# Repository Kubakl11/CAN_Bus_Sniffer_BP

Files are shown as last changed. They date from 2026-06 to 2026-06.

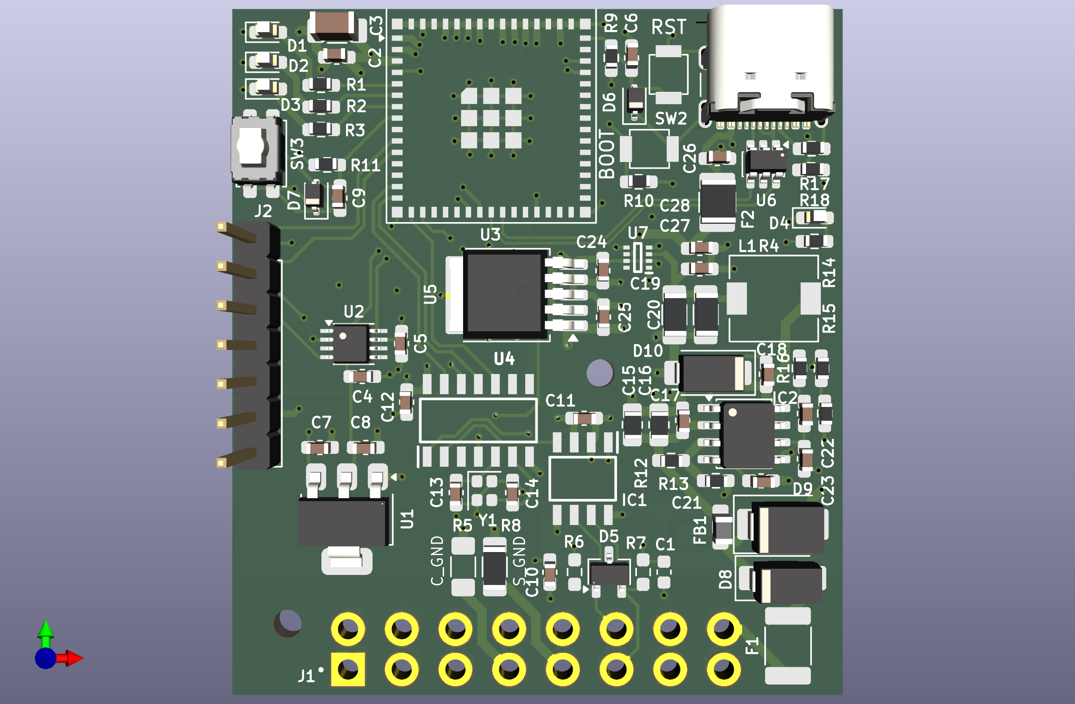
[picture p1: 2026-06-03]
pcb-design/Images/CanBus_Sniffer_v1_Front.png

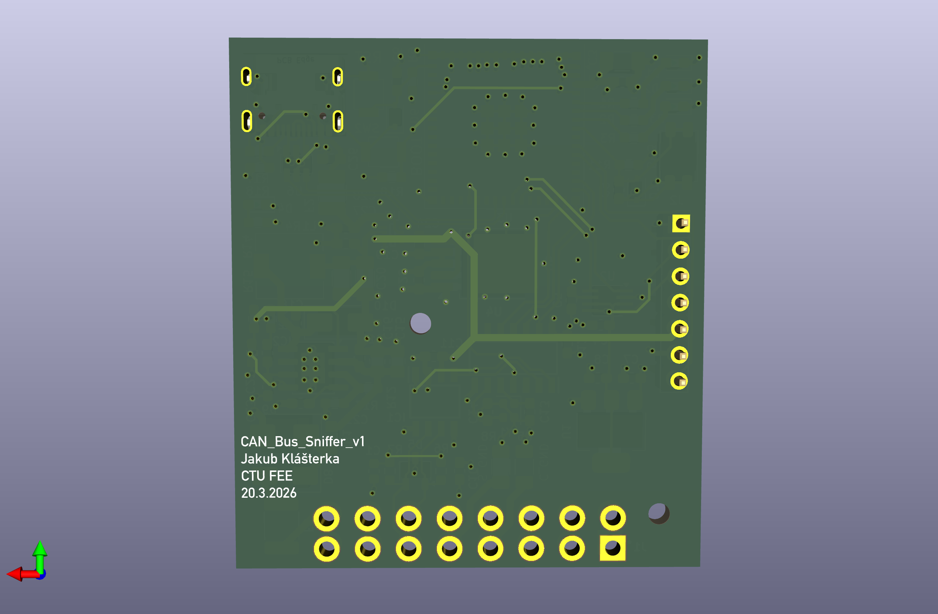
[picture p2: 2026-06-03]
pcb-design/Images/CanBus_Sniffer_v1_Back.png

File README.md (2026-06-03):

# CAN Bus Sniffer — Bachelor Thesis - Jakub Klášterka

> **Design and Implementation of a System for CAN Bus Data Analysis in Automotive Monitoring**
>
> Czech Technical University in Prague · Faculty of Electrical Engineering · 2026

---

## About

This project implements a **complete vehicle telemetry pipeline** — from reading OBD-II data off the car's CAN bus, through cellular transmission, to a live web dashboard.

```
   Vehicle CAN Bus (500 kbit/s)
       │
       ▼  OBD-II
  ┌─────────────────────────┐
  │  ESP32-S3 + MCP2518FD   │  ← Custom 4-layer PCB
  │  + A7670E LTE/GPS       │
  └────────┬────────────────┘
           │  HTTPS (LTE)
           ▼
  ┌─────────────────────────┐
  │  Flask Backend           │  ← Railway.app
  │  (REST API + SQLite)     │
  └────────┬────────────────┘
           │  fetch() @ 5 Hz
           ▼
  ┌─────────────────────────┐
  │  Web Dashboard           │  ← Chart.js + Leaflet
  │  (Vanilla HTML/CSS/JS)   │
  └─────────────────────────┘
```

---

## Hardware

| Component | Role |
|---|---|
| **ESP32-S3-MINI-1-N8** | Main MCU (dual-core, 240 MHz) |
| **MCP2518FD** | CAN controller (SPI, CAN 2.0B @ 500 kbit/s) |
| **ATA6563** | CAN transceiver (3.3 V logic / 5 V bus) |
| **SIMCom A7670E** | LTE Cat 1 modem + GNSS (GPS/GLONASS) |

PCB designed in **KiCad**,

---

## Firmware
- **CAN library:** ACAN2517FD
- **OBD-II:** PID discovery (SCAN) + cyclic reading (LOOP) at 150 ms
- **LTE:** AT command driver for A7670E — HTTPS POST with Bearer token + nonce
- **GPS:** NMEA parsing via `AT+CGNSSINFO`
- **WiFi:** SoftAP + captive portal for local configuration

## Backend

Flask app deployed on **Railway.app**.

| Endpoint | Method | Description |
|---|---|---|
| `/data` | `POST` | ESP sends OBD-II JSON (Bearer + nonce auth) |
| `/data` | `GET` | Dashboard reads latest telemetry |
| `/command` | `POST` | Queue command for ESP (SCAN / LOOP / STOP) |

**Security:** HTTPS · Bearer token · nonce replay protection

---

## Dashboard
Written using **HTML / CSS / JavaScript**

| Page | What it shows |
|---|---|
|  `dashboard.html` | Cockpit — gauges (RPM, speed), mini charts, alarms |
|  `vehicle-data.html` | Full PID table with live values |
|  `graphs.html` | Time-series charts (Chart.js) |
|  `alarms.html` | Configurable alarm thresholds |
|  `consumption.html` | Fuel consumption analytics |
|  `map.html` | Live GPS track (Leaflet + Mapbox) |
|  `diagnostic.html` | CAN frame builder, live monitor, UDS, serial console |

**Design:** Dark theme (navy + blue accent), JetBrains Mono for numerics, responsive layout.

`data.js` serves as the **single integration point** 

---

## Quick Start

```bash
# Firmware (PlatformIO)
pio run -e obd_reader -t upload
pio device monitor

# Backend (local)
pip install -r requirements.txt
flask run

# Dashboard
# Open dashboard.html with Live Server
```

---

## 📝 Thesis

Written in **LaTeX** using the `ctuthesis` template. The thesis covers a review of automotive communication buses (CAN, LIN, FlexRay, Ethernet), the OBD-II diagnostic standard, hardware design, firmware implementation, server architecture, and the web dashboard.

---

<p align="center">
  <sub>Jakub Klášterka · CTU FEE Prague · 2026</sub>
</p>

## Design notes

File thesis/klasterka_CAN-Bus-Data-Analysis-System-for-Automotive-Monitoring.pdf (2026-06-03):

## Czech Technical

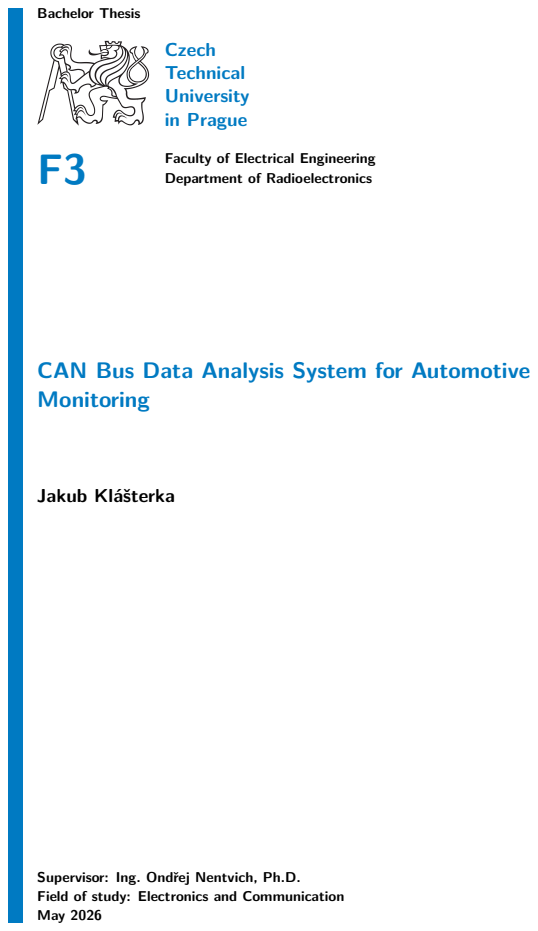
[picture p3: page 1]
Bachelor Thesis; University in Prague; Faculty of Electrical Engineering; Jakub Kláöterka

Department of Radioelectronics

CAN Bus Data Analysis System for Automotive
Monitoring

Supervisor: Ing. Ondej Nentvich, Ph.D.
Field of study: Electronics and Communication
May 2026

ii

ZADÁNÍ BAKALÁŘSKÉ PRÁCE

I. OSOBNÍ A STUDIJNÍ ÚDAJE

Systém analýzy dat ze sběrnice CAN pro monitorování automobilů

Název bakalářské práce anglicky:
CAN Bus Data Analysis System for Automotive Monitoring

Jméno a pracoviště vedoucí(ho) bakalářské práce:
Ing. Ondřej Nentvich, Ph.D. katedra radioelektroniky FEL

Jméno a pracoviště druhé(ho) vedoucí(ho) nebo konzultanta(ky) bakalářské práce:

Datum zadání bakalářské práce: 04.02.2026 | Termín odevzdání bakalářské práce: ___________
Platnost zadání bakalářské práce: 19.09.2027

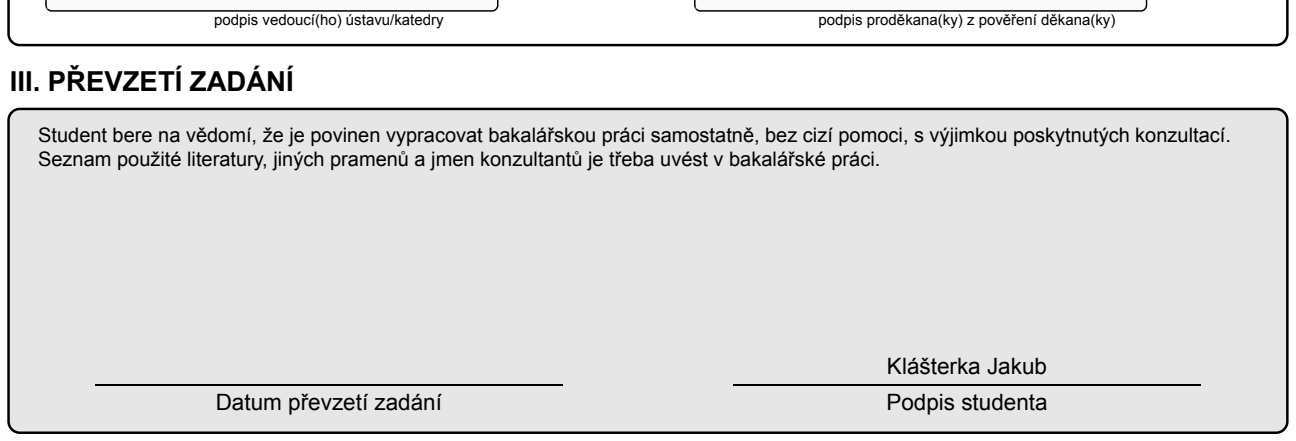
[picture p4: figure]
##SIGNATURE;FIELD;STEP1##; ##SIGNATURE;FIELD;STEP2##; podpis vedoucí(ho) ústavu/katedry; podpis proděkana(ky) z pověření děkana(ky); III. PŘEVZETÍ ZADÁNÍ; Klášterka Jakub; Datum převzetí zadání; Podpis studenta

Student bere na vědomí, že je povinen vypracovat bakalářskou práci samostatně, bez cizí pomoci, s výjimkou poskytnutých konzultací. Seznam použité literatury, jiných pramenů a jmen konzultantů je třeba uvést v bakalářské práci.

CVUT-CZ-ZBP-2015.1 | Strana 1 z 2 | © VUT v Praze, Design: VUT v Praze, VIC

ZADÁNÍ BAKALÁŘSKÉ PRÁCE

I. OSOBNÍ A STUDIJNÍ ÚDAJE

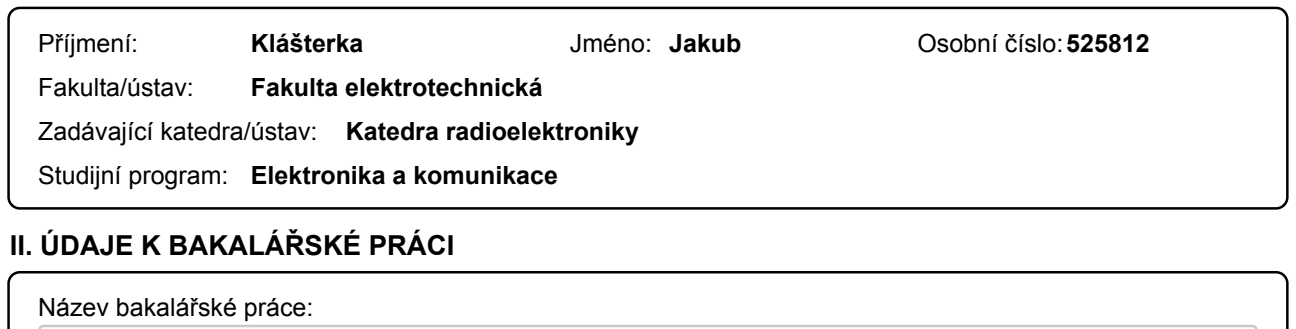
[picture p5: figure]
Příjmení:; Klášterka; Jméno:; Jakub; Osobní číslo:; Fakulta/ústav:; Fakulta elektrotechnická; Zadávající katedra/ústav: Katedra radioelektroniky; Studijní program:; Elektronika a komunikace; II. ÚDAJE K BAKALÁŘSKÉ PRÁCI; Název bakalářské práce:

Systém analýzy dat ze sběrnice CAN pro monitorování automobilů

Název bakalářské práce anglicky:
CAN Bus Data Analysis System for Automotive Monitoring

Pokyny pro vypracování:
1) Perform research on commonly used communication buses in vehicles, focusing on the CAN bus and the OBD-II diagnostic standard. The research should cover the following areas:
- Overview of commonly used buses (e.g., CAN, LIN, FlexRay, MOST, Automotive Ethernet)
- OBD-II diagnostic standard and related protocols (especially ISO 15765 and SAE J1979)
- Description of the CAN 2.0A/B protocol
- Diagnostic services and vehicle operating values
2) Review existing devices for analyzing and recording data from the CAN bus.
3) Design a device capable of recording data from the CAN bus via the OBD-II diagnostic connector and storing this data in local or cloud storage.
4) Design a method for visualizing the acquired data using a graphical display or web interface, implemented either directly on the microcontroller or via remote storage. The visualization should include key vehicle diagnostic and operating data.
5) Analyze the security risks of the designed device and propose appropriate measures to ensure data protection and bus integrity.

Seznam doporučené literatury:
[1]PARET, Dominique. Multiplexed Networks for Embedded Systems: CAN, LIN, FlexRay, Safe-by-Wire.. John Wiley, 2007. ISBN 978-0-470-51170-1.
[2]KLEIDERMACHER, David a KLEIDERMACHER, Mike. Embedded systems security: practical methods for safe and secure software and systems development. Amsterdam: Elsevier, 2012. ISBN 978-0-12-386886-2.
[3] ZÁHLAVA, Vít. Návrh a konstrukce desek plošných spojů: principy a pravidla praktického návrhu. Praha: BEN - technická literatura, 2010. ISBN 978-80-7300-266-4.
[4] Mastering MQTT – Your Ultimate Tutorial for MQTT [online]. Available from: https://assets.emqx.com/resources/ebooks/Mastering%20MQTT-Your%20Ultimate%20Tutorial%20for%20MQTT.pdf
CVUT-CZ-ZBP-2015.1 | Strana 2 z 2 | © VUT v Praze, Design: VUT v Praze, VIC

FAKULTA ELEKTROTECHNICKÁ
FACULTY OF ELECTRICAL ENGINEERING Technická 2
166 27 Praha 6

### DECLARATION

I, the undersigned

Student's surname, given name(s): Kláterka Jakub
Personal number: | 525812
Programme name: | Electronics and Communications

hereby declare that the Bachelor’s Thesis titled

CAN Bus Data Analysis System for Automotive Monitoring

is my own independent work and that I have declared all sources of information used in accordance with the Methodological Guideline for adhering to ethical principles when elaborating an academic final thesis and the Framework Rules for the use of artificial intelligence at CTU for study and pedagogical purposes in Bachelor and continuing Masters studies.

I declare that I have used artificial intelligence tools during the preparation and writing of the final thesis.
I've verified the generated content. I confirm that I am aware that I am fully responsible for the content of the final thesis.
In Prague on 03.05.2026 | Jakub Kláterka | student's signature

vi

## Acknowledgements

I would like to thank my supervisor, Ing. Ondej Nentvich, Ph.D., for his invaluable guidance and continuous support throughout this thesis, often helping me outside of his regular working hours, including weekends. I am grateful for his empathy, knowledge, and eagerness to help with all the diculties encountered during the work.
I would also like to thank my external supervisor,
Ing. Ludmila Musalová Stoklasová, from the Technical Development Department at äkoda Auto, for her guidance and consultations.
Finally, I am grateful to my colleagues for their assistance and valuable advice while working on this Bachelor thesis.

## Podkování

Chtl bych velice podkovat svému vedoucímu, Ing. Ondeji Nentvichovi, Ph.D., za jeho odborné vedení a neustálou podporu v prbhu celé práce, i nad rámec jeho pracovních hodin a bhem víkend. Velmi si váûím jeho vstícnosti, odborn˝ch znalostí a ochoty pomoci pi eöení vöech obtíûí, s nimiû jsem se bhem její tvorby setkal.
Dále také dkuji své externí konzultantce, Ing. Ludmile Musalové Stoklasové z oddlení technického v˝voje spolenosti äkoda Auto, za její vedení a konzultace. Na závr dkuji sv˝m kolegm za pomoc a cenné rady pi tvorb této bakalá-ské práce.

vii

## Abstract

The Bachelor thesis focuses on developing a prototype of a diagnostic device for vehicle telematics which can monitor vehicle data in real time wirelessly on a web dashboard. The prototype device contains a custom-designed PCB with an ESP32-S3 microcontroller, a CAN FD controller, a SIMCom external LTE & GPS module, and a TPS54331 power supply.
The theoretical part contains a discussion of the OBD-II standards and specifications, and the CAN bus protocol architecture. A comparison of several dierent automotive communication buses, including FlexRay, LIN, and Automotive Ethernet, is provided as a foundation for understanding the automotive environment. There is also a marketing overview of existing diagnostic devices.
The practical part of the thesis demonstrates the custom PCB design of the device, firmware development, server setup, and the whole setup of the device, including LTE initialization, reading CAN messages, and providing steps for security measures and power management. It also describes the developed dashboard for the visualization of vehicle data and the validation of the acquired data. The thesis also oers an idea for future implementation of a diagnostic interface for flashing vehicle electronic control units.
Keywords: ESP32, CAN bus, OBD-II, automotive diagnostics, microcontroller, PCB design, web server, wireless technology
Supervisor:
Ing. Ondej Nentvich, Ph.D. Department of Radioelectronics, Faculty of Electrical Engineering, CTU Prague

## Abstrakt

Bakaláská práce se zamuje na v˝voj prototypu diagnostického zaízení, které dokáûe bezdrátov sledovat telematická data z vozidla a vizualizovat je pomocí webového rozhraní. Prototyp zahrnuje vlastní v˝voj desky ploön˝ch spoj s mikrokontrolérem ESP32-S3, CAN FD pevodníkem, externím LTE a GPS modulem SIMCom a napájecím zdrojem TPS54331. Teoretická ást se vnuje popisu standard a specifikací OBD-II a architektue protokolu CAN bus. Obsahuje také srovnání nkolika rzn˝ch komunikaních sbrnic ve vozidle, vetn FlexRay, LIN a Automotive Ethernet, jako základ pro pochopení prmyslov˝ch standard v automotive prostedí. Tato ást pináöí také trûní pehled existujících diagnostick˝ch zaízení.
Praktická ást popisuje návrh vlastní desky ploön˝ch spoj (DPS), v˝voj firmwaru, pípravu serveru a celkovou konfiguraci zaízení. Ta zahrnuje inicializaci LTE komunikace, vyítání zpráv ze sbrnice CAN, eöení softwarového zabezpe-ení a ízení spoteby energie. Dále je zde popsán v˝voj webového rozhraní pro vizualizaci namen˝ch dat a jejich validace. Práce také obsahuje moûnost budoucího rozöíení systému, spoívající v implementaci diagnostického rozhraní pro kódování elektronick˝ch ídicích jednotek.
Klíová slova: ESP32, sbrnice CAN, OBD-II, automobilová diagnostika, mikrokontrolér, návrh DPS, webov˝ server, bezdrátové technologie
Peklad názvu: Systém anal˝zy dat ze sbrnice CAN pro monitorování automobil

viii

## Contents

1 Introduction | 1
2 Theoretical Background | 3

2.1.1 History and Development . . . . 3 2.1.3 CAN Message Frame Structure 7 2.1.4 Reading and Decoding CAN

2.1.7 Typical ECUs in Vehicles . . . 14 2.1.8 Vehicle Network Architecture 14 2.1.9 Other Serial Buses in Vehicles 15 2.2.1 Overview and Standardization 18 2.2.2 OBD II Physical Connector . 19 2.3 Market Analysis of Existing

### 3 Design and Implementation of the

Device | 25

3.2.1 System Requirements and

3.3.3 CAN Controller Initialization 37

3.5.2 Local Wi-Fi Channel Security 45

3.6.2 Advanced Diagnostics Interface 48 3.7.1 End-to-End Transmission Test 49 3.7.2 Vehicle CAN Communication 51

4 Conclusion | 59
Bibliography | 61
A Component Datasheets | 65
B Complete Hardware Schematic 67
C Dashboard Screens | 71

Advanced Diagnostics Interface . . . . 78 D Test Drive Cockpit Photographs 83

Full-Throttle Acceleration to 100

E Repository Structure | 85
F Usage of Artificial Intelligence
tools | 87

ix

## Figures

2.1 CAN protocol architecture [20] .. 4 2.2 CAN bus topology architecture [4] 5 2.3 CAN bus dierential voltage
levels [5] | 6
2.4 CAN bus data frame [39] ....... 8 2.5 Cyclic Redundancy Check
diagram [21] | 9
2.6 Engine control unit [25]........ 13 2.7 ECUs topology in a car [27].... 13 2.8 ECU topology in vehicle [26] (bus layout is for illustration only) . . . . 14 2.9 OBD-II most common
locations [37] | 19
2.10 OBD-II Connector pinout [9].. 19 2.11 OBDeleven diagnostic
dongle [22] | 22
2.12 Generic ELM327 Bluetooth
adapter [17] | 23
2.13 SIZZAPP 4G GPS OBD
tracker [30] | 23
2.14 T-Mobile Smart Car OBD-II
device [15] | 24
3.1 CAN Bus Snier block diagram. 28 3.2 PCB layout of 4-layer board . . . 32 3.3 PCB layout showcasing the short high-frequency current loop path . 32
3.4 Main loop flow diagram | 36
3.5 Illustration photos of LTE antenna (left)[34] and GNSS antenna
(right)[36] | 40
3.6 Main Cockpit screen featuring live radial gauges and summary widgets 47 3.7 Recorded engine speed and vehicle
speed over the test session | 52
3.8 Throttle position, engine load, and
intake manifold pressure | 53
3.9 Coolant temperature, intake air temperature, ambient temperature,
and mass air flow rate | 53
3.10 Current draw during LTE module initialization and TCP payload
transmission | 54
3.11 System power consumption comparison between light sleep
and deep sleep modes | 55

C.1 Cockpit screen — live radial
gauges and summary widgets | 72
C.2 Vehicle Overview screen — PID
values and CSV export | 73
C.3 Live Graphs screen — time series
plots with zoom support | 74
C.4 Fuel Consumption screen — instantaneous and average counters 75 C.5 GPS Map screen — real-time vehicle position and route export . 76 C.6 Alarms screen — configurable
threshold limits | 77
C.7 Login screen — access restriction
for the diagnostics interface | 78
C.8 Diagnostic interface | 79
C.9 Serial Monitor | 80
C.10 UDS & Coding — ISO-TP
request builder | 80
C.11 Live monitor — real-time CAN
trac display | 81
D.1 Instrument cluster during
45 km h≠1 cruise | 83
D.2 Instrument cluster during full-throttle acceleration to
100 km h≠1 | 84
D.3 Instrument cluster during
50 km h≠1 steady-state cruise | 84
D.4 Instrument cluster during stationary high-RPM engine run . . 84

x

## Tables

2.1 Comparison of CAN Protocol
Variants | 12
2.2 Common OBD-II Standard PIDs 20 3.1 Key features of the
ESP32-S3-MINI-1 module (N8
variant) | 26
3.2 ESP32-S3 GPIO Pin Assignment
by Functional Block | 33
3.3 REST API Endpoints | 41
3.4 Dashboard Screen Overview . . . . 46 3.5 OBD-II parameters acquired
during the test drive | 51
3.6 Measured current draw per
operating phase | 57
3.7 Projected cellular data
consumption (4 h/day, n =9 PIDs). 58
E.1 Repository Structure | 85

xi

xii

## List of Abbreviations

Abbreviation | Description
ADAS | Advanced Driver Assistance Systems
ADC | Analog-to-Digital Converter
AP | Access Point
API | Application Programming Interface
AT | Attention (standard modem command prefix)
BOM | Bill of Materials
BCM | Body Control Module
CARB | California Air Resources Board
CGW | Central Gateway
CPU | Central Processing Unit
DNS | Domain Name System
DNP | Do Not Populate
DTC | Diagnostic Trouble Code
EMI | Electromagnetic Interference
EOBD | European On-Board Diagnostics
ESD | Electrostatic Discharge
FIFO | First-In, First-Out
FSM | Finite State Machine
GPIO | General-Purpose Input/Output
GPRS | General Packet Radio Service
GPS | Global Positioning System

xiii

Abbreviation | Description
GPX | GPS Exchange Format
GSM | Global System for Mobile Communications
HVAC | Heating, Ventilation, and Air Conditioning
IC | Inter-Integrated Circuit
IDE | Identifier Extension
ISO | International Organization for Standardization
ISO-TP | ISO Transport Protocol (ISO 15765-2)
ISR | Interrupt Service Routine
JSON | JavaScript Object Notation
LDO | Low-Dropout Regulator
LiDAR | Light Detection and Ranging
LTE | Long Term Evolution
MAC | Medium Access Control
MAF | Mass Air Flow
MAP | Manifold Absolute Pressure
OSI | Open Systems Interconnection
PCB | Printed Circuit Board
PID | Parameter Identifier
PWM | Pulse Width Modulation
QFN | Quad Flat No-leads
RAM | Random Access Memory
REST | Representational State Transfer
RMT | Remote Control Peripheral
ROM | Read-Only Memory
RTR | Remote Transmission Request
SAE | Society of Automotive Engineers
SIM | Subscriber Identity Module
SPI | Serial Peripheral Interface
SRAM | Static Random-Access Memory
SSID | Service Set Identifier

xiv

Abbreviation | Description
TDM | Time-Division Multiplexing
TLS | Transport Layer Security
TWAI | Two-Wire Automotive Interface
UART | Universal Asynchronous Receiver-Transmitter
UDS | Unified Diagnostic Services
UTP | Unshielded Twisted Pair
VAG | Volkswagen Aktiengesellschaft
WPA2-PSK | Wi-Fi Protected Access 2 — Pre-Shared Key

xv

## Chapter 1 Introduction

In the modern automotive industry, the usage of electronic control units (ECUs) and standardized communication protocols is essential for diagnostics and monitoring.
The On-Board Diagnostics II (OBD-II) standard, which has been required in all vehicles since 1996, provides a standard interface that allows access to vehicle data and diagnostic information through the use of the Controller Area Network (CAN) bus protocol. This bachelor thesis details the design of a diagnostic tool utilizing an ESP32 microcontroller to communicate with the OBD-II interface of vehicles utilizing the CAN bus protocol.
This diagnostic prototype allows real-time tracking of vehicle diagnostics and provides visualized data via a web-based dashboard.

## 1.1 Motivation

The motivation for creating this thesis is driven by several factors:

. Cost-eective diagnostics solutions for automotive monitoring.
. Learning and education — the need for modern electrical engineering

students to understand automotive communication protocols.

. Fleet management applications — providing real-time monitoring of ve-

hicle diagnostics, allowing better fleet maintenance and eciency.

## 1.2 Objectives

. Research the OBD-II standard and CAN bus protocol architecture.
. Design the hardware interface to connect the ESP32 to the CAN bus

communication.

. Implement software to read and convert raw data to specific vehicle

parameters.

. Develop a web-based dashboard to present remote data.

1

2

## Chapter 2 Theoretical Background

## 2.1 Controller Area Network

The Controller Area Network (CAN) is a serial communication bus designed for robust message exchange between Electronic Control Units (ECUs). It was initially engineered for the automotive environment, where the protocol uses a multi-master architecture in which devices broadcast messages to the entire network without a central host computer. This decentralized approach serves as the vehicle’s nervous system, enabling components such as engine management, transmission control, and safety systems to share sensor data in real time. While developed for combustion-engine vehicles, the protocol serves as the networking standard for electric vehicles, marine electronics, and industrial automation [6].

### 2.1.1 History and Development

In the early 1980s, the automotive industry faced a critical engineering challenge known as the "wiring harness crisis". As manufacturers integrated electronic features such as Anti-lock Brake Systems (ABS), electronic fuel injection, and power windows, the reliance on point-to-point analog wiring became unsustainable. By 1983, the wiring harness in luxury vehicles weighed over 50 kg and spanned kilometers, making it the third-heaviest and most expensive component in the assembly [3]. This complexity introduced manufacturing diculties and reliability issues caused by connector corrosion. An innovative solution was introduced by Robert Bosch GmbH,¹ initiating the CAN protocol in 1983 [3]. The solution consisted of replacing individual wiring with a single twisted-pair bus system, thereby reducing weight and complexity while maintaining high noise immunity. Intel produced the first CAN controller chip, the 82526, in 1987, followed by the Philips 82C20 [2]. The technology entered mass production in 1991 with the Mercedes-Benz W140 S-Class, which utilized the bus to interconnect the engine management and transmission control units.

1
Gesellschaft mit beschränkter Haftung, the German form of a limited liability company.

3

# 2. Theoretical Background |

### 2.1.2 Network Architecture

The CAN bus is a multi-master serial line that uses dierential signaling to determine the logical level of the transmitting signal. The architecture refers to the ISO/OSI Reference Model, specifically implementing the Physical Layer and Data Link Layer. The transmission lines are designated as CAN_L (CAN Low) and CAN_H (CAN High).
The protocol is internationally standardized under the ISO 11898 series:

. Data Link Layer (ISO 11898-1): Governs the logical handling of mes-

sages, including frame construction, error detection, and the arbitration logic that manages bus access.

. Physical Layer (ISO 11898-2): Specifies the electrical characteristics

of the signals and the physical medium, which consists of two transmission lines designated as High and Low [6].

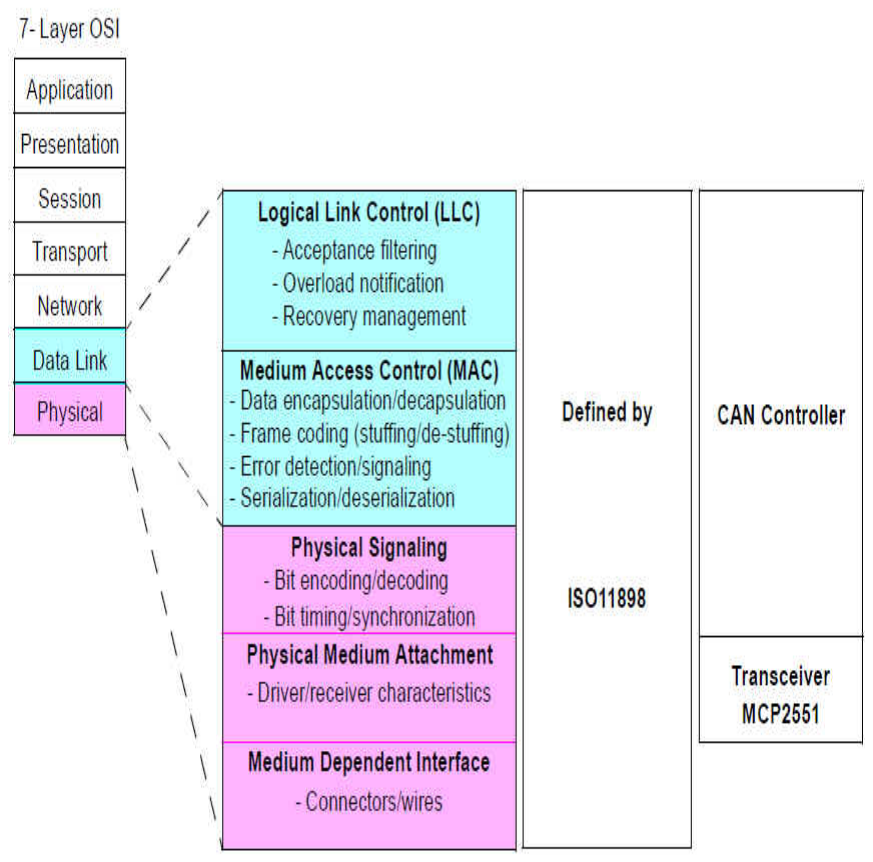
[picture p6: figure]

Figure 2.1: CAN protocol architecture [20]

4

# | 2.1. Controller Area Network

Bus Topology
As mentioned before, the CAN bus is a multi-master line. It is designed in a bus topology, which has some key advantages over widely used star topology solutions. The star topology is often used for single-master applications, such as SPI or in many network topology solutions. In contrast, as a multi-master bus, CAN uses a 2-wire bus topology where every component is attached and each node can serve as master or slave, depending on whether it is requesting or sending data. Bus topology provides significant wiring savings. Each node consists of a Microcontroller, a CAN Controller, and a CAN Transceiver:

. Microcontroller (MCU): The "brain" of the node that interprets

received data and decides what information to transmit (Speed, RPM, etc.).

. CAN Controller: Often integrated into the MCU, managing bit rep-

resentation, error handling, and message buering according to ISO 11898-1.

. CAN Transceiver: Acts as the interface between the controller and phys-

ical bus. It converts digital logic into dierential electrical signals [35].

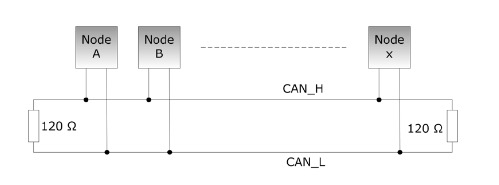
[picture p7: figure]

Figure 2.2: CAN bus topology architecture [4]

5

# 2. Theoretical Background |

Physical Layer
The Physical Layer is responsible for the actual electrical transmission of data over the CAN bus medium. It defines the voltage levels, signal timing, and physical characteristics of the bus.
The key advantage of the dierential bus is its immunity to Electromagnetic Interference (EMI). When a receiving node determines the voltage level on the line, it utilizes the dierential voltage Vdif f between VCAN_H and VCAN_L, as shown in Equation 2.1:
Vdif f = VCAN_H ≠ VCAN_L | (2.1)
This mechanism ensures that potential signal distortion aects both lines equally, eectively canceling out the interference. The dierential voltage levels are illustrated in Figure 2.3. As a serial data bus, correct impedance matching is critical to avoid signal reflections. The characteristic impedance of a standard CAN bus cable is 120 ; termination resistors at both ends of the bus must therefore match this value. Placing two 120 termination resistors, denoted as R1 and R2, at the ends of the bus, results in a parallel equivalent resistance Rterm of 60 , as derived by Equation 2.2:

Rterm = R1 · R2
R1 + R2

= 120 · 120
120 + 120 = 60 | (2.2)

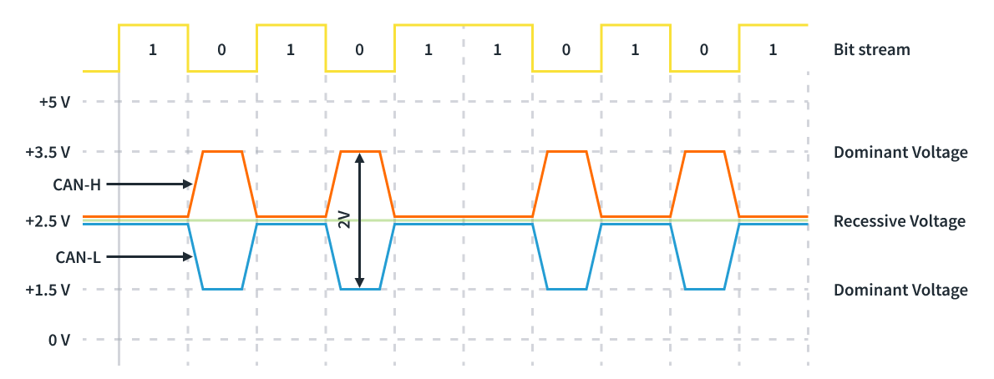
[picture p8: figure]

Figure 2.3: CAN bus dierential voltage levels [5]

6

# | 2.1. Controller Area Network

Data Link Layer
The Data Link Layer, defined by ISO 11898-1, manages frame construction, bus access arbitration, and error detection. It is functionally divided into two sub-layers: Logical Link Control (LLC) and Medium Access Control (MAC).

. Logical Link Control: The LLC sub-layer manages message filtering

and acceptance. It determines which received messages are relevant to the host MCU based on the message Identifier (ID). Additionally, it handles overload notifications [7].

. Medium Access Control: The MAC sub-layer controls the core

protocol rules:

. Arbitration: Manages non-destructive bitwise arbitration using

CSMA/CD+AMP.

. Frame Coding: Performs bit stung, inserting a complementary bit

after every five consecutive identical bits [18].

. Error Detection: Implements error checking through Cyclic Redun-

dancy Check (CRC) calculation.

### 2.1.3 CAN Message Frame Structure

Bus States and Bit Levels
To understand the operation of CAN frames, it is essential to examine how bits are represented on the bus. The CAN protocol utilizes two distinct states: Dominant bit (logic 0): CAN_H goes to about 3.5 V while CAN_L drops to 1.5 V, making a dierential voltage of roughly 2 V. It is called "dominant" because it electrically overpowers the recessive state.
Recessive bit (logic 1): Both lines stay at around 2.5 V, so the dierential voltage is nearly 0 V. This is "recessive" because a dominant bit from any node will override it [18].
When multiple nodes try to transmit at once, this dominant/recessive setup is what makes arbitration work – dominant bits always override recessive bits on the shared line.
Message-Based Communication
The CAN protocol is based on message-framed communication. Each frame has an ID that specifies what the message consist of, not who sent it or where it is going. Nodes filter messages by content – they only pay attention to what matters to them. ISO 11898-1 defines four frame types: Data Frames, Remote Frames, Error Frames, and Overload Frames. Two formats are used: Standard Frame (CAN 2.0A) with an 11-bit ID, or Extended Frame (CAN 2.0B) with a 29-bit ID for more complex protocols like SAE J1939 [6].

7

# 2. Theoretical Background |

Standard Data Frame Fields
According to [24], a standard CAN Data Frame has seven fields, illustrated in the waveform in Figure 2.4.

.1. Start of Frame (SOF): A single dominant bit (0) that marks the start

of transmission and synchronizes all nodes.

.2. Arbitration Field: Contains the 11-bit Identifier and RTR bit. The ID

determines priority – lower values mean higher priority due to the wired-AND logic. The RTR (Remote transmission request) bit is dominant (0) for Data Frames and recessive (1) for Remote Frames.

.3. Control Field: Includes the IDE bit (dominant for Standard Frames),

a reserved bit (r0), and the 4-bit Data Length Code (DLC) that specifies payload size (0–8 bytes).

.4. Data Field: The actual payload, transmitted MSB first, from 0 to 8 bytes. .5. CRC Field: A 15-bit Cyclic Redundancy Check followed by a recessive

delimiter. The transmitter calculates the CRC using the polynomial number.

.6. ACK Field: Contains the ACK Slot and delimiter. The transmitter

sends a recessive bit, which gets overwritten by a dominant bit if any node successfully receives the frame [24].

.7. End of Frame (EOF): Seven consecutive recessive bits marking the end

of transmission.

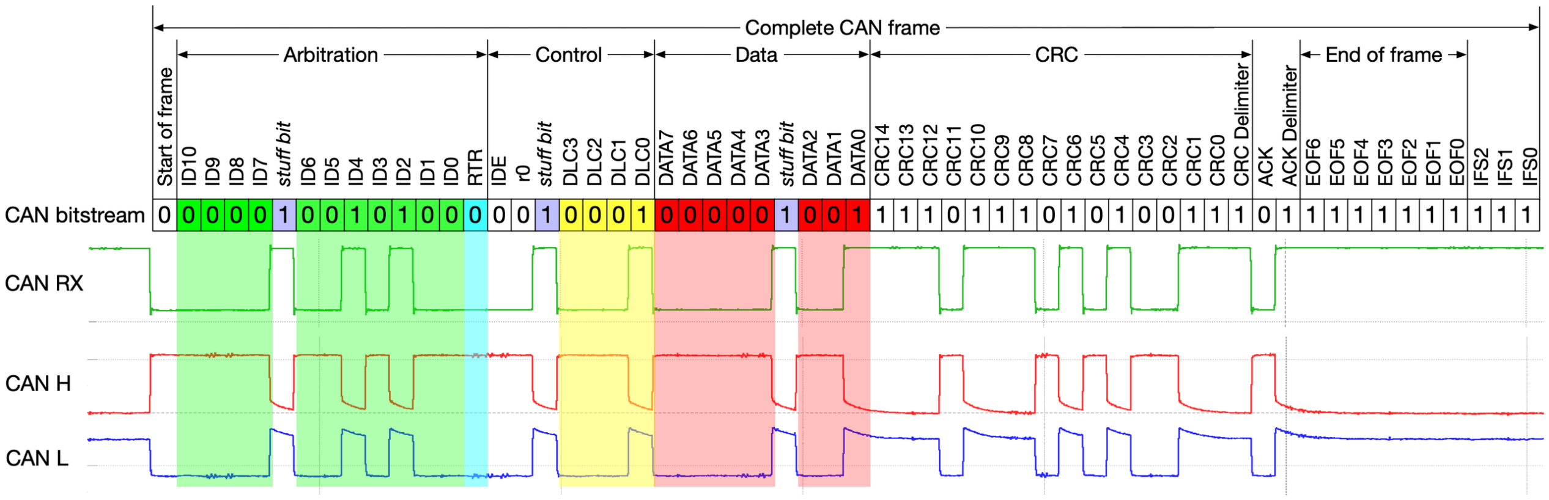
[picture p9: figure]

Figure 2.4: CAN bus data frame [39]

8

# | 2.1. Controller Area Network

Cyclic Redundancy Check
The CRC detects transmission errors using polynomial math. The transmitter calculates a 15-bit checksum with the generator polynomial from ISO 11898-1:
G(x)= x15 + x14 + x10 + x8 + x7 + x4 + x3 +1 | (2.3)
Mathematical principle
CAN represents data bits as polynomials - each bit position becomes a term. For example, if you have the bit sequence 10110, it translates to:
M(x)= x4 + x2 + x | (2.4)
The CRC calculation has three steps:

.1. Take the message polynomial and multiply it by x15 (basically shifting

it left by 15 bits)

.2. Divide this by the generator polynomial using modulo-2 math:

x15 · M(x)
G(x) = Q(x)+ R(x)
G(x) | (2.5)
where Q(x) is what you get from the division and R(x) is what’s left over

.3. That leftover part R(x) becomes your 15-bit CRC [24].

Modulo-2 arithmetic just means using XOR operations - so 1+1 = 0 and 1+0 = 1, with no carrying between bits. When a node receives the frame, it does the same division on all the data including the CRC. If everything transmitted correctly, the remainder comes out to zero. Any other result means there’s an error somewhere.

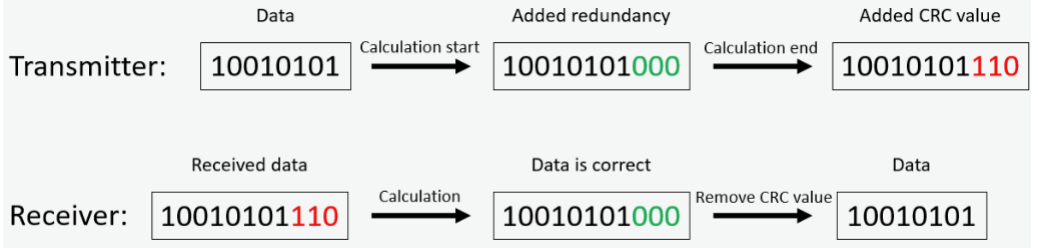
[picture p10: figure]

Figure 2.5: Cyclic Redundancy Check diagram [21]

Extended Data Frame Dierences
The Extended Frame (CAN 2.0B) mainly diers in the Arbitration Field. It uses a 29-bit Identifier split into an 11-bit Base ID and 18-bit Extended ID. The IDE bit is recessive (1) to distinguish it from Standard Frames, and an SRR (Substitute Remote Request) bit replaces the RTR bit in the first part of the field.

9

# 2. Theoretical Background |

Bit Stung
CAN uses bit stung to keep nodes synchronized. From the SOF through the CRC, whenever five consecutive identical bits appear, the transmitter automatically inserts a complementary bit (stu bit). This ensures regular signal transitions for clock recovery and prevents data from being confused with error frames or EOF sequences.

Message Arbitration and Priority
CAN uses CSMA/CD+AMP (Carrier Sense Multiple Access with Collision Detection and Arbitration on Message Priority) to handle bus access. When multiple nodes try to transmit at the same time, the system resolves the conflict without losing data - the highest priority message keeps transmitting while others back o.
Bitwise Arbitration
The arbitration works because of the bus’s wired-AND logic: a Dominant bit (0) always overwrites a Recessive bit (1). When the bus is idle, several nodes can start transmitting their Start of Frame simultaneously. As they send their Identifier bits one by one, each node monitors the bus to check if what it’s sending matches what’s actually on the line.
If a node sends a Recessive bit (1) but sees a Dominant bit (0) on the bus, it knows another node is sending a higher priority message. That node immediately stops transmitting and switches to receive mode to listen to the winning message. This happens in real-time during the arbitration field.
Message Priority
Since Dominant bits (0) overwrite Recessive bits (1), messages with lower binary IDs have higher priority. For example, a node sending ID 0x100 will win against one sending 0x110 because at the first diering bit position, the 0 dominates the 1. This ensures safety-critical messages (like engine timing or ABS data) always get through before less important ones (like infotainment) [14, 10].

10

# | 2.1. Controller Area Network

### 2.1.4 Reading and Decoding CAN Messages

CAN is message-based, not address-based like TCP/IP. Frames are not sent to specific nodes - instead, the Identifier defines what the message contains, and it’s broadcast to everyone on the network [35].

Hardware Filtering
Every node physically receives every message on the bus, so there needs to be a way to filter out irrelevant data. The CAN controller handles this using Acceptance Filters and Masks. It compares incoming message IDs against configured filters - if there’s a match, the message goes into a buer and triggers an interrupt for the microcontroller. Non-matching messages get discarded at the hardware level, which saves processing power.

Decoding Raw Data
The data field in a CAN frame contains up to 8 bytes of raw hexadecimal data that isn’t human-readable. To make sense of it, you need to decode it into actual engineering values (RPM, temperature in °C, speed in km h≠1, etc.). This is usually done with a CAN Database (DBC) file, which provides the decoding rules.
To extract a specific signal from the raw payload, you need:

.1. Bit Start and Length: Where the signal sits within the 64-bit data

field

.2. Byte Order: Whether it’s Intel (Little-Endian) or Motorola (Big-

Endian) format

.3. Scaling and Oset: Convert the raw value to physical units using:

Physical Value =(Raw Value ◊ Scale)+ Oset (2.6)

For example, if the raw 8-bit value for Engine Speed is 0x32 (decimal 50), with a scaling factor of 1 and oset of 0, the decoded value is 50 RPM [7].

11

# 2. Theoretical Background |

### 2.1.5 CAN Protocol Variants

The CAN protocol exists in several variants, each developed for specific application requirements — from fault-tolerant body electronics to high-speed powertrain control. Beyond the automotive industry, CAN bus is widely used in robotics, marine electronics, and industrial automation.

. Low-Speed CAN (ISO 11898-3) — used in body electronics where re-

liability matters more than speed. If one of the bus wires gets cut or shorts to ground, the transceivers automatically switch to single-wire mode. Operates between 40 kbit/s and 125 kbit/s.

. High-Speed CAN (ISO 11898-2) — the most common variant,

used in powertrain and chassis systems and forming the physical layer for OBD-II, SAE J1939, and CANopen. Runs up to 1 Mbit/s [7].

. CAN FD (ISO 11898-1:2015) — developed for EVs and ADAS

requiring higher bandwidth with up to 8 Mbit/s. It can be increased from 8 bytes to during the data phase and payload 64 bytes [12].

. CAN XL (ISO 11898-1:2024) — bridges CAN FD and Automotive

Ethernet in zonal architectures. Oers speeds of 10–20 Mbit/s and payload up to 2048 bytes, supporting TCP/IP encapsulation directly in CAN XL frames [41].
A comparison of all variants is provided in Table 2.1.
Table 2.1: Comparison of CAN Protocol Variants
Feature | Low-Speed CAN | High-Speed CAN | CAN FD | CAN XL
Standard (ISO) | 11898-3 | 11898-2 | 11898-1:2015 | 11898-1:2024
Speed | 125 kbit/s | Up to 1 Mbit/s 5–8 Mbit/s | 10–20 Mbit/s
Payload | 8 bytes | 8 bytes | 64 bytes | 2048 bytes
Usage | . BCM . Lighting . HVAC

. Powertrain
. ABS, ECU
. OBD-II

. EVs, ADAS
. ECU flashing

. Zonal arch.
. Ethernet

bridge

Key
Features

. Fault-

tolerant

. Low cost
. Robust

. High payload
. High speed

. Highest

payload

. Highest

speed

12

# | 2.1. Controller Area Network

### 2.1.6 Electronic Control Unit

An Electronic Control Unit (ECU) is the brain of a vehicle - it reads sensor data and tells components what to do. Modern cars can have up to 120 ECUs, each controlling something specific like the engine, transmission, brakes, or climate control. Inside each ECU is a microcontroller running software that processes sensor data and sends commands to actuators that actually make things happen [13].
ECUs communicate through serial buses, with CAN bus being the most common. This allows dierent systems to share information without complex wiring. The Central Gateway (diagnostic code 0x0019) acts as the main hub, routing and filtering data between dierent bus networks and connecting to the OBD-II port for external diagnostic access.

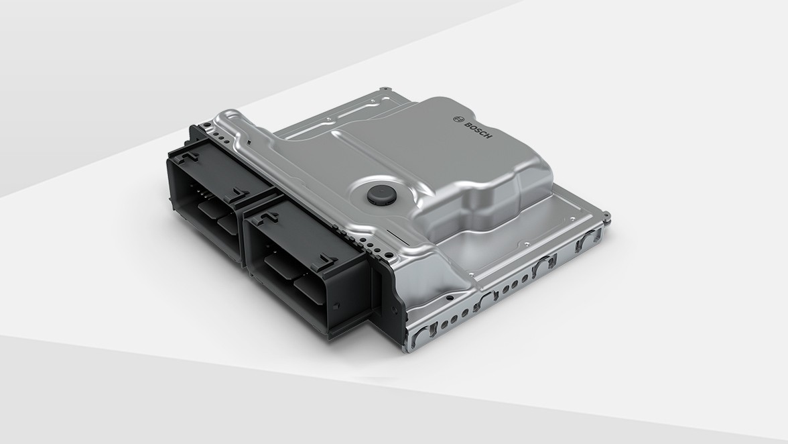
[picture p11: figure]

Figure 2.6: Engine control unit [25]

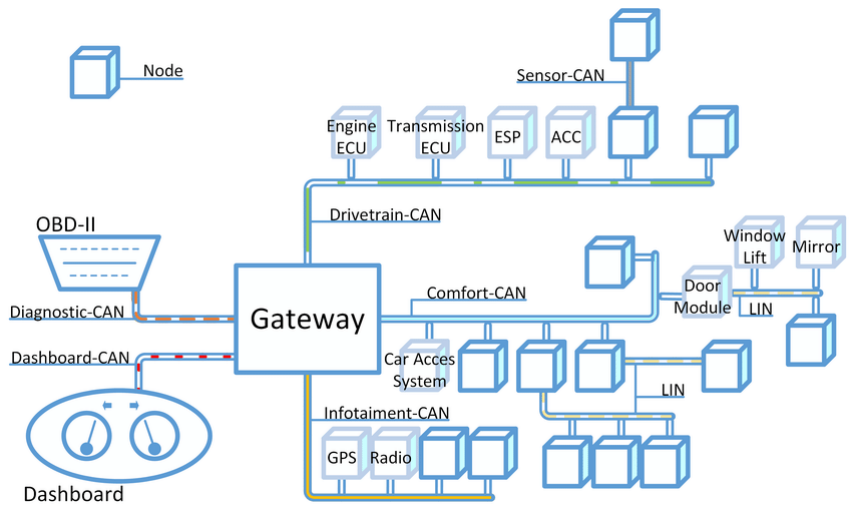
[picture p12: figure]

Figure 2.7: ECUs topology in a car [27]

13

# 2. Theoretical Background |

### 2.1.7 Typical ECUs in Vehicles

. ECM - Engine Control Module — main powertrain controller han-

dling fuel injection and ignition timing over High-Speed CAN [7]

. TCU - Transmission Control Unit — manages transmissions by mon-

itoring vehicle speed and engine load, coordinating with the ECM over the powertrain CAN bus

. BCM - Body Control Module — controls comfort features via Low-

Speed CAN (ISO 11898-3) or LIN bus [7]

. OCU - Onboard Connectivity Unit — handles GPS, cellular data,

and Wi-Fi, tied to the Central Gateway to prevent unauthorised access

. BMS - Battery Management System — monitors battery state

of charge, health, and cell temperatures in EVs, often using CAN FD

. CGW - Central Gateway — routes trac between bus networks

and serves as the only externally accessible module via the OBD-II port [7]

### 2.1.8 Vehicle Network Architecture

The vehicle network uses a hierarchical topology. At the top, the Central Gateway connects all vehicle networks, each dedicated to a specific domain:

. Powertrain CAN - Green — engine control, transmission, fuel system . Chassis CAN - Red — ABS, ESP, steering, suspension
. Body/Comfort CAN - Dark blue — door modules, climate, lighting . Infotainment - Light blue — multimedia, navigation, connectivity

Domain controllers communicate with the Gateway over High-Speed CAN, while slave modules use lower-cost protocols, such as LIN bus [7].

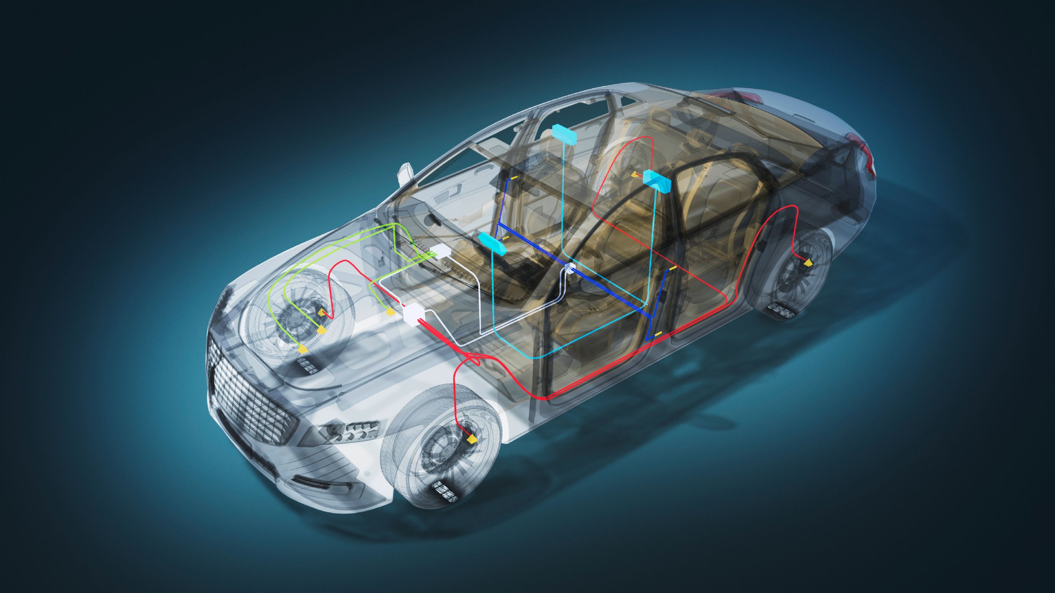
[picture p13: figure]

Figure 2.8: ECU topology in vehicle [26] (bus layout is for illustration only)

14

# | 2.1. Controller Area Network

### 2.1.9 Other Serial Buses in Vehicles

The automotive industry has an array of serial busses beyond just CAN. However, there exist multiple other common forms of automotive communications found throughout the entire vehicle architecture.

Local Interconnect Network
LIN is a single wire interface wired at 12 volts with ground; whereas CAN operates at mean dierential using two wire pairs. It is designed as a master/slave architecture where one master (generally tied into the main CAN network) controls communication with up to 16 slave devices.
Speed: LIN supports data rates from 1 Kbps to 20 Kbps, using a time scheduled message instead of a competition based arbitration system - the master performs all of the scheduling for data sending times for all devices on a LIN Network.
Usage: LIN is best used in Body Control applications such as power windows, outside mirrors, locks and HVAC actuators. Generally speaking, the functions provided by LIN devices consist mainly of low-speed, non-safety-critical mechanical actuators. LIN provides significant cost savings due to its simplified wiring and the reduced number of components required, with no licensing fee associated with any LIN applications [7].

Automotive Ethernet
Today’s vehicles encounter limitations in bandwidth, as the sheer volume of data created by advanced cameras, LiDAR sensors and high-resolution displays has reached an overwhelming level for traditional buses. From this reason, automotive manufacturers have begun deploying Ethernet as the communication medium for these mission-critical applications. Automotive Ethernet provides an adaptation of existing IP networking technologies specifically tailored for use in vehicles. The Automotive Ethernet is built o of standard networking technology modified for the conditions found in a vehicle including twisted pair cables that were adapted to support the extreme temperatures of a vehicle and the electrical noise inside the vehicle. Unlike the shared bus of CAN, Ethernet is based on a point-to-point connection or switched network topology.
Speed: Ethernet supports much higher speeds than the 1Mbit/s or lower that CAN provides. It can support speeds from 100Mbit/s to greater than 1Gbit/s and can transmit multiple video streams and data.
Usage: This protocol is primarily utilized by Advanced Driver Assistance Systems (ADAS) and infotainment systems requiring continuous high-bandwidth data transmission. Although Ethernet has much higher throughput capabilities than CAN, Ethernet does not have the built-in safety mechanisms or timing predictability found in CAN. Vehicles use both protocols - CAN handles timing-critical control and Ethernet manages high volume data.

15

# 2. Theoretical Background |

Media Oriented Systems Transport
Originally designed for vehicle entertainment and multimedia systems, MOST is able to transfer data types that would normally cause overloads to traditional automotive buses. This bus adopts a ring topology to connect devices compared with the CAN straight-line bus architecture found on most vehicles. MOST uses a ring topography for devices connected in a closed loop, unlike CAN which uses a linear bus architecture. The initial implementations used plastic optical fibre (POF) cable to deliver good immunity to electromagnetic interference (EMI), but later generations introduced unshielded twisted pair (UTP) copper cabling to reduce costs at the expense of electric noise immunity.
Speed: MOST has been through three distinct generations: MOST25 (25Mbit/s), MOST50 (50Mbit/s) and MOST150 (150Mbit/s). All generations use time-division multiplexing (TDM) to allocate bandwidth, and ensure that there are no interruptions in the streaming of audio and video products that are dependent on users having a continuous, jitter free playback experience [1].
Usage: The three premier automotive manufacturers, Mercedes-Benz, Audi and BMW have heavily implemented MOST in high-end audio systems, navigation systems, and rear entertainment systems, respective applications. But MOST is now in the process of being phased out, for most of the industry, as most manufacturers have begun to transition to Automotive Ethernet in order to support both more flexible architecture as defined by modern software defined vehicles (SDV).

FlexRay
FlexRay was created to address applications that require much higher speed and dependability than CAN comes close to providing. This is mostly based on its applications in safety-critical systems as there is no room for failure. FlexRay is an excellent example of dual-communications line redundancy. If a communications line becomes faulty, the backup communication line can immediately assume communications without any interruption of communication. The timing of message transmission is strictly time-triggered. Speed: FlexRay is capable of transmitting up to 10 Mbit/s on each channel and providing absolutely guaranteed delivery of messages at the time they are scheduled — this is especially important in how systems control steering, brakes, etc.
Usage: Due to complexity and expense, it is only seen in high-end, luxury vehicles equipped with advanced ’drive-by-wire’ systems (steering, brakes, etc. via electronic signals) [6].

16

# | 2.1. Controller Area Network

Legacy Diagnostic Protocols
Before CAN became the standard, older vehicles utilised various methods for diagnostic purposes. One of the most prevalent methods pre-2008 was the K-Line (ISO 9141), which was the basis for various types of protocols such as KWP2000. CAN-based diagnostics (ISO 15765) replaced K-Line for OBD-II. The base design of K-Line has influenced the physical layer of the LIN protocol. If you’ve worked on an older vehicle, you may have encountered K-Line; however, it is obsolete for current model year vehicles.

17

# 2. Theoretical Background |

## 2.2 OBD-II Standard

### 2.2.1 Overview and Standardization

OBD-II (On-Board Diagnostics Version Two) is a universal computer-based control system contained in all vehicles to manage the function of components that control the emissions from the engine. The Controller Area Network (CAN) provides the physical transmission medium for the data’s movement, while OBD II establishes a higher-level definition of the protocol that determines the formatting, requesting and interpretation of diagnostic information [31].

Legislative Background and Intent
The creation of OBD systems is primarily attributed to the emissions control legislation coming out of California State’s California Air Resources Board (CARB). The adoption of a standardized OBD-II was implemented in four dierent phases throughout regulatory regions:

.1. All US manufactured (domestic) passenger automobiles and light duty

trucks manufactured after January 1, 1996

.2. All European manufactured gasoline powered automobiles beginning

January 1, 2001 and diesel fuel automobiles beginning January 1, 2003 (EOBD)

.3. Beginning with 2010 model year, all US manufactured heavy duty vehicles

shall utilize the OBD-II system in compliance with the established OBD standards.
ISO 15765-4 OBD II Diagnostics using CAN Protocol
Since 2008, CAN bus communication (ISO 15765-4) has been the required signaling protocol for OBD II on all vehicles manufactured for sale in the United States. The ISO 15765-4 standard has also defined specific requirements for the underlying CAN Protocol (ISO 11898), including fixed CAN protocol (ISO 11898) bit rates of 250 kbit/s and a maximum length for diagnostic adapters.

18

# | 2.2. OBD-II Standard

### 2.2.2 OBD II Physical Connector

The SAE J1962, or ISO 15031-3, standard defines the physical connection between vehicles and diagnostic equipment. OBD II uses a 16-pin D-shaped female connector, which provides external access to this network. It’s physically wired to the Central Gateway providing the connection point. This allows diagnostic tools to communicate through the Gateway to reach any ECU across all vehicle networks for troubleshooting and data monitoring.

Figure 2.9: OBD-II most common locations [37]

OBD II Connector Pin-out
OBD II utilizes a connector that is designed to support legacy diagnostic protocols such as K-Line; however, pins 6, & 14 (ISO 15765 CAN High and CAN Low) are used only for new CAN diagnostics [8].

.1. Pin 6 - CAN High (CAN_H)
.2. Pin 14 - CAN Low (CAN_L)
.3. Pin 16 - 12 V Battery Power (or 24 V)
.4. Pin 4 - Chassis Ground
.5. Pin 5 - Signal Ground

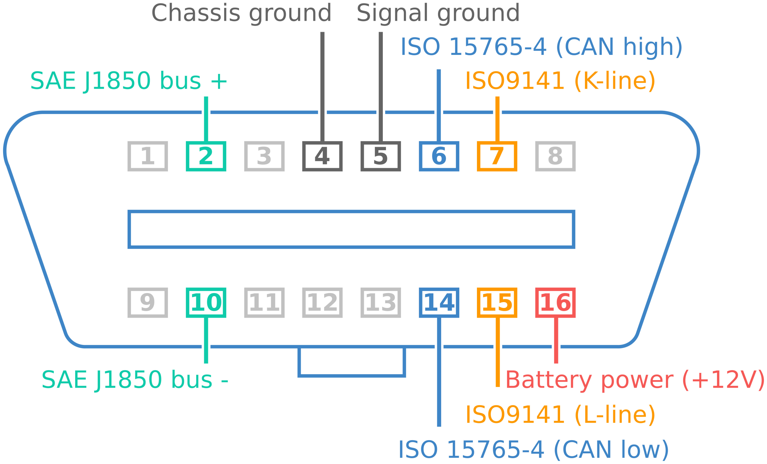
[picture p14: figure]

Figure 2.10: OBD-II Connector pinout [9]

19

# 2. Theoretical Background |

### 2.2.3 Parameter IDs

OBD-II has a standardized format for messages as opposed to a proprietary CAN that uses a manufacturer specific DBC file (as mentioned in Section 2.1.4) to decode the messages and the standard for this is SAE J1979. PIDs (along with defined formulas) provide the means necessary to convert the raw data into physical values and thus vehicle specific databases are not required when accessing standard diagnostic data. PIDs represent standard identifiers used to request vehicle data from the vehicle ECUs through the OBD-II interface.
Standard vs Manufacturer-Specific PIDs
PIDs are categorized into two main types:

. Standard PIDs (Mode 0x01): These PIDs are specified by the SAE

J1979 standard and are mandatory for a vehicle to meet OBD-II compliance by all manufacturers. The Standard PIDs encompass important, emission-related attributes of a vehicle, such as engine RPM, vehicle speed, coolant temperature, and fuel system status. The standard PIDs also provide consistency in the required format of the data across all vehicle manufacturers to allow for any generic scanning tool to retrieve basic diagnostic information from all compliant vehicles.

. Manufacturer-Specific PIDs (Mode 0x09 and others): In addition

to the standard PIDs, manufacturers can add proprietary PIDs to their vehicles to provide additional vehicle-specific data. Each manufacturer has unique manufacturer-specific PIDs that may require specialized diagnostic software to interpret.

Common Standard PIDs
Table 2.2 lists frequently used PIDs with data byte formulas and ranges. Table 2.2: Common OBD-II Standard PIDs
PID | Parameter | Formula | Unit | Range
0x0C | Engine RPM | (A ◊ 256 + B)/4² | rpm | 0–16 383
0x0D | Vehicle Speed | A | km h≠1 | 0–255
0x05 | Coolant Temp | A ≠ 40 | °C | ≠40 to +215
0x04 | Engine Load | A ◊ 100/255 | % | 0–100
0x11 | Throttle Position A ◊ 100/255 | % | 0–100
0x0F | Intake Air Temp | A ≠ 40 | °C | ≠40 to +215
0x10 | MAF | (A ◊ 256 + B)/100 | g/s | 0–655.35

2A and B denote the first and second bytes of the OBD-II response frame, respectively.

20

# | 2.2. OBD-II Standard

PID Decoding Examples
Example 1: Engine RPM (PID 0x0C). Engine RPM is transmitted using two data bytes (A and B). The formula to calculate RPM is:
RPM = (A ◊ 256) + B
4 | (2.7)
Sample Response:
Suppose the ECU responds with the following CAN message for PID 0x0C:

Response: 04 41 0C 1A F8 00 00 00
Breaking down this response:

. 04 = Number of additional data bytes
. 41 = Mode $01 response (0x40 + 0x01) . 0C = PID (Engine RPM)
. 1A = Data byte A (26 in decimal)
. F8 = Data byte B (248 in decimal)

Calculation:
RPM = (26 ◊ 256) + 248
4 | = 6656 + 248
4 | = 6904
4 = 1726 rpm | (2.8)
Example 2: Vehicle Speed (PID 0x0D). Vehicle speed requires only one data byte (A), and the value is directly reported in km h≠1:
Speed = A km h≠1 | (2.9)
Sample Response:

Response: 03 41 0D 50 00 00 00 00 Breaking down this response:

. 03 = Number of additional data bytes . 41 = Mode $01 response
. 0D = PID (Vehicle Speed)
. 50 = Data byte A (80 in decimal)

Calculation:
Speed = 80 km h≠1 | (2.10)
This straightforward encoding makes vehicle speed one of the simplest PIDs to interpret.

21

# 2. Theoretical Background |

## 2.3 Market Analysis of Existing OBD-II Solutions

An analysis of existing OBD-II diagnostic solutions reveals two primary product categories: tools focused on vehicle fault diagnostics and tools using the OBD-II interface primarily for tracking and telematics purposes [19].

OBDeleven

. Key Features: Provides deep access to proprietary systems with empha-

sis on VAG Group (VW, Audi, äkoda, Seat), BMW, and Toyota. Oers One-Click Apps for coding operations without manual programming.

. Advantages: Intuitive interface and high level of system integration. . Disadvantages: Many features require additional credits or an annual

subscription [38].

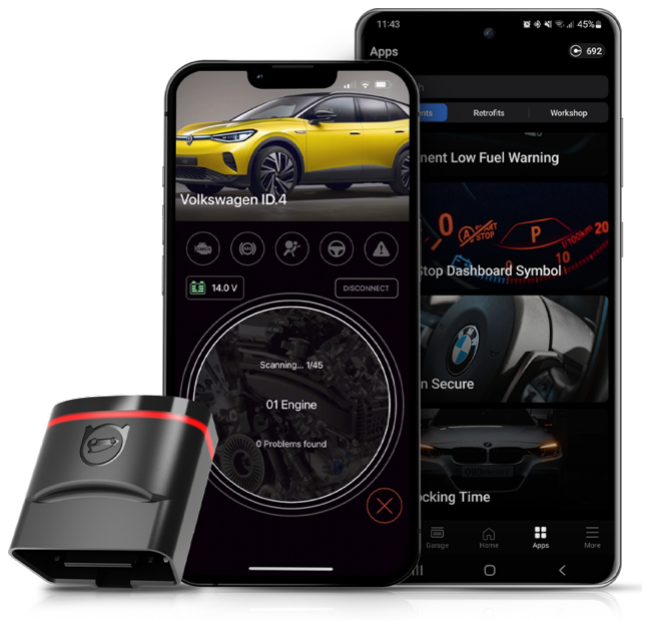
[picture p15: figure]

Figure 2.11: OBDeleven diagnostic dongle [22]

22

| 2.3. Market Analysis of Existing OBD-II Solutions

Generic ELM327 Adapters
Budget-level diagnostic dongles that act as a bridge between the vehicle ECU and external applications such as Torque or Car Scanner [11].

. Key Features: Provide access to DTC codes and live sensor readings

via standard OBD-II PIDs.

. Advantages: Extremely aordable and compatible with virtually all ve-

hicles manufactured after 2001.

. Disadvantages: Limited to the engine control unit only; the market

is flooded with low-quality clones with connectivity issues.

Figure 2.12: Generic ELM327 Bluetooth adapter [17]

SIZZAPP — Signal Profi 4G GPS Tracker
Unlike diagnostic tools, SIZZAPP is designed primarily for vehicle protection and tracking, using the OBD-II port for power and minimal telemetry [29].

. Key Features: GPS tracker with 4G connectivity providing location

history, trip records, and motion detection alarms for theft or collision events.

. Advantages: No monthly subscription fee required.
. Disadvantages: Focused on telematics rather than diagnostics; limited

OBD-II data access.

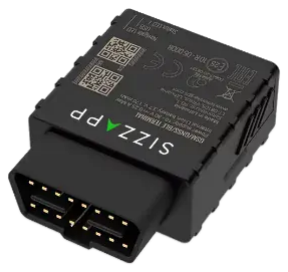
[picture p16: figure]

Figure 2.13: SIZZAPP 4G GPS OBD tracker [30]

23

# 2. Theoretical Background |

T-Mobile Smart Car
The Smart Car system represents the connected car direction, using the OBD-II port for telematics and in-car connectivity [33].

. Key Features: Integrated SIM card operating as a mobile hotspot,

with GPS tracking and basic vehicle state monitoring.

. Advantages: Allows a Wi-Fi connection for car.
. Disadvantages: Requires a monthly subscription and provides very

limited diagnostic data.

Figure 2.14: T-Mobile Smart Car OBD-II device [15]

24

## Chapter 3 Design and Implementation of the Device

## 3.1 Introduction

The main goal of the thesis was to develop a device for analyzing real-time automotive data from the CAN bus using the OBD-II interface of the vehicle. In accordance with the set requirements, the system development process was divided into three major areas:

. designing a custom diagnostic device.
. development of embedded firmware.
.implementing a cloud-based server for remote data monitoring based

on the use of a cellular module.

## 3.2 Hardware Design

### 3.2.1 System Requirements and Component Selection

The hardware design of the diagnostic device, based on four key functional blocks¹:

. a main microcontroller for system control and data processing.
. a CAN FD controller for communication with the vehicle bus.
. a cellular module for remote data transmission and vehicle positioning. . a power supply subsystem adapted to the automotive environment.

The selection of each component was driven by the requirements of automotive operation and the need for compatibility with the OBD-II/CAN FD protocol. The following subsections describe each component and the rationale behind its selection.²
1The complete schematic of the device is provided in Appendix B. 2Detailed datasheets of all components from this chapter are provided in Appendix A.

25

3. Design and Implementation of the Device |

Microcontroller — ESP32-S3-MINI-1-N8
The ESP32-S3-MINI-1-N8 module by Espressif Systems was chosen as the main computing element of the device. The motivation behind the decision included the small size of the module, the presence of the PCB 2.4 GHz Wi-Fi antenna, and capabilities of the dual-core 32-bit Xtensa LX7 CPU with 240 MHz frequency. Among the most important characteristics, the SPI, IC, and UART interfaces enable peripheral connectivity. The main electrical specifications can be found in Table 3.1.
Table 3.1: Key features of the ESP32-S3-MINI-1 module (N8 variant)
Parameter | Specification
MCU core | Dual-core Xtensa® LX7, 32-bit, up to 240 MHz
On-chip memory | 384 KB ROM, 512 KB SRAM, 16 KB RTC SRAM
External flash | 8 MB Quad SPI
Wireless connectivity | Wi-Fi 802.11 b/g/n (2.4 GHz), Bluetooth 5 LE
GPIO pins | 39 (multiplexed with peripherals)
Key interfaces | SPI, UART, IC, IS, USB 2.0 OTG, TWAI®, ADC
Integrated peripherals | TWAI® (CAN 2.0), touch sensor, temperature sen- sor, LED PWM, RMT
Operating voltage | 3.0 V–3.6 V
Operating temperature | ≠40 °C to +85 °C
Antenna option | External connector (U.FL/IPEX)
Module dimensions | 15.4 mm ◊ 15.4 mm ◊ 2.4 mm
Package | 65-pin module

CAN FD Controller — MCP2518FD
An external MCP2518FD CAN FD controller by Microchip Technology was used for vehicle CAN bus communication. While the ESP32-S3 includes a built-in TWAI controller, it only supports CAN 2.0 at speeds up to 1 Mbit/s and requires an external transceiver. The MCP2518FD provides full CAN FD support (ISO 11898-1:2015) with data phase speeds up to 8 Mbit/s and backward compatibility. Communication with the ESP32-S3 is managed via the SPI bus at up to 20 MHz. Key features include:

. 31 configurable FIFO buers for data transmission and reception.
. 32 configurable message acceptance filters.
. Automatic CRC check during SPI transfers to prevent data corruption. . Automotive qualification with operating temperatures from

≠40 °C to +125 °C.

26

# | 3.2. Hardware Design

LTE & GPS Module — SIMCom A7670E
The SIMCom A7670E module enables remote data transmission and positioning via LTE Cat-1 with GSM/GPRS fallback. It integrates a GNSS receiver, eliminating the need for external GPS hardware, and communicates with the ESP32-S3 via UART using AT commands. The module’s 5 V–10 V supply range was integrated into the power subsystem design. Key specifications include:

. LTE Cat-1 connectivity with 2G fallback for limited coverage areas.
. Integrated TCP/IP and HTTP(S) stacks for direct server communication. . GNSS engine for vehicle position and time synchronization.
. Low-power modes suitable for permanent vehicle installation.

LTE connectivity is provided via a microstrip PCB antenna with a gain of 5 dBi and a U.FL connector.
Power Supply — TPS54331
The device is powered directly from the vehicle OBD-II connector, which provides a nominal voltage of 12.2–12.7 V. During engine operation, the voltage range could be between 13.5 V and 14.7 V. To regulate this input to a stable output suitable for the system components, the TPS54331 synchronous step-down converter from Texas Instruments was selected. This device integrates a power MOSFET and is capable of delivering up to 3 A of continuous output current. The output voltage was set to 5 V by means of a resistor divider connected between the output and the feedback node. The converter operates at a fixed switching frequency of 570 kHz, which reduces the physical size of the external inductor. An operating temperature range of ≠40 °C to +125 °C ensures reliable performance across the full range of conditions expected in an automotive environment.

27

3. Design and Implementation of the Device |

### 3.2.2 Circuit Design

The circuit architecture is composed of several functional blocks, as shown

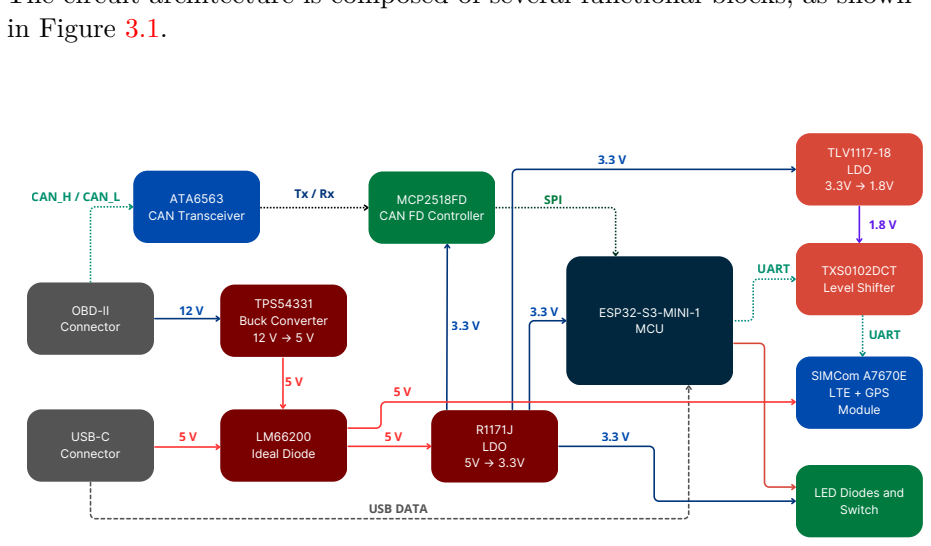
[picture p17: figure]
in Figure 3.1.; USB-C Connector; OBD-II Connector; TPS54331 Buck Converter 12 V → 5 V; LM66200 Ideal Diode; ATA6563 CAN Transceiver; MCP2518FD CAN FD Controller; R1171J LDO 5V → 3.3V; ESP32-S3-MINI-1 MCU; TLV1117-18 LDO 3.3V → 1.8V; TXS0102DCT Level Shifter; SIMCom A7670E LTE + GPS Module; LED Diodes and Switch; CAN_H / CAN_L; SPI; UART; USB DATA

Figure 3.1: CAN Bus Snier block diagram

OBD-II Connector
The OBD-II connector provides power and CAN bus connection from the vehicle. Both CAN_H and CAN_L lines have implemented ESD protection on PCB. There is an option to add impedance termination of the bus. This application consists of two 60 resistors and one 4.7 nF capacitor (marked DNP in the BOM file) in case there is only one device attached to the bus, thus maintaining the impedance of 120 required by the CAN protocol. The 0 resistor allows selection of either signal ground (pin 5) or chassis ground (pin 4). In this design, signal ground was preferred, because it provides higher noise immunity from vehicle electrical system.

28

# | 3.2. Hardware Design

DC/DC Step-down Converter — TPS54331
The step-down DC/DC converter is connected to the power input of the OBD-II connector and transforms the vehicle supply voltage to 5 V. The regulated output voltage is determined by the resistor divider on the feedback pin of the IC according to Equation 3.1:

Vout =0.8 ◊

3
1+ R1
R2

4

=0.8 ◊

3
1+ 10 k
1.91 k

4

=4.99 V | (3.1)
where Vout is the regulated output voltage, R1 = 10 k, and R2 =1.91 k, yielding a nominal output voltage of 5 V.
A 6.8 µH output inductor was selected with respect to the 570 kHz switching frequency. Input protection consists of a Schottky diode, an ESD diode, a 2 A polyfuse, and a 120 ferrite bead, which suppresses high-frequency noise in both directions between the vehicle network and the converter.
USB-C Connector
Two 5 k resistors on CC1 and CC2 identify the device as a USB sink. A 2 A polyfuse and ESD protection are included on the VBUS line. The USB-C input is routed to the LM66200 ideal diode, allowing the device to be powered from USB during development without a vehicle connection.

Ideal Diode — LM66200
The LM66200 compares the OBD-II and USB-C input voltages and automatically connects the higher source to the output rail, blocking reverse current from both inputs. This eliminates the need for manual power source selection and avoids the forward voltage drop of conventional signal diodes.

LDO Regulator — R1171J
The R1171J converts the 5 V supply rail to 3.3 V required by the ESP32-S3, MCP2518FD, status LEDs, and the LDO for the SIMCom module. Two ceramic capacitors of 4.7 µF ensure stability across the complete load range.

Level Shifter — TXS0102DCT and TLV1117LV
The SIMCom A7670E module communicates via UART, which operates at 1.8 V, while the ESP32 uses 3.3 V logic. A TXS0102DCT bidirectional shifter translates these voltages without direction control. Its 1.8 V supply is derived from the 3.3 V rail via a TLV1117LV LDO regulator.

29

3. Design and Implementation of the Device |

CAN Bus Interface — MCP2518FD and ATA6563
The MCP2518FD CAN FD controller processing data from vehicle and handles the CAN protocol stack operations. The communication between the MCP and the ESP32 is performed through the SPI bus interface. The controller communicates with the ATA6563 transceiver via TX/RX signals, which translates into dierential CAN_H and CAN_L signals on the physical bus layer. The 3.3 V logic level of the MCP2518FD is also applied to the VIO pin of the ATA6563, setting its logic threshold accordingly.

User Interface — LEDs and Buttons
Three status LEDs indicates devicee activity.
– LED1 (red) — LTE/POST status: lights up when the modem is connected, flashes quickly once for each successful POST, turns o in case of an error
– LED2 (blue) — GPS: flashes 3 times + pauses until a fix is acquired; stays lit when a fix is acquired
– LED3 (green) — CAN activity: flashes with every received CAN frame.
A power LED is connected directly to the 3.3 V rail. A Reset button is connected to the EN pin and a Boot button to GPIO0, enabling firmware download mode when held during reset. User button is not implemented yet and could be used for future application.

30

# | 3.2. Hardware Design

### 3.2.3 PCB Design

. The PCB was designed as a four-layer board with measurements

of 50 ◊ 45 mm and 1.6 mm thickness. The schematic includes two external signal layers and a continuous ground layer at the second layer. The 5 V power rail is routed as a trace on the bottom layer, while the 3.3 V rail is implemented as a local copper pour in areas where it is required, rather than a continuous plane across the entire board. PCB was manufactured by Printed Mlník.³

. The ground plane provides a low-impedance return path for all signals

and suppresses electromagnetic interference across the board. Via stitching ensures electrical continuity between ground pours on all layers, with increased via density around the ESP32-S3-MINI-1 module to reduce ground impedance in the Wi-Fi and Bluetooth frequency range.

. Special attention was paid to the layout of the TPS54331 switching

converter. The output capacitors C18, C19, C20 and the output inductor, and the ESD diode were placed as close as possible to the IC, minimising the area of the high-frequency switching current loop and reducing radiated electromagnetic interference (as shown in Figure 3.3). Six thermal vias under the exposed pad conduct heat to the inner ground plane.

. The SIMCom GSM/GNSS module is integrated as a standalone breakout

board connected to the main PCB via a 7-pin header. The header carries the following signals: UART RX, UART TX, VDD power supply, PWRKEY for module power control, Sleep pin for low-power mode control, and two GND pins, as detailed in Table 3.2. This approach allows the module to be replaced or disconnected independently of the main board. External LTE and GPS antennas are connected to the module via dedicated U.FL connectors. It has also 2 slots for Micro SIM card. Whole PCB layout is shown in Figure 3.2.
3Printed — ploöné spoje a osazování, https://printed.cz/

31

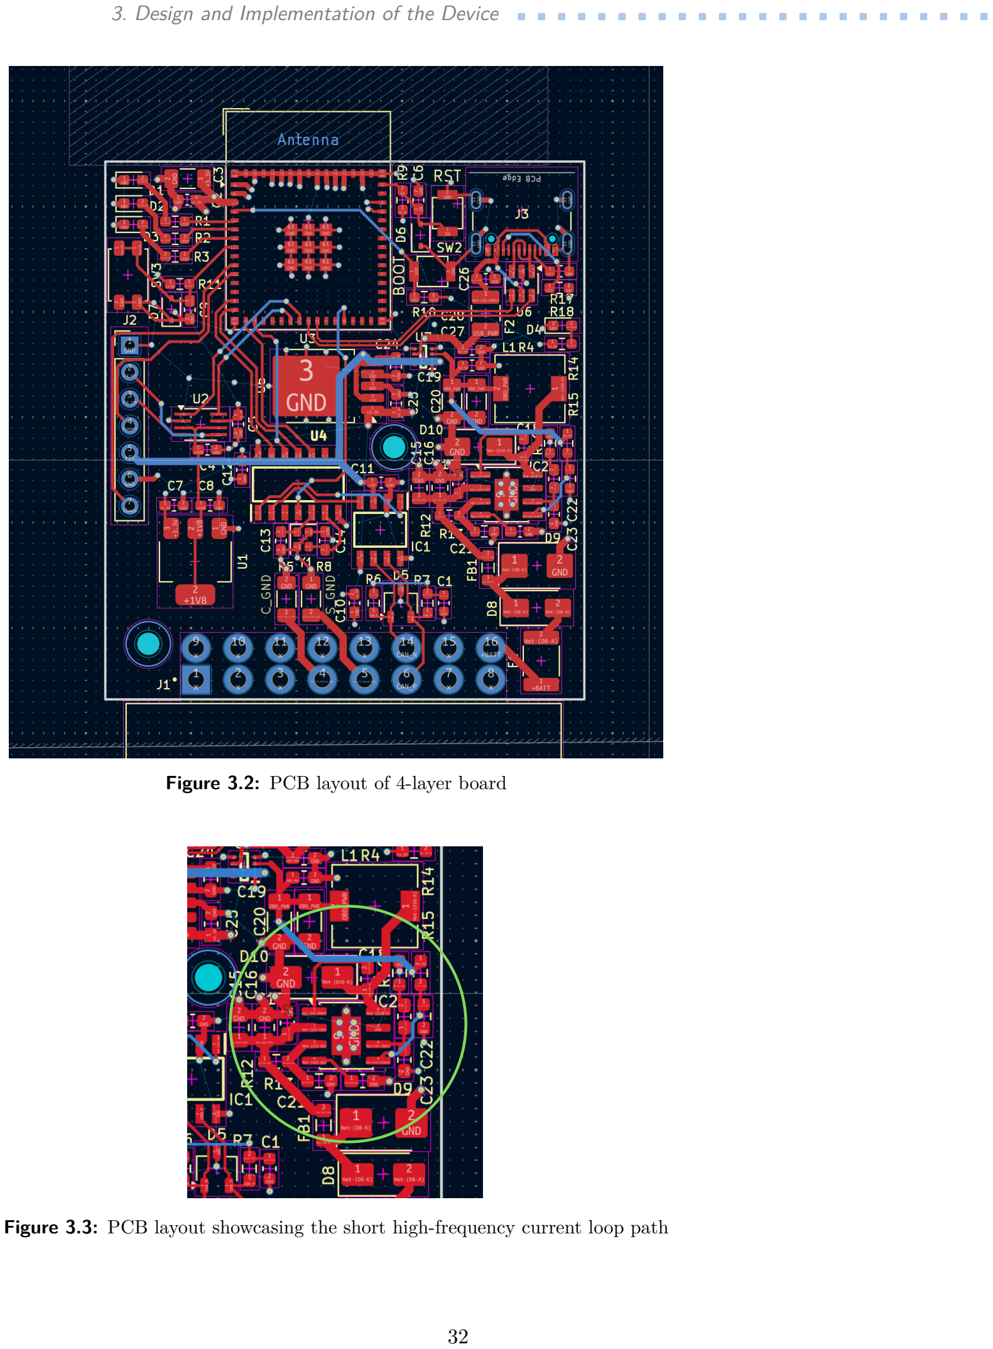
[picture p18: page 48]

3. Design and Implementation of the Device |

Figure 3.2: PCB layout of 4-layer board

Figure 3.3: PCB layout showcasing the short high-frequency current loop path

32

# | 3.2. Hardware Design

### 3.2.4 System Pin Assignment

Table 3.2 summarises the GPIO pin assignment of the ESP32-S3 module grouped by functional block.
Table 3.2: ESP32-S3 GPIO Pin Assignment by Functional Block
Pin (IO) | Signal | Function / Destination | Component
3V3 | +3V3 | ESP32-S3 power supply | Power
IO1 | LED3 | Status indicator LED 3 | Red LED
IO2 | LED2 | Status indicator LED 2 | Blue LED
IO3 | LED1 | Status indicator LED 1 | Green LED
IO4 | USER_SW | User button | Button
EN | RESET_BTN Reset button | System button
IO0 | BOOT_BTN Boot button | System button
IO6 | SLEEP | Sleep mode control pin | SIMCom module
IO7 | PWRKEY | Module power on/o button | SIMCom module
IO10 | CS | SPI Chip Select | MCP2518FD
IO11 | MOSI | SPI Data (Master Out Slave In) | MCP2518FD
IO12 | SCK | SPI Clock | MCP2518FD
IO13 | MISO | SPI Data (Master In Slave Out) | MCP2518FD
IO17 | RXD | UART Receive | SIMCom module
IO18 | TXD | UART Transmit | SIMCom module
IO23 | USB_D≠ | USB dierential pair (negative) | USB-C
IO24 | USB_D+ | USB dierential pair (positive) | USB-C
IO47 | INT | Interrupt output | MCP2518FD

33

3. Design and Implementation of the Device |

## 3.3 Firmware Development

### 3.3.1 Software Architecture

The firmware was developed using the PlatformIO development environment, which provides dependency management and integrated serial monitoring. Two functional variants of the firmware were implemented. The first variant transmits vehicle data to the cloud server.
In the second variant, the ESP32-S3 functions as a local Wi-Fi access point and serves a real-time dashboard to the connected device directly.
The firmware is organized into the following functional modules:

. CAN communication — MCP2518FD initialization, OBD-II request

transmission and response reception via the ACAN2517FD library

. OBD-II decoder — PID request construction, response parsing and value

calculation according to SAE J1979

. LTE transmission — AT command sequences for network registration

and HTTPS POST to the remote server

. GPS acquisition — GNSS position reading via AT commands with fall-

back logic when no fix is available

.Web server — local Wi-Fi access point serving a real-time dashboard

over HTTP, used in the standalone variant

. LED indication — visual feedback on CAN activity, LTE connectivity

and GPS fix status

### 3.3.2 System Flow Diagram

During initialization, the system configures all peripherals sequentially — SPI, CAN controller, LTE module, and GNSS receiver. Network registration is confirmed via AT+CREG? returning 0,1 or 0,5.
The core firmware architecture is governed by a Finite State Machine (FSM) that manages power consumption and operational modes based on CAN bus activity. The FSM transitions between four primary states: BOOT, DRIVING (active communication), IDLE_AWAKE (engine o, ECU quiet), and LIGHT_SLEEP (power-saving mode).
In the active DRIVING state, the main loop operates entirely asynchronously to prevent data loss. A GNSS position is continuously polled using AT+CGNSSINFO and stored if a valid fix is available. OBD-II requests are dispatched sequentially via the broadcast identifier 0x7DF, Mode 0x01. Rather than utilizing blocking timeouts, the system sends requests at strictly defined intervals — 50 ms for critical dynamic data (e.g., RPM, speed) and 150 ms for slow-changing parameters. Responses from the vehicle’s ECUs, expected

34

# | 3.3. Firmware Development

in the range from 0x7E8 to 0x7EF, are processed continuously via a nonblocking CAN service routine.
Data transmission is decoupled from the OBD-II polling cycle. A JSON payload is sent to the remote server via HTTPS POST at a fixed interval of 2000 ms. To optimize bandwidth and processing, the payload alternates between a smaller "fast" subset and a "full" telemetry set every third cycle. Receipt of an HTTP 200 OK denotes successful delivery, which is visually reflected by the LTE status LED. To ensure high reliability, if three consecutive HTTP transmissions fail, the microcontroller triggers a hardware reset of the modem via the PWRKEY sequence and initiates a full network reconnection.
Firmware execution and the state transitions are illustrated in Figure 3.4.

35

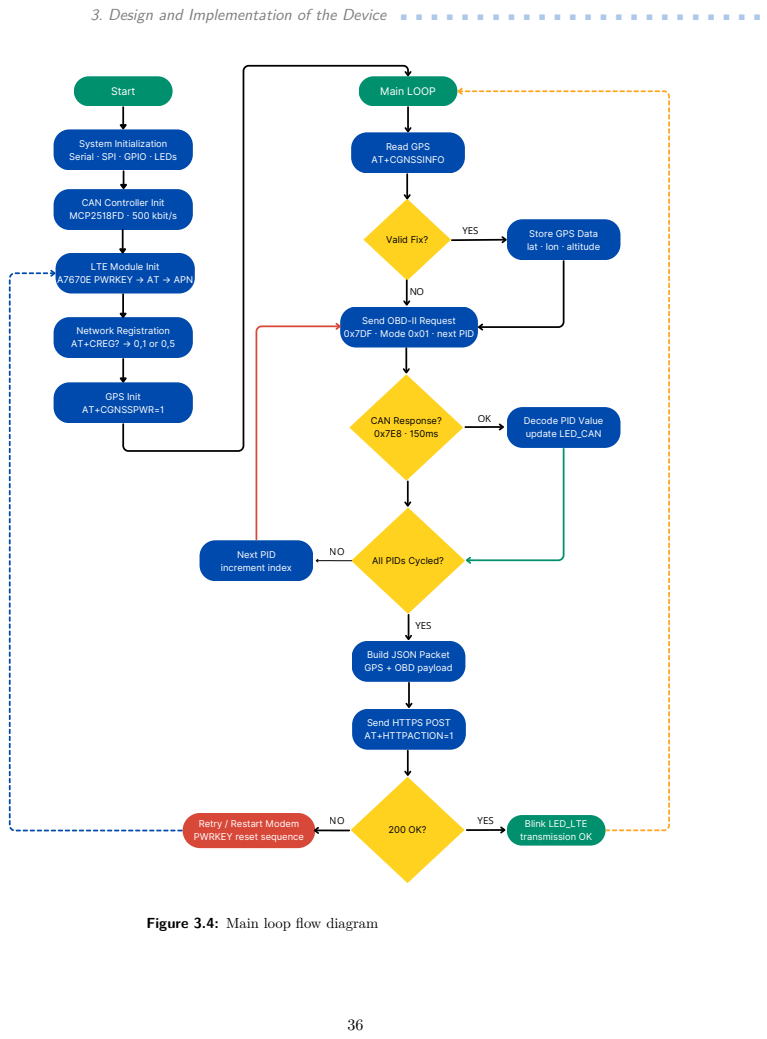
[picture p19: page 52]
Start; GPS Init AT+CGNSSPWR=1; Main LOOP; Valid Fix?; Read GPS AT+CGNSSINFO; CAN Response? 0x7E8 · 150ms; Next PID increment index; Blink LED_LTE transmission OK; YES

3. Design and Implementation of the Device ...............................

System Initialization
Serial · SPI · GPIO · LEDs

CAN Controller Init
MCP2518FD · 500 kbit/s

Store GPS Data
lat · lon · altitude

LTE Module Init

A7670E PWRKEY → AT → APN

Send OBD-II Request
0x7DF · Mode 0x01 · next PID

Network Registration
AT+CREG? → 0,1 or 0,5

Decode PID Value
update LED_CAN

All PIDs Cycled?

Build JSON Packet
GPS + OBD payload

Send HTTPS POST
AT+HTTPACTION=1

200 OK? Retry / Restart Modem
PWRKEY reset sequence

Figure 3.4: Main loop flow diagram

# | 3.3. Firmware Development

### 3.3.3 CAN Controller Initialization

The initialization of the MCP2518FD CAN controller over SPI is managed using the ACAN2517FD library. The SPI interface was configured with the pins mentioned in Table 3.2. The controller was initially configured to operate under CAN 2.0 with a nominal bit rate of 500 kbit/s, which ensures compatibility with the CAN 2.0B protocol used by the vehicle ECUs. The chosen bit rate corresponds to the ISO 15765-4 standard applicable to most present-day vehicles.
In its default hardware configuration, the MCP2518FD controller silently discards all incoming frames unless acceptance filters are configured. These filters can be explicitly defined in software configuration, using methods such as appendFilter() to specify exactly which CAN IDs or ranges the hardware should forward to the microcontroller, thereby preventing CPU overload. However, this project utilizes the library’s appendPassAllFilter() method (applied implicitly during initialization) to forward all CAN trac. While processing all messages in software could overwhelm weaker processors, the ESP32-S3 eortlessly handles the load required for scanning broad OBD-II data thanks to its dual-core architecture and high clock rate.
1 | ACAN2517FDSettings canSettings(
2 | ACAN2517FDSettings::OSC_40MHz,
3 | 500 * 1000,
4 | DataBitRateFactor::x1
5 | );
6 | canSettings.mRequestedMode = ACAN2517FDSettings::Normal20B;
7 | const uint32_t canErr = can.begin(canSettings, canISR);
8 | if (canErr == 0) {
9 | Serial.println("[CAN] OK @ 500 kbit/s");
10 | can.appendPassAllFilter();
11 | } else {
12 | Serial.print("[CAN] ERROR: 0x");
13 | Serial.println(canErr, HEX);
14 | }
15 | \caption{Initialization of the MCP2518FD CAN controller at
| 500 kbit/s}
16 | \label{lst:can_init}
| Listing 3.1: Initialization of the MCP2518FD CAN controller at 500 kbit/s

37

3. Design and Implementation of the Device |

### 3.3.4 OBD-II PID Decoding

OBD-II diagnostic data is requested using the standard broadcast identifier 0x7DF with Mode 0x01, as defined by SAE J1979. Prior to starting cyclic reading, a PID support scan is performed by requesting PIDs 0x00, 0x20, 0x40, and 0x60, which return 32-bit data frames indicating which parameters are supported by the connected vehicle. Once the supported parameters are known, actual sensor data is periodically requested. The received raw data bytes are then passed to the decodePID() function, which applies the appropriate formula based on the PID identifier to calculate the final physical values.
1 | void sendOBDRequest(uint8_t pid) {
2 | CANFDMessage frame;
3 | frame.id = 0x7DF;
4 | frame.len = 8;
5 | frame.data[0] = 0x02; // Number of additional data bytes
6 | frame.data[1] = 0x01; // Mode 01 (Current Data)
7 | frame.data[2] = pid; // Requested PID
8 | memset(&frame.data[3], 0, 5); // Padding remaining zero
| bytes

9
10 | can.tryToSend(frame);
11 | }

12
13 | float decodePID(uint8_t pid, uint8_t a, uint8_t b) {
14 | switch (pid) {
15 | case 0x0C: return ((a * 256.0f) + b) / 4.0f; // RPM
16 | case 0x05: return a - 40.0f; | //
| Coolant Temp
17 | case 0x0D: return a; | //
| Speed
18 | case 0x11: return (a * 100.0f) / 255.0f; | //
| Throttle
19 | default: return a;
20 | }
21 | }
Listing 3.2: OBD-II request transmission and PID decoding functions

38

# | 3.3. Firmware Development

### 3.3.5 LTE Communication

The SIMCom A7670E module is controlled via AT commands transmitted over UART at 115200 bps. The power-on process involves a pulse on the PWRKEY pin to initialize the module, followed by a five-second boot delay. Network registration state is verified via the AT+CREG? command; responses of 0,1 or 0,5 signify successful registration. Signal strength is evaluated via AT+CSQ; test results usually indicated a signal strength value of 28, which corresponds to approximately -57 dBm and is considered a strong signal⁴. APN configuration for the O2 CZ network is performed via AT+CGDCONT. This is done by sending the AT+CGDCONT=1,"IP","internet" command, to which the module responds with OK. Once network connection is established, an HTTPS POST request is sent to the remote server via the following command sequence:
1 | AT+CSSLCFG="sslversion",0,3 | // TLS 1.2
2 | AT+CSSLCFG="authmode",0,0 | // no cert verification
3 | AT+CSSLCFG="enableSNI",0,1 | // SNI required by
| Railway
4 | AT+CSSLCFG="ignorelocaltime",0,1
5 | AT+HTTPINIT
6 | AT+HTTPPARA="URL","https://server/data"
7 | AT+HTTPPARA="CONTENT","application/json"
8 | AT+HTTPPARA="USERDATA","Authorization: Bearer <token>"
9 | AT+HTTPPARA="SSLCFG",0
10 | AT+HTTPDATA=<length>,10000
11 | AT+HTTPACTION=1 | // +HTTPACTION: 1,200,<
| len>
12 | AT+HTTPTERM
Listing 3.3: AT command sequence for HTTPS POST transmission
A critical finding during testing was that Railway’s edge infrastructure requires the TLS SNI (Server Name Indication) extension to be explicitly enabled via AT+CSSLCFG="enableSNI",0,1. Without this parameter, the module firmware A131B03 consistently returned error code 715 (TLS handshake failure), as the server could not determine which certificate to present for the multi-tenant domain *.up.railway.app. The AT+HTTPSSL=1 command, present in earlier firmware versions, is not supported by this firmware build and must be replaced by the AT+HTTPPARA="SSLCFG",0 parameter referencing the pre-configured SSL profile. The remote server is deployed on Railway, a cloud Platform-as-a-Service (PaaS); its architecture and API design are described in detail in Section 3.4.

4CSQ values are in the range from 0 to 31, when 31 is considered as the strongest signal.

39

3. Design and Implementation of the Device |

### 3.3.6 GPS Acquisition

GPS data are acquired by theAT+CGNSSINFO command, which returns latitude, longitude, altitude, and speed if a fix is available. Two acquisition modes are recognised:

. Cold start — no previous position or time information is available;

the process may take several minutes to acquire an initial fix.

. Hot start — cached ephemeris and almanac data are utilized to achieve

a fix within seconds⁵.
When a valid fix cannot be acquired, the GPS parameters are excluded from the JSON packet and system does not visualize location data.
A fix refers to the moment when the GNSS receiver successfully receives signals from a sucient number of satellites — at least four — and is able to calculate a valid position estimate.
A high-gain GNSS antenna with a gain of 28 dBi with the U.FL connector is used. It supports GPS at 1575 MHz, BeiDou at 1561 MHz, and GLONASS at 1602 MHz, with an impedance of 50 .
In case of a weak signal, and a situation where the antenna is not able to get GPS data, the data are not visualized, but it is still trying to get a fix. For future implementation, usage of Cell ID could be highly beneficial. This would significantly enhance location tracking precision and serve as a fallback mechanism in areas with poor GPS coverage, depending on the capabilities of the mobile network operator

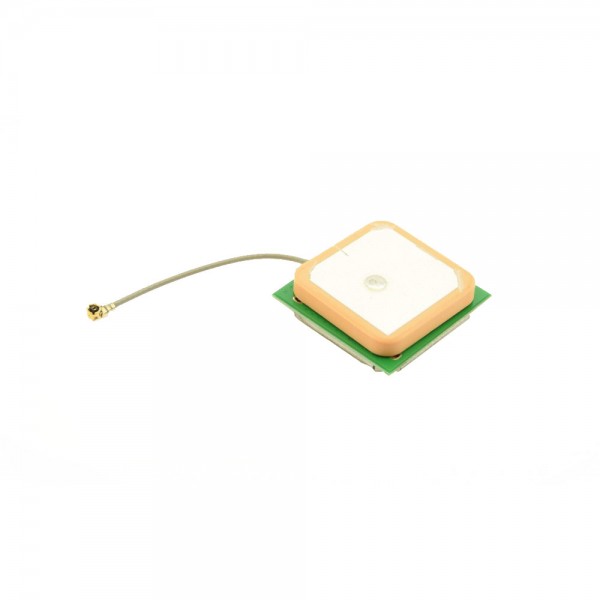
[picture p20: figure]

Figure 3.5: Illustration photos of LTE antenna (left)[34] and GNSS antenna (right)[36]

5Ephemeris data contains precise short-term satellite positions, while the almanac provides long-term constellation orbits. Caching this information allows the receiver to acquire a rapid fix without re-downloading it from the satellites.

40

# | 3.4. Cloud Infrastructure

## 3.4 Cloud Infrastructure

### 3.4.1 Deployment Platform

The Railway.app⁶ platform was selected as the deployment environment, a Platform-as-a-Service (PaaS) provider that enables continuous cloud deployment directly from a GitHub repository. When changes are pushed to the repository, Railway automatically rebuilds and redeploys the application without any manual server administration. The platform provides a fixed public HTTPS endpoint, which serves as the destination for all data transfers initiated by the ESP32-S3 device. The back-end is implemented in Python using the Flask framework.

### 3.4.2 REST API Design

The server exposes a REST API to manage the data flow between the IoT device and the web dashboard. The core endpoints are summarised in Table 3.3.
Table 3.3: REST API Endpoints
Method | Endpoint | Description
POST | /data | Receives a JSON payload from the ESP32-
S3, verifies the nonce, updates the RAM cache, and stores it in the database
GET | /data/latest | Returns the most recent merged state
of all parameters; polled by the dashboard at 5 Hz
GET | /data | Returns stored data packets for historical
view
POST | /command | Accepts a command string and places
it in a queue for retrieval by the device

An example of a JSON packet transmitted by the ESP32-S3 to the endpoint is shown below. The firmware transmits semantic string keys directly (e.g., "rpm", "speed"). This ensures a minimal payload size:
1 | { | "nonce": 1714928192345,
2 | "type": "full",
3 | "rpm": 2500.0,
4 | "speed": 80.0,
5 | "throttle": 45.0,
6 | "engineLoad": 35.0, }
Listing 3.4: JSON payload structure transmitted to the remote server
6https://railway.app

41

3. Design and Implementation of the Device |

On the server side, no strict database schema or decoding dictionary is enforced. Instead, the PostgreSQL database utilizes a JSONB (Binary JSON) column for flexible storage. This approach allows the data structure to be extended with additional OBD-II parameters in the future without requiring any database schema migrations.
To optimize performance for the live web dashboard, the server implements an in-memory state caching mechanism (state_cache). Because the microcontroller alternates between sending smaller "fast" packets and occasional "full" packets to save bandwidth, the server merges incoming data into this cache⁷. The dashboard client (data.js) polls the GET /data/latest endpoint every 200 ms, receiving a seamlessly updated, complete snapshot of the vehicle’s state without generating heavy database queries.

### 3.4.3 Data Storage

The collected data packets are persistently stored in a PostgreSQL database hosted via the Railway platform. Each record in the packets table consists of a server-generated timestamp, an optional event string, and the telemetry payload stored in a JSONB (Binary JSON) format. Utilizing the JSONB data type allows for a flexible, schema-less approach, enabling the system to store varying sets of OBD-II parameters without requiring complex database migrations or predefined column structures.
PostgreSQL was selected for its robust persistence and advanced indexing capabilities. The connection between the Flask application and the database is secured via an encrypted connection string stored as an environment variable. GET /data endpoint is configured to retrieve the most recent history by default, while the database remains a complete, long-term archive for all telemetry data.

### 3.4.4 Repository

The complete project is stored in a public GitHub repository. The repository structure is described in Appendix E.1. https://github.com/Kubakl11/CAN_Bus_Snier_BP

7The "fast" packet consists of RPM, speed, engine load, and throttle position, while the "full" packet contains all supported PIDs and GNSS coordinates

42

# | 3.5. Security Analysis

## 3.5 Security Analysis

Since two independent prototypes were implemented, two dierent security approaches were made. The primary configuration utilises a cellular LTE module for remote data transmission to a cloud server, while the secondary configuration operates the ESP32-S3 as a local Wi-Fi access point, allowing the user to connect directly via a captive portal. Introducing wireless communication in both configurations — whether over a public cellular network or a local access point — introduced security risks that needed to be considered and resolved.

. LTE configuration — unauthorised access to the server API endpoints

and replay attacks, in which a previously captured valid request could be retransmitted to inject false data into the server.

. Local Wi-Fi AP configuration — unauthorised network access,

where without link-layer protection any nearby device could join the access point and interact with the web dashboard.

### 3.5.1 LTE Channel Security

The primary configuration utilises a cellular LTE module for remote data transmission. Three security measures were implemented to protect this communication channel.
Transport-Layer Encryption
Transport-layer encryption is ensured by communicating exclusively over HTTPS on port 443, with TLS (Transport Layer Security) termination handled by the Railway infrastructure:
1 | AT+HTTPINIT
2 | AT+HTTPPARA="URL","https://server.railway.app/data"
3 | AT+HTTPPARA="SSLCFG",0
4 | AT+HTTPACTION=1 | // response: +HTTPACTION 1,200,len
5 | AT+HTTPTERM
Listing 3.5: AT command sequence for HTTPS POST request
To maintain robustness across device reboots, the server tolerates a nonce decrease exceeding 10⁹, which indicates that the ESP32-S3 has restarted with a lower boot counter value — for example after a firmware reflash or NVS clear — and resets the accepted baseline accordingly. In all other cases, a non-increasing nonce is rejected as a replay attempt.
1 | if nonce <= last_nonce:
2 | return jsonify({"error": "replay detected"}), 400
3 | last_nonce = nonce
| | 43

3. Design and Implementation of the Device |

Listing 3.6: Server-side replay attack detection

Bearer Token Authentication
Authorisation is provided using the Bearer token authentication method. The secret token is generated using a cryptographically strong random number generator and stored exclusively as a Railway environment variable on the server side and as a compile-time constant in the ESP32-S3 firmware:
1 | SECRET_TOKEN = os.environ.get("SECRET_TOKEN", None)
| Listing 3.7: Bearer token retrieval from environment variable
1 | #define API_TOKEN "generated_token"
| Listing 3.8: Bearer token definition in ESP32-S3 firmware
| HTTP POST requests include an Authorization header carrying the to-
| ken value, which is validated against the server-side environment variable.
| If the token is missing or invalid, the request is rejected with HTTP status
| 401 Unauthorized:
1 | def check_auth(req):
2 | if SECRET_TOKEN is None:
3 | return False
4 | auth = req.headers.get("Authorization", "")
5 | return auth == f"Bearer {SECRET_TOKEN}"
| Listing 3.9: Server-side Bearer token validation
| Replay Attack Prevention
| Replay attacks are prevented by including a nonce field in every payload,
| derived from a persistent boot counter stored in non-volatile memory combined
| with the device uptime via millis(), ensuring the nonce strictly increases
| across device reboots. The server rejects any request where the nonce does
| not strictly exceed the previously accepted value:
1 | if nonce <= last_nonce:
2 | return jsonify({"error": "replay detected"}), 400
3 | last_nonce = nonce
| Listing 3.10: Server-side replay attack detection

44

# | 3.5. Security Analysis

### 3.5.2 Local Wi-Fi Channel Security

The secondary configuration implements the ESP32-S3 serving as a local Wi-Fi access point, providing direct connectivity through a captive portal. Two security measures were implemented for this configuration.
Firstly, network access is secured using WPA2-PSK encryption,
in which the ESP32-S3 soft AP acts as a router. Only users with the correct password are permitted to join the network, and all communication between the client and the device is protected by link-layer encryption.
1 | WiFi.softAP(WIFI_SSID, WIFI_PASSWORD);
| Listing 3.11: WPA2-PSK access point initialization
| Second, a captive portal was implemented using a DNS server running directly on the ESP32-S3. Once the client connects to the access point, the operating system automatically opens the dashboard interface without requiring the user to manually enter the device IP address.
1 | dnsServer.start(DNS_PORT, "*", apIP);
| Listing 3.12: Captive portal DNS server initialization
| Since the access point operates as a standalone local area network with no in- ternet connectivity, link-layer WPA2 encryption is considered sucient for this configuration.

45

3. Design and Implementation of the Device |

## 3.6 Web Dashboard

### 3.6.1 Dashboard Overview

The developed web interface serves as the primary visualization tool for vehicle telemetry. Layout is inspired by modern automotive infotainment systems, focusing on quick readability of all critical parameters. The application can be served either directly from the ESP32-S3 acting as a standalone web server, or hosted externally on a remote server.

Technology Stack
HTML, CSS, and JavaScript are used exclusively in the development of the frontend application. This approach ensures optimal performance in terms of resource usage, since the interface needs to run on the ESP32-S3. Time series charts are created using the open-source library Chart.js, enhanced by the chartjs-plugin-zoom plugin, which enables users to zoom and pan the chart interactively. GPS functionality is implemented using Leaflet.js with map tiles rendered from the Mapbox API. Data are gathered using a polling method with a 200 ms interval (5 Hz), ensuring a sucient sampling rate for the presented parameters.

User Interface Layout
The dashboard is divided into six dedicated screens accessible through a bottom navigation bar, summarised in Table 3.4.
Table 3.4: Dashboard Screen Overview
Screen | Description
Cockpit | Animated radial gauges for engine RPM and vehicle speed, live sparklines and widgets summarising alarms and fuel con- sumption.
Vehicle Overview | Structured view of all available PID values categorised into logi- cal groups (basic readings, temperatures, fuel system, engine...) with a tabular history log.
Live Graphs | Time series plots of selected sensor outputs with detailed inspection of trends or anomalies.
Fuel Consumption | Instantaneous fuel consumption alongside average counters (since start, since refuel, long-term) and a trend graph.
GPS Map | Real-time vehicle position tracking with GPX route export.
Alarms | Configurable threshold limits for critical parameters; exceeding a threshold triggers a visual warning.

Detailed screenshots of all screens are provided in Appendix C.

46

# | 3.6. Web Dashboard

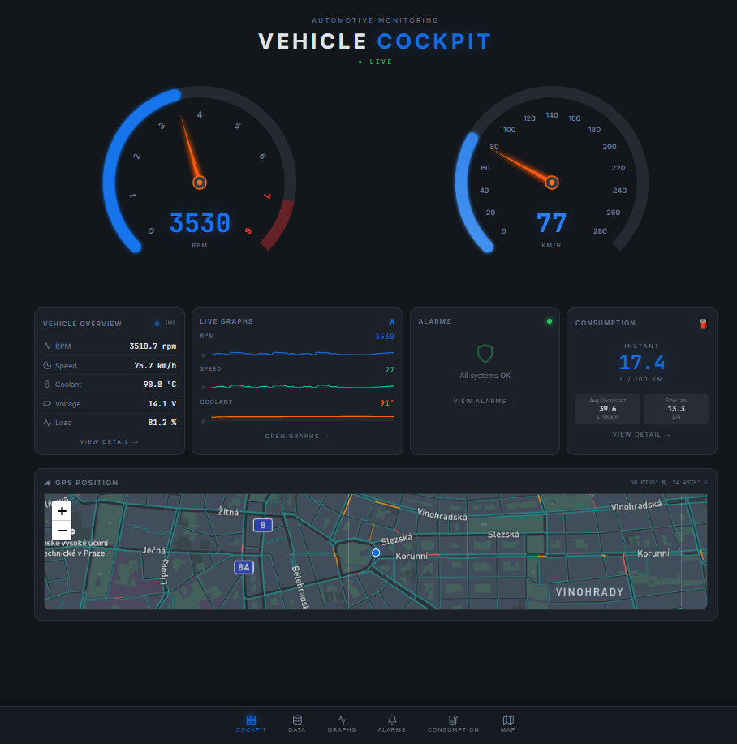
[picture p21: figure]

Figure 3.6: Main Cockpit screen featuring live radial gauges and summary widgets

47

3. Design and Implementation of the Device |

### 3.6.2 Advanced Diagnostics Interface

Beyond the primary scope of this thesis, an advanced diagnostic web interface was developed to serve as a visual and functional foundation for future implementations of remote ECU flashing. However, practical ECU flashing remains a highly complex task requiring vehicle-specific data, as each manufacturer implements proprietary security mechanisms — component protection, virtual component handshakes, seed-and-key authentication, and extensions to the standard UDS protocol. Full ECU programming support therefore remains a subject for future development.
Access to the interface is restricted by a login screen, since it allows direct interaction with the CAN bus and transmission of UDS (Unified Diagnostic Services) queries to the ECU. Session state is stored in the browser via localStorage, which is suficient for the prototype.
The diagnostic view provides three tools:

. Frame Builder — manual construction and periodic transmission

of CAN frames with CAN FD support, bit-rate switching (BRS), and an interactive bit matrix for payload manipulation.

. Live Monitor — real-time CAN trac display with filtering and log

export.

. UDS & Coding — constructs and dispatches ISO-TP requests for

reading data identifiers (DIDs), clearing diagnostic trouble codes (DTCs), and switching diagnostic sessions.
Screenshots of the login screen and diagnostic interface are provided
in Appendix C.

48

# | 3.7. Testing and Validation

## 3.7 Testing and Validation

### 3.7.1 End-to-End Transmission Test

The primary objective of this test was to verify the complete data path from the ESP32-S3, through the SIMCom A7670E LTE modem, across the cellular network, to the Flask application on Railway.app, and finally to the SQLite database. The test isolates the transport layer from the CAN bus and the OBD-II decoder.
The Methodology
For testing purposes, dummy data were generated using the random() function. Each payload contains typical data points (engine RPM, vehicle speed, coolant temperature, throttle, fuel percentage, MAF, system voltage, and GPS location) along with a monotonically increasing nonce derived from millis(). The firmware initiates registration in LTE-only mode using AT+CNMP=38 and automatically falls back to an alternative radio access technology if no LTE cell is detected within 30 seconds. An HTTPS POST request is sent via the command sequence AT+HTTPINIT, AT+HTTPPARA, AT+HTTPDATA, and AT+HTTPACTION on UART1. The Bearer token is carried in the USERDATA HTTP header parameter.

Results
The test ran for approximately 90 seconds without interruption, during which 18 packets were transmitted. All transmissions received HTTP 200 responses, confirmed by the modem prompt +HTTPACTION: 1,200,16 and a response body containing the status field set to "ok". Network registration on LTE was achieved on the first attempt. The signal strength reported by AT+CSQ was 24 (≠65 dBm). The serving network identified by AT+COPS? was O2 Czech Republic (PLMN 23002) on E-UTRAN.
An independent read-back via GET /data confirmed a strictly monotonically increasing sequence of nonce values with consistent timestamps. The total latency of one HTTPS POST transaction, measured between AT+HTTPINIT and the +HTTPACTION: 1,200 notification, was approximately 3 seconds, including DNS resolution, TLS handshake, request transmission, and server-side processing. The corresponding console log is shown below:

49

3. Design and Implementation of the Device |

[INIT] Phase 1: trying LTE-only (CNMP=38)... [AT] AT+CREG? -> +CREG: 0,1 OK
[INIT] Registered on LTE!
[AT] AT+COPS? -> +COPS: 0,2,"23002",7
[AT] AT+CSQ -> +CSQ: 24,99
[INIT] Modem ready for HTTP communication
[HTTP] JSON: {"nonce":14479,"rpm":2267,"speed":63, "coolant_temp":91,"throttle":40,"voltage":13.9, "lat":50.068001,"lon":14.430600}
[AT] AT+HTTPINIT -> OK
[AT] AT+HTTPACTION=1 -> +HTTPACTION: 1,200,16 [AT] AT+HTTPREAD=0,512 -> {"status":"ok"} [STAT] Total: 18 OK: 18 FAIL: 0

Listing 3.12: End-to-end HTTPS POST transaction log

50

# | 3.7. Testing and Validation

### 3.7.2 Vehicle CAN Communication

In order to confirm the end-to-end functionality of the proposed system with regard to data collection, an actual test drive was performed using a real vehicle under dierent driving conditions. Testing was achieved using a äkoda Kodiaq 2.0 TDI (110 kW, 2019) communicating over a CAN bus at 500 kbit/s.
The entire measurement lasted about 13 minutes, comprising various driving phases:⁸

. Cold engine start and gentle pull-away from rest
. Smooth city driving with almost constant speed
. Sustained cruise at 50 km h≠1 to establish a steady-state baseline
. Full-throttle acceleration to 100 km h≠1 to capture peak engine loading . Urban driving with mixed throttle and brake inputs
. Stationary high-RPM run with the vehicle at rest to capture peak engine

speed without load
OBD-II data were sampled at a polling interval of 500 ms per PID and exported to a CSV file for post-processing. The acquired parameters, together with their OBD-II Service 01 PID identifiers and physical interpretation, are listed in Table 3.5.
Table 3.5: OBD-II parameters acquired during the test drive
PID | Parameter | Unit | Description
0x0C | Engine speed | rpm | Rises with throttle input and drops at each gearshift.
0x0D | Vehicle speed | km h≠1 Wheel speed reported via the ABS control unit.
0x05 | Coolant temper- ature | °C | Cylinder-head coolant temperature. Rises gradu- ally from cold start and stabilizes once the ther- mostat opens.
0x0F | Intake air temp. °C | Air temperature downstream of the intercooler.
0x46 | Ambient temp. | °C | External air temperature as estimated by the ECU.
0x10 | Mass air flow | g/s | Air mass entering the intake manifold per second. Peaks mirrors the engine load profile.
0x11 | Throttle position | % | Normalized throttle opening, directly reflecting driver demand. Reaches maximum during the ac- celeration.
0x04 | Engine load | % | ECU-calculated ratio of current to maximum avail- able torque.
0x0B | Intake MAP | kPa | Absolute pressure in the intake manifold.
8Photographs taken from the vehicle cockpit during characteristic phases of the session are included in Appendix D as corroborating evidence for correct logged values.

51

3. Design and Implementation of the Device |

The recorded data are presented in three figures. Figure 3.7 shows engine speed and vehicle speed as functions of time, with the session divided into clearly delimited driving phases for readability. During the initial city driving, the engine and car speeds are relatively low, showing oscillations resulting from multiple pedal presses. During the accelerating stage, there is a simultaneous rise in both plots, whereas during cruising, both become

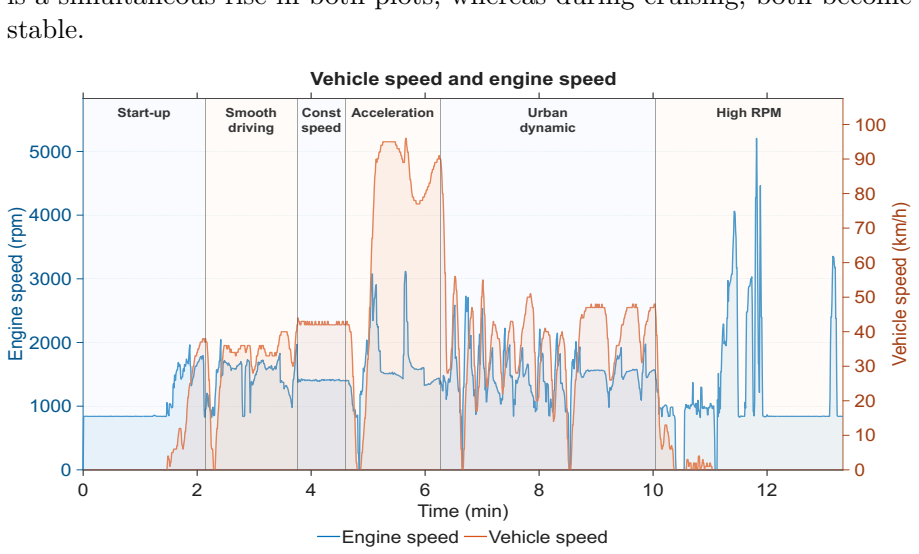
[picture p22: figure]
stable.; Time (min); Engine speed (rpm); Vehicle speed (km/h); 100 Start-up; Smooth; driving; Const speed; Acceleration; Urban; dynamic; High RPM; Vehicle speed and engine speed; Engine speed; Vehicle speed

Figure 3.7: Recorded engine speed and vehicle speed over the test session.

Figure 3.8 presents throttle position, engine load, and intake manifold pressure over the same time base. During the full-throttle acceleration run, all three quantities rise sharply and in a physically consistent manner, with MAP climbing well above the ambient value of approximately 100 kPa, confirming active turbocharger operation. During steady-state cruise, engine load settles at a moderate level while throttle position remains nearly constant.

52

# | 3.7. Testing and Validation

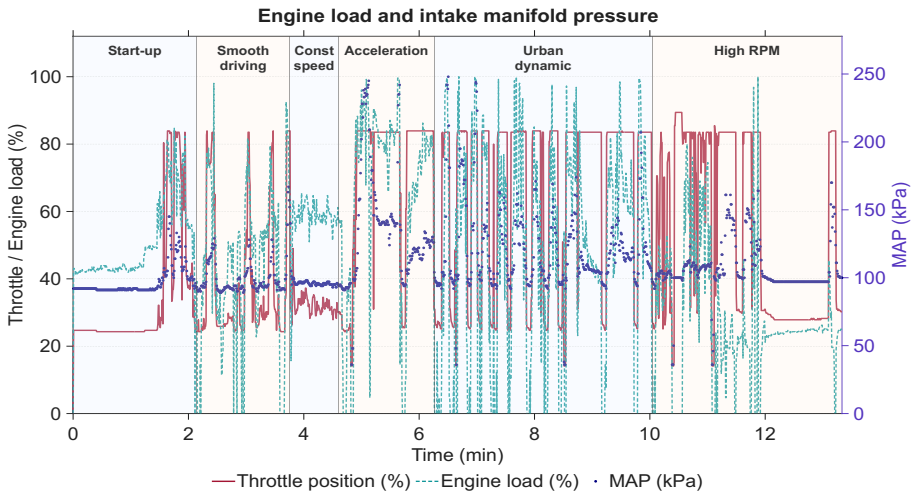
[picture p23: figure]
Time (min); Throttle / Engine load (%); AP (kPa); Start-up; Smooth; driving; Const speed; Acceleration; Urban; dynamic; High RPM; Throttle position (%); Engine load (%); MAP (kPa)

Engine load and intake manifold pressure

Figure 3.8: Throttle position, engine load, and intake manifold pressure.

Figure 3.9 covers coolant temperature, intake air temperature, ambient temperature, and mass air flow. Coolant temperature rises steadily from the coldstart value and stabilises once the thermostat opens, while the MAF trace closely mirrors the engine load profile throughout the session.

Time (min)

0 | 2 | 4 | 6 | 8 | 10 | 12

Temperature (°C)

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
AF (g/s)

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
Start-up | Smooth | 180
| driving

Const
speed
Acceleration | Urban
dynamic

High RPM

Thermal parameters and mass air flow

Coolant temp. | Intake air temp. | Ambient temp. | MAF
Figure 3.9: Coolant temperature, intake air temperature, ambient temperature, and mass air flow rate.

53

3. Design and Implementation of the Device |

### 3.7.3 Power Measurements

In this chapter, the CAN Bus Snierss power consumption was evaluated to obtain real-world data for the power management. The measurements were performed using the Nordic Power Profiler Kit II (PPK2), which oers a high sampling rate of 100 kHz. Because this rapidly generates millions of data points, screenshots from the Nordic Power Profiler application are visualized. Exporting and externally downsampling such massive datasets risks losing crucial short-duration peaks, whereas the native app safely preserves them using an optimized min/max envelope approach.

Figure 3.10 illustrates the current draw during the LTE module’s initialization, network registration, and the transmission of a TCP payload. During the initial boot and initialization phase, the current fluctuates between 60 mA and 115 mA. This is followed by a stabilization period with an idle current draw of approximately 60 to 80 mA. A significant peak of roughly 400 mA is then observed during the actual TCP packet transmission.

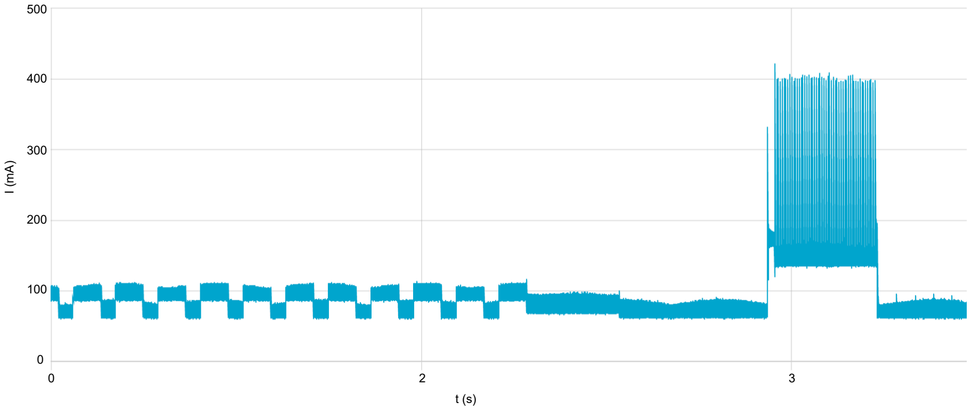
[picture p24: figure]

Figure 3.10: Current draw during LTE module initialization and TCP payload transmission.

54

# | 3.7. Testing and Validation

The system’s power consumption in dierent low-power states is compared in Figure 3.11. During the light sleep phase, the measured current draw settled at approximately 26 mA. The subsequent deep sleep period showed a marginally lower consumption of around 20 mA. The relatively modest dierence between the two modes is likely attributable to residual peripheral activity—most notably the LTE modem has fully completed its shutdown

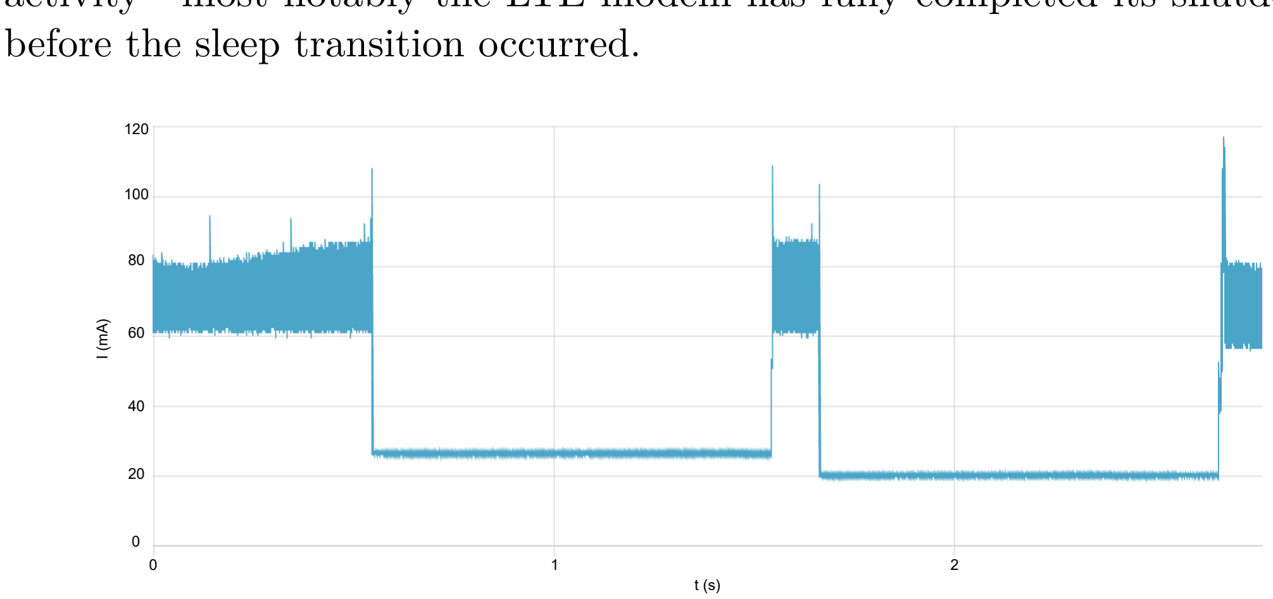
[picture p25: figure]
before the sleep transition occurred.

Figure 3.11: System power consumption comparison between light sleep and deep sleep modes.

55

3. Design and Implementation of the Device |

## 3.8 Final Devices

As mentioned before, two prototypes were assembled: one equipped with an LTE module to handle direct connection to the server, and a second variant functioning solely as a Wi-Fi Access Point (AP) utilizing the ESP32 captive portal.

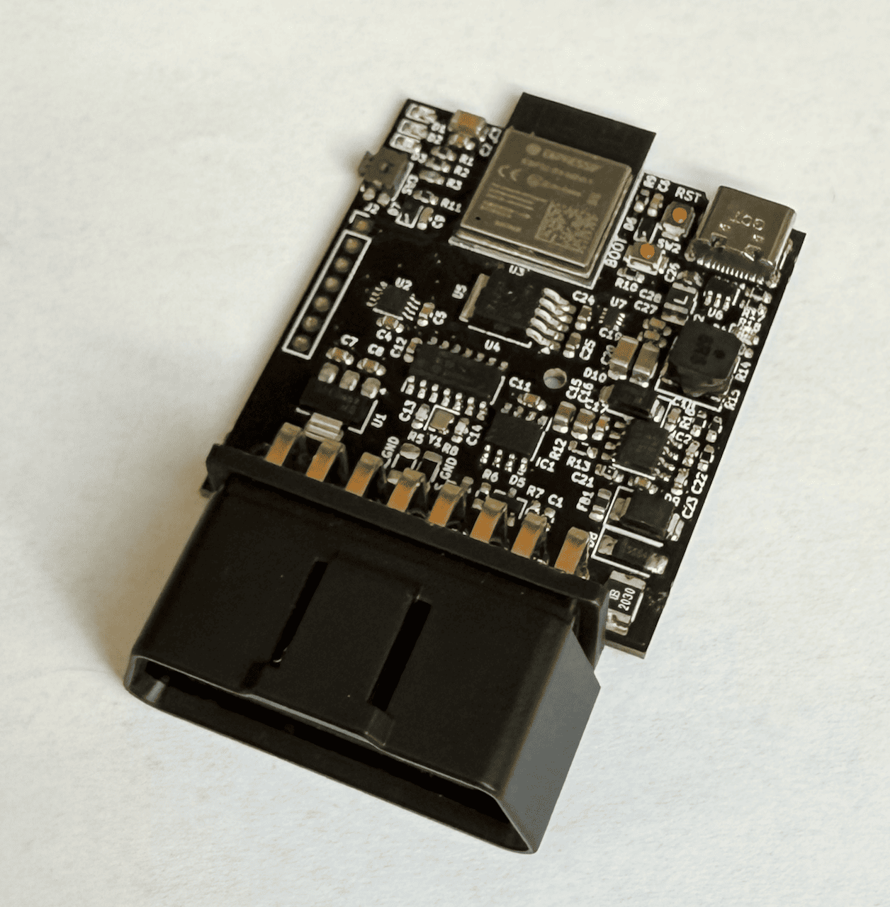
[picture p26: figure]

LTE device | Wi-Fi AP device

### 3.8.1 Web Server Endpoint

The data from the diagnostic device is transmitted and visualized on a custom web dashboard. The main endpoint receiving the telemetry data is available at:
https://canbussnifferv1-production.up.railway.app

56

# | 3.8. Final Devices

### 3.8.2 Power Management

Since the device operates continuously in the automotive environment, power eciency is critical. To prevent draining the vehicle’s battery when the engine is turned o, firmware uses a three-state FSM driven by CAN trac detection: driving æ idle_awake after 60 s of bus silence æ light_sleep after 5 min idle. In sleep, the modem enters AT+CSCLK=1 and the ESP32-S3 enters native light sleep with RAM retention; the device wakes every 60 s to recheck CAN Bus. Average current draw per phase is summarized in Table 3.6. Table 3.6: Measured current draw per operating phase. FSM Phase Measured current
driving | ¥ 400 mA
idle_awake | ¥ 86 mA
light_sleep | ¥ 26 mA
deep_sleep | ¥ 20 mA

For calculation, a typical 60 Ah vehicle battery was used. The maximum safe parking endurance T is derived from the usable battery capacity Cusable, limiting depth-of-discharge to 50 % to retain cranking ability:

T = Cusable
I sleep

= 0.5 ◊ 60,000 mAh
26 mA

¥ 1, 154 h ¥ 48 days. (3.2)

This calculated time is well above the typical use-case. This proves that light sleep mode is enough to protect the car’s battery during long-time parking.

### 3.8.3 Data Payload

Each transmission consists of a fixed overhead O and a variable payload P(n) depending on the number of supported PIDs n:
Bsend = O + P(n). | (3.3)
The fixed overhead covers the TLS 1.2 handshake, HTTP POST header, and server response:
O = OTLS + OHTTP + Oresp ¥ 5500 + 225 + 150 = 5875 B. (3.4) The payload size diers between the two packet types. The fast packet encodes only four parameters; the full packet encodes all n supported PIDs:

Pfast = Bbase +4 ¯
k, | (3.5)
Pfull(n)= Bbase + n ¯
k, | (3.6)
where Bbase ¥ 30 B is the fixed JSON envelope (nonce, type, lat, lon) and ¯
k ¥ 16 B is the mean length of one key-value pair. For the äkoda Kodiaq

57

3. Design and Implementation of the Device |

tested in this work, 9 PIDs were identified as supported. Substituting n =9 into equations (3.5) and (3.6):
Pfast = 30 + 4 ◊ 16 = 94 B, Pfull(9) = 30 + 9 ◊ 16 = 174 B. Field measurements confirmed values of 95 B and 179 B respectively. The system sends two fast packets and one full packet every 6 s, giving:
Vhour = 3600
6

!

2 Bfast + Bfull"
= 600 · (2 ◊ 5969 + 6049) ¥ 10.3 MB/h. (3.7)

The payload contribution alone (excluding TLS overhead) is ¥ 0.2 MB/h. The dominant term is the TLS handshake re-established on every POST, a consequence of the Connection: close behavior of the A7670E HTTPINIT stack. Table 3.7 summarizes the projected consumption for 4 hours of daily driving.
Table 3.7: Projected cellular data consumption (4 h/day, n =9 PIDs).
Period | Payload only Total (incl. TLS)
Day (4 h) | 0.7 MB | 41.2 MB
Month | 20 MB | 1.24 GB
Year | 0.24 GB | 14.7 GB

58
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

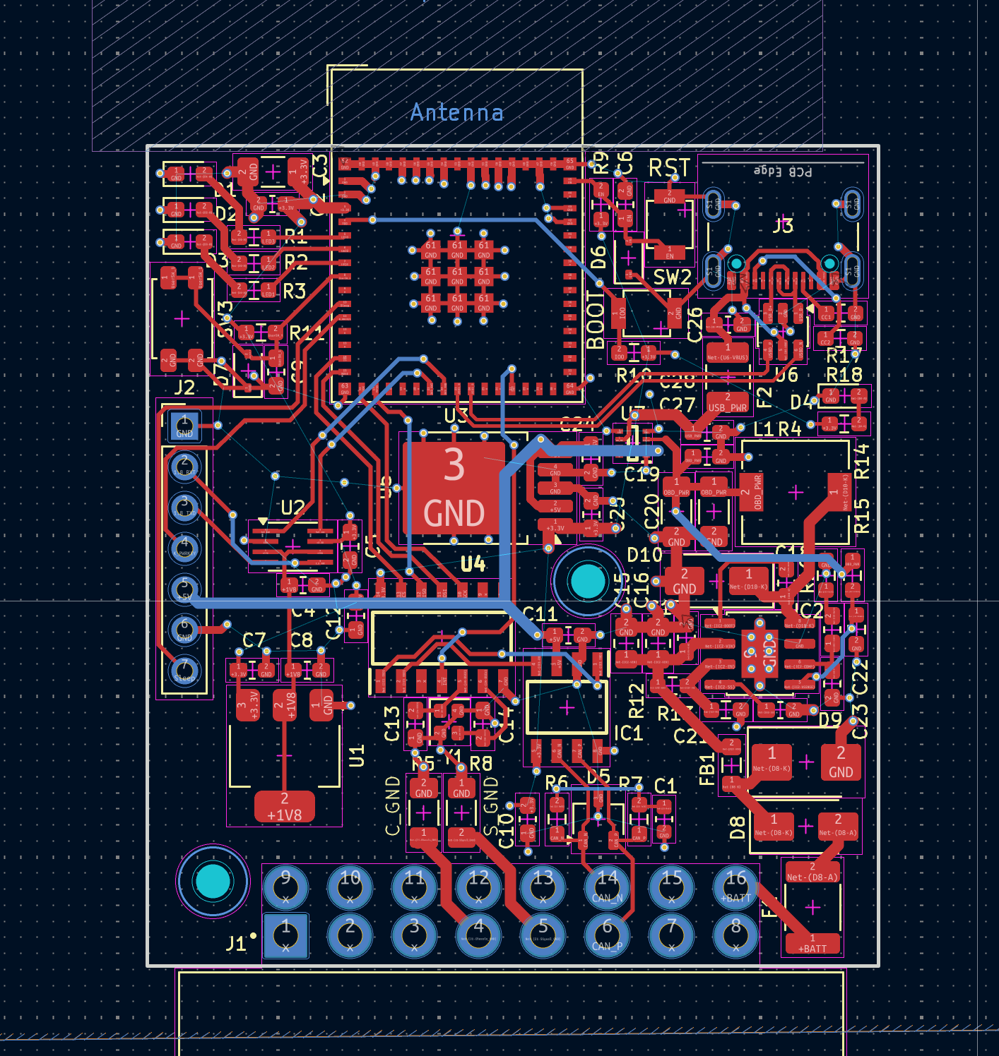
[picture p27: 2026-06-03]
pcb-design/Images/CanBus_Sniffer_v1_PCB.png

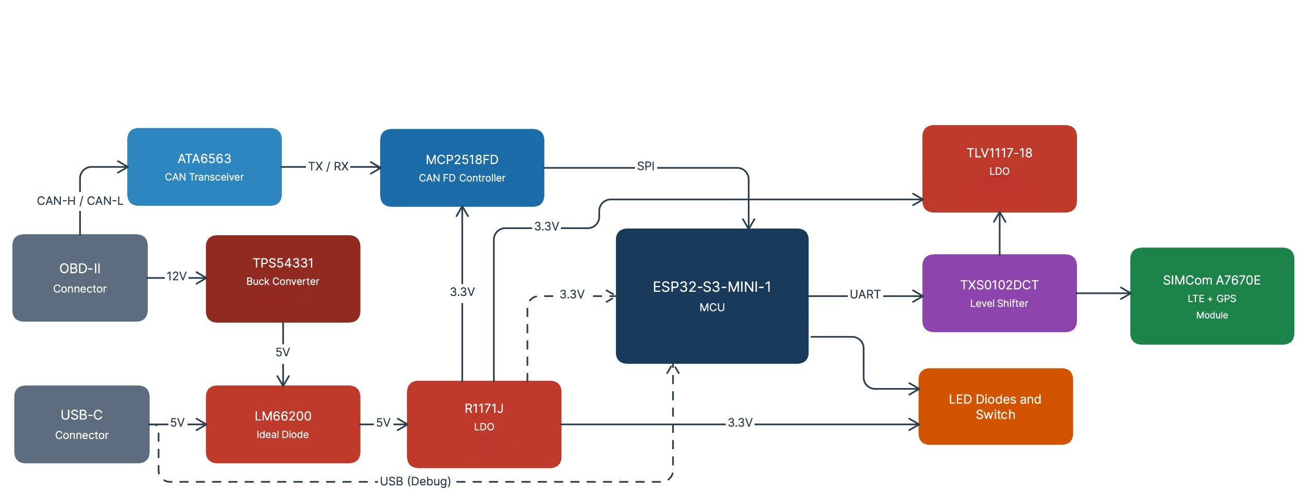
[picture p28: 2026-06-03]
pcb-design/Images/block-diagram.png

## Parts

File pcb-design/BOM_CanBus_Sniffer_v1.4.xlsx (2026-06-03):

Reference | Qty | Value | DNP | Exclude from BOM | Exclude from Board | Footprint | Datasheet | Mouser No | Mouser Part Number | Place | Note
Y1 | 1 | 40MHz |  |  |  | Crystal:Crystal_SMD_2016-4Pin_2.0x1.6mm | https://eu.mouser.com/datasheet/3/184/1/ABM11W.pdf | 815-11W40-8D1XT |  | YES
U7 | 1 | LM66200DRLR |  |  |  | Soucastky:SOTFL50P160X60-8N | https://www.ti.com/lit/ds/symlink/lm66200.pdf?ts=1772363227657 | 595-LM66200DRLR | 595-LM66200DRLR | YES
U6 | 1 | USBLC6-2SC6 |  |  |  | Package_TO_SOT_SMD:SOT-23-6 | https://www.st.com/resource/en/datasheet/usblc6-2.pdf | 511-USBLC6-2SC6 |  | YES
U5 | 1 | R1171J331D-T1-F |  |  |  | Package_TO_SOT_SMD:TO-252-5_TabPin3 | https://www.nisshinbo-microdevices.co.jp/en/pdf/datasheet/r1171-ea.pdf | 848-R1171J331DT1F |  | YES
U4 | 1 | MCP2518FD-xQBB |  |  |  | Soucastky:SOIC127P600X175-14N | https://cz.mouser.com/datasheet/3/282/1/External-CAN-FD-Controller-with-SPI-Interface-DS20006027B.pdf | 579-MCP2518FDT-E/SL |  | YES
U3 | 1 | ESP32-S3-MINI-1 |  |  |  | RF_Module:ESP32-S2-MINI-1 | https://documentation.espressif.com/esp32-s3-mini-1_mini-1u_datasheet_en.pdf | 356-ESP32-S3-MINI1N8 |  | YES
U2 | 1 | TXS0102DCT |  |  |  | Package_SO:SSOP-8_2.95x2.8mm_P0.65mm | https://www.ti.com/lit/ds/symlink/txs0102v.pdf?ts=1771762179181 | 595-TXS0102VDCTR |  | YES
U1 | 1 | TLV1117-18 |  |  |  | Package_TO_SOT_SMD:SOT-223-3_TabPin2 | https://www.ti.com/lit/ds/symlink/tlv1117lv.pdf?ts=1771812118964 | 595-TLV1117LV18DCYR |  | YES
SW3 | 1 | User_BTN1 |  |  |  | Button_Switch_SMD:SW_SPST_EVQP2_ShortPushTravel_H2.5mm | https://4donline.ihs.com/images/VipMasterIC/IC/PANA/PANA-S-A0003211477/PANA-S-A0004028532-1.pdf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 | 667-EVQ-PUJ02K |  | YES
SW2 | 1 | Boot_BTN |  |  |  | Button_Switch_SMD:SW_SPST_TL1017 | https://www.mouser.com/catalog/specsheets/E-Switch_TL1017.pdf | 612-TL1017AAAF260QG |  | YES
SW1 | 1 | Reset_BTN |  |  |  | Button_Switch_SMD:SW_SPST_TL1017 | https://www.mouser.com/catalog/specsheets/E-Switch_TL1017.pdf | 612-TL1017AAAF260QG |  | YES
R17,R18 | 2 | 5.1K |  |  |  | Resistor_SMD:R_0603_1608Metric_Pad0.98x0.95mm_HandSolder | ~ | 71-RCS06035K10FKEA |  | YES
R16 | 1 | 29.4k |  |  |  | Resistor_SMD:R_0603_1608Metric_Pad0.98x0.95mm_HandSolder | ~ | 71-CRCW060329K4FKEAH |  | YES
R15 | 1 | 1.91k |  |  |  | Resistor_SMD:R_0603_1608Metric_Pad0.98x0.95mm_HandSolder | ~ | 71-CRCW0603-1.91K-E3 |  | YES
R13 | 1 | 68.1k |  |  |  | Resistor_SMD:R_0603_1608Metric_Pad0.98x0.95mm_HandSolder | ~ | 755-ESR03EZPF6812 |  | YES
R12 | 1 | 332k |  |  |  | Resistor_SMD:R_0603_1608Metric_Pad0.98x0.95mm_HandSolder | ~ | 667-ERJ-PA3F3323V |  | YES
R9,R10,R11,R14 | 4 | 10k |  |  |  | Resistor_SMD:R_0603_1608Metric_Pad0.98x0.95mm_HandSolder | ~ | 71-CRCW060310K0FKEE |  | YES
R8 | 1 | 0R |  |  |  | Resistor_SMD:R_1206_3216Metric_Pad1.30x1.75mm_HandSolder | ~ | 71-RCS12060000Z0EA |  | YES
R6,R7 | 2 | 60R | DNP |  |  | Resistor_SMD:R_0603_1608Metric_Pad0.98x0.95mm_HandSolder | ~ | 72-P0603C60R0BNT |  | NO | Optional impedance matching
R5 | 1 | 0R | DNP |  |  | Resistor_SMD:R_1206_3216Metric_Pad1.30x1.75mm_HandSolder | ~ | 71-RCS12060000Z0EA |  | NO | Optional - Chassis GND
R3 | 1 | 100R |  |  |  | Resistor_SMD:R_0603_1608Metric_Pad0.98x0.95mm_HandSolder | ~ | 603-SR0603FR-7T100RL |  | YES
R2 | 1 | 56R |  |  |  | Resistor_SMD:R_0603_1608Metric_Pad0.98x0.95mm_HandSolder | ~ | 71-CRCW060356R0FKEAH |  | YES
R1,R4 | 2 | 270R |  |  |  | Resistor_SMD:R_0603_1608Metric_Pad0.98x0.95mm_HandSolder | ~ | 71-CRCW0603270RFKEAH |  | YES
L1 | 1 | 6.8uH |  |  |  | Inductor_SMD:L_6.3x6.3_H3 | https://product.tdk.com/system/files/dam/doc/product/inductor/inductor/smd/catalog/inductor_commercial_power_vls6045ex_en.pdf | 810-VLS6045EX-6R8M |  | YES
J3 | 1 | USB_C_Receptacle_USB2.0_16P |  |  |  | Connector_USB:USB_C_Receptacle_GCT_USB4105-xx-A_16P_TopMnt_Horizontal | https://www.mouser.com/catalog/specsheets/Global_Connector_Technology_usb4105.pdf | 640-USB4105-GF-A-120 |  | YES
J2 | 1 | Conn_01x07_Pin |  |  |  | Connector_PinHeader_2.54mm:PinHeader_1x07_P2.54mm_Vertical | Headers & Wire Housings RECEPTACLE STRIP 7P 2.54MM PITCH | 737-RS1-07-G |  | YES
J1 | 1 | C-OBD-II-16M |  |  |  | Soucastky:COMTECH_C-OBD-II-16M |  |  |  | YES
IC2 | 1 | TPS54331DR |  |  |  | Package_SO:SOIC-8-1EP_3.9x4.9mm_P1.27mm_EP2.29x3mm | http://www.ti.com/lit/gpn/tps54331 | 595-TPS54331DR | 595-TPS54331DR | YES
IC1 | 1 | ATA6563-GAQW1 |  |  |  | Soucastky:SOIC127P600X175-8N | https://cz.mouser.com/datasheet/3/282/1/ATA6562.3-Data-Sheet-20005790E.pdf | 579-ATA6563-GAQW1 | 579-ATA6563-GAQW1 | YES
H1,H2 | 2 | MountingHole |  | Excluded from BOM |  | MountingHole:MountingHole_2.1mm | ~ |  |  | YES
FB1 | 1 | FerriteBead |  |  |  | Inductor_SMD:L_0805_2012Metric_Pad1.05x1.20mm_HandSolder | https://eu.mouser.com/datasheet/3/76/1/ENFA0005.pdf | 81-BLM21PG121SN1D |  | YES
F2 | 1 | Polyfuse 2A |  |  |  | Resistor_SMD:R_1210_3225Metric_Pad1.30x2.65mm_HandSolder | https://www.littelfuse.com/assetdocs/1210l_datasheet_update.pdf?assetguid=b3a2be92-83a1-491d-9c6d-dc64451de047 | 576-1210L200PR |  | YES
F1 | 1 | Polyfuse 2A |  |  |  | Fuse:Fuse_1812_4532Metric_Pad1.30x3.40mm_HandSolder | https://cz.mouser.com/datasheet/3/508/1/SMD1812_1.pdf | 603-SMD1812B200TF/30 |  | YES
D9 | 1 | SMBJ16A |  |  |  | Diode_SMD:D_SMB | https://www.littelfuse.com/assetdocs/tvs-diodes-smbj-series-datasheet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 | 576-SMBJ16A |  | YES
D8 | 1 | D_Schottky |  |  |  | Diode_SMD:D_SMA | https://cz.mouser.com/datasheet/3/819/1/20190806174558.pdf | 750-SS54F-HF |  | YES
D10 | 1 | D_Schottky |  |  |  | Diode_SMD:D_SMA | https://4donline.ihs.com/images/VipMasterIC/IC/DIOD/DIOD-S-A0012950415/DIOD-S-A0012994412-1.pdf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 | 621-B340AE-13 |  | YES
D6,D7 | 2 | ESD_3.3 |  |  |  | Diode_SMD:D_SOD-323 | https://eu.mouser.com/datasheet/3/175/1/D5V0L1B2WS.pdf | 621-D5V0L1B2WS-7 |  | YES
D5 | 1 | ESD2CAN24DBZRQ1 |  |  |  | Package_TO_SOT_SMD:TSOT-23 | https://www.ti.com/lit/ds/symlink/esd2canxl24-q1.pdf?ts=1771760373626 | 595-ESD2CAN24DBZRQ1 | 595-ESD2CAN24DBZRQ1 | YES
D3 | 1 | Green |  |  |  | LED_SMD:LED_0603_1608Metric_Pad1.05x0.95mm_HandSolder | ~ | 78-VLMTG1400-GS08 |  | YES
D2 | 1 | Blue |  |  |  | LED_SMD:LED_0603_1608Metric_Pad1.05x0.95mm_HandSolder | ~ | 743-S63BT5B |  | YES
D1,D4 | 2 | Red |  |  |  | LED_SMD:LED_0603_1608Metric_Pad1.05x0.95mm_HandSolder | ~ | 710-150060RS75003 |  | YES
C24,C25 | 2 | 4.7u |  |  |  | Capacitor_SMD:C_0603_1608Metric_Pad1.08x0.95mm_HandSolder | https://pim.murata.com/asset/pim4/ceramicCapacitorSMD/GRM188Z71C475KE21-01A-EN_PDF_CERAMICCAPACITORSMD | 81-GRM188Z71C475KE1D |  | YES
C23 | 1 | 47p |  |  |  | Capacitor_SMD:C_0603_1608Metric_Pad1.08x0.95mm_HandSolder | https://www.vishay.com/docs/28548/vjw1bcbascomseries.pdf | 77-VJ0603A470JXXPBC |  | YES
C22 | 1 | 1n |  |  |  | Capacitor_SMD:C_0603_1608Metric_Pad1.08x0.95mm_HandSolder | https://cz.mouser.com/datasheet/3/508/1/UPY-AC_NP0X7RX7S_6.3V-to-2KV_21.pdf | 603-AC603KRX7R8BB102 |  | YES
C21 | 1 | 0.01u |  |  |  | Capacitor_SMD:C_0603_1608Metric_Pad1.08x0.95mm_HandSolder | https://product.tdk.com/system/files/dam/doc/product/capacitor/ceramic/mlcc/catalog/mlcc_automotive_general_en.pdf | 810-CGA3E2X7R1H103K |  | YES
C19,C20 | 2 | 47u |  |  |  | Resistor_SMD:R_1206_3216Metric_Pad1.30x1.75mm_HandSolder | https://www.mouser.com/catalog/specsheets/Tayio_Yuden_1102023_MS_mlcc_all_e.pdf | 963-MSASE31LBB5476MT |  | YES
C17 | 1 | 10n |  |  |  | Capacitor_SMD:C_0603_1608Metric_Pad1.08x0.95mm_HandSolder | https://product.tdk.com/system/files/dam/doc/product/capacitor/ceramic/mlcc/catalog/mlcc_automotive_general_en.pdf | 810-CGA3E2X7R1H103K |  | YES
C15,C16 | 2 | 4.7u |  |  |  | Resistor_SMD:R_0805_2012Metric_Pad1.20x1.40mm_HandSolder | https://product.tdk.com/system/files/dam/doc/product/capacitor/ceramic/mlcc/catalog/mlcc_automotive_general_en.pdf | 810-CGA4J1X7R1H475K1 |  | YES
C13,C14 | 2 | 12p |  |  |  | Capacitor_SMD:C_0603_1608Metric_Pad1.08x0.95mm_HandSolder | https://datasheets.kyocera-avx.com/AutoMLCC.pdf | 581-06033A120J4T2A |  | YES
C27,C28 | 2 | 1u |  |  |  | Capacitor_SMD:C_0603_1608Metric_Pad1.08x0.95mm_HandSolder | https://cz.mouser.com/datasheet/3/317/1/WTC_MLCC_General_Purpose.pdf,~ | 791-0603B105K160CT |  | YES
C6,C9 | 2 | 1u |  |  |  | Capacitor_SMD:C_0603_1608Metric_Pad1.08x0.95mm_HandSolder |  | 187-CL10A105KO8NNNL |  | YES
C3 | 1 | 22u |  |  |  | Capacitor_SMD:C_1206_3216Metric_Pad1.33x1.80mm_HandSolder | https://www.mouser.com/catalog/specsheets/Tayio_Yuden_1102023_MS_mlcc_all_e.pdf | 963-MSASE31LBB7226MT |  | YES
C2,C4,C5,C7,C8,C10,C11,C12,C26 | 9 | 0.1u |  |  |  | Capacitor_SMD:C_0603_1608Metric_Pad1.08x0.95mm_HandSolder | https://cz.mouser.com/datasheet/3/508/1/UPY_GPHC_X7R_6_3V_TO_250V.pdf,https://product.tdk.com/system/files/dam/doc/product/capacitor/ceramic/mlcc/catalog/mlcc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 | 810-C1608X7R1E104M |  | YES
C18 | 1 | 0.1u |  |  |  | Capacitor_SMD:C_0603_1608Metric_Pad1.08x0.95mm_HandSolder | https://cz.mouser.com/datasheet/3/508/1/UPY_GPHC_X7R_6_3V_TO_250V.pdf | 603-CC603KRX7R8BB104 |  | YES
C1 | 1 | 4.7n | DNP |  |  | Capacitor_SMD:C_0603_1608Metric | ~ | 581-KAM15AR72A472JT (https://cz.mouser.com/ProductDetail/KYOCERA-AVX/KAM15AR72A472JT?qs=Jm2GQyTW%2FbiFgDMbGbJwiQ%3D%3D) |  | YES | Optional impedance matching

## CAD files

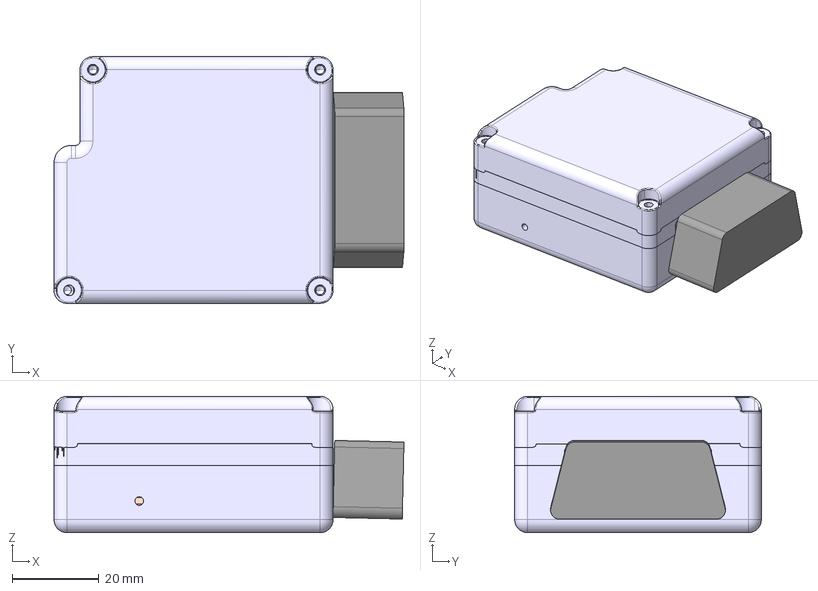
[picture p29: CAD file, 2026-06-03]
3D-print-case/SESTAVA_OBDI_JEDNOTKA.stp
80.9 x 57.0 x 31.5 mm
OBDI_ELEKTRONIKA
KRABICE
SIM_MODUL
ANTENA_1
ANTENA_2
KRABICE_VRSEK_NIZKA
KRABICE_VRSEK_VYSOKA

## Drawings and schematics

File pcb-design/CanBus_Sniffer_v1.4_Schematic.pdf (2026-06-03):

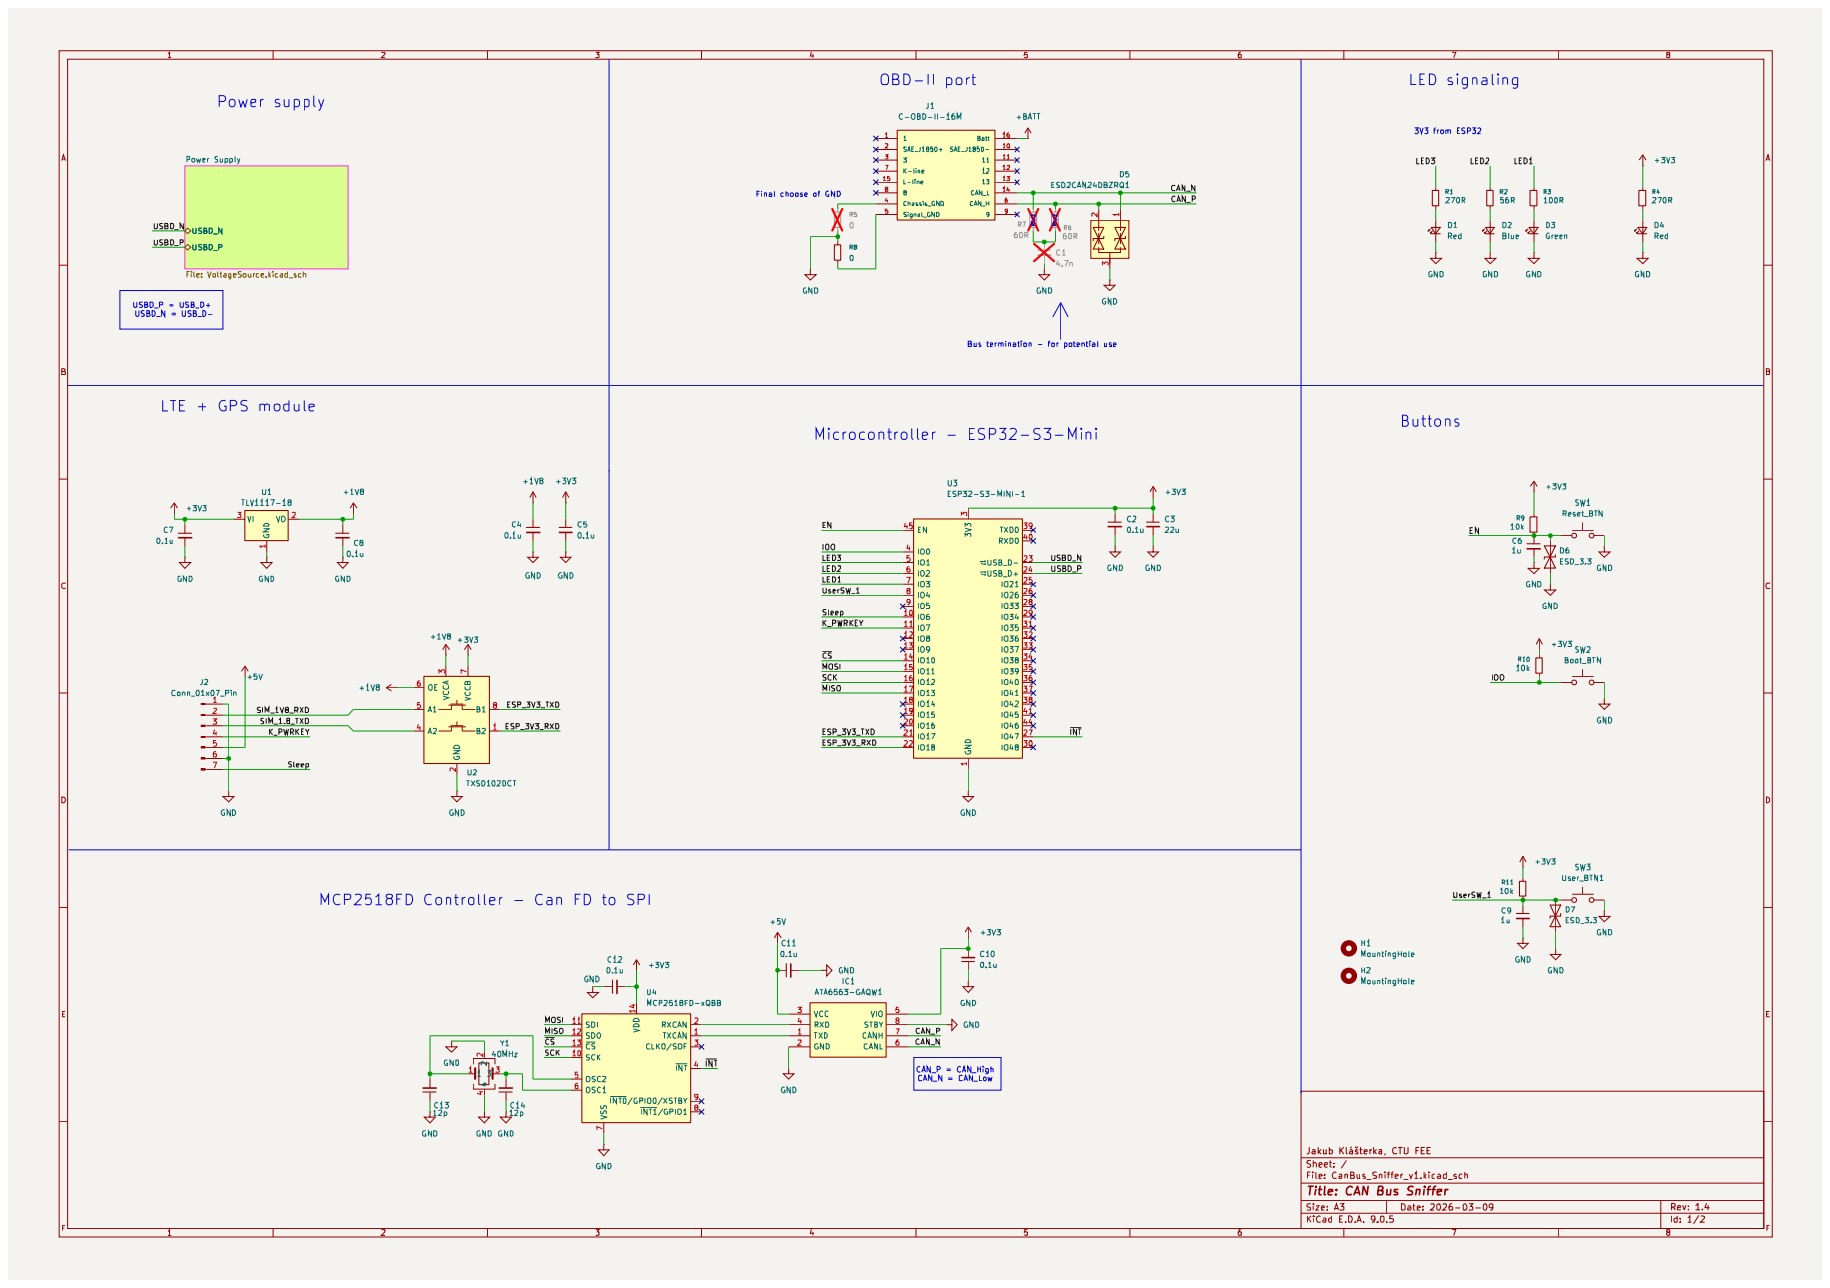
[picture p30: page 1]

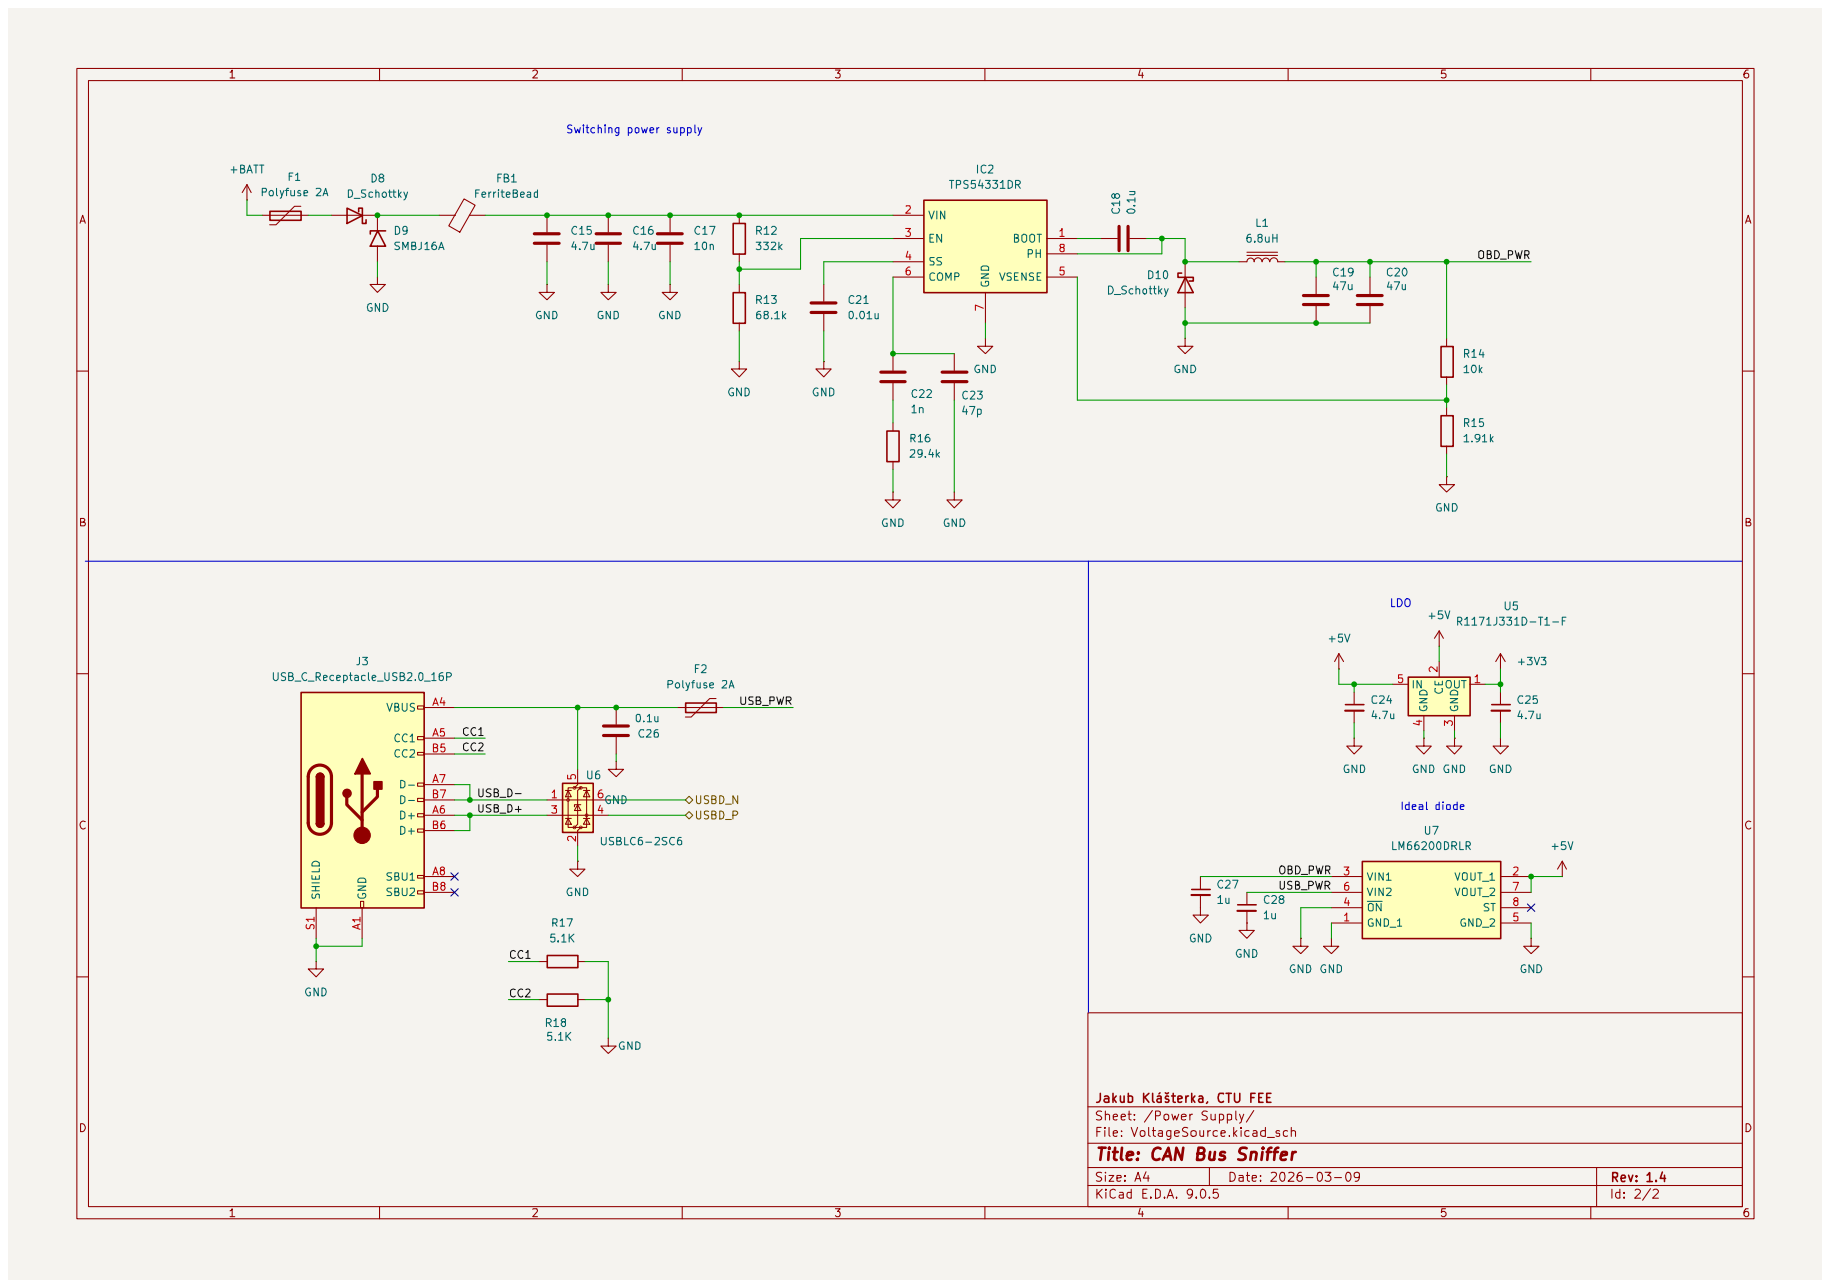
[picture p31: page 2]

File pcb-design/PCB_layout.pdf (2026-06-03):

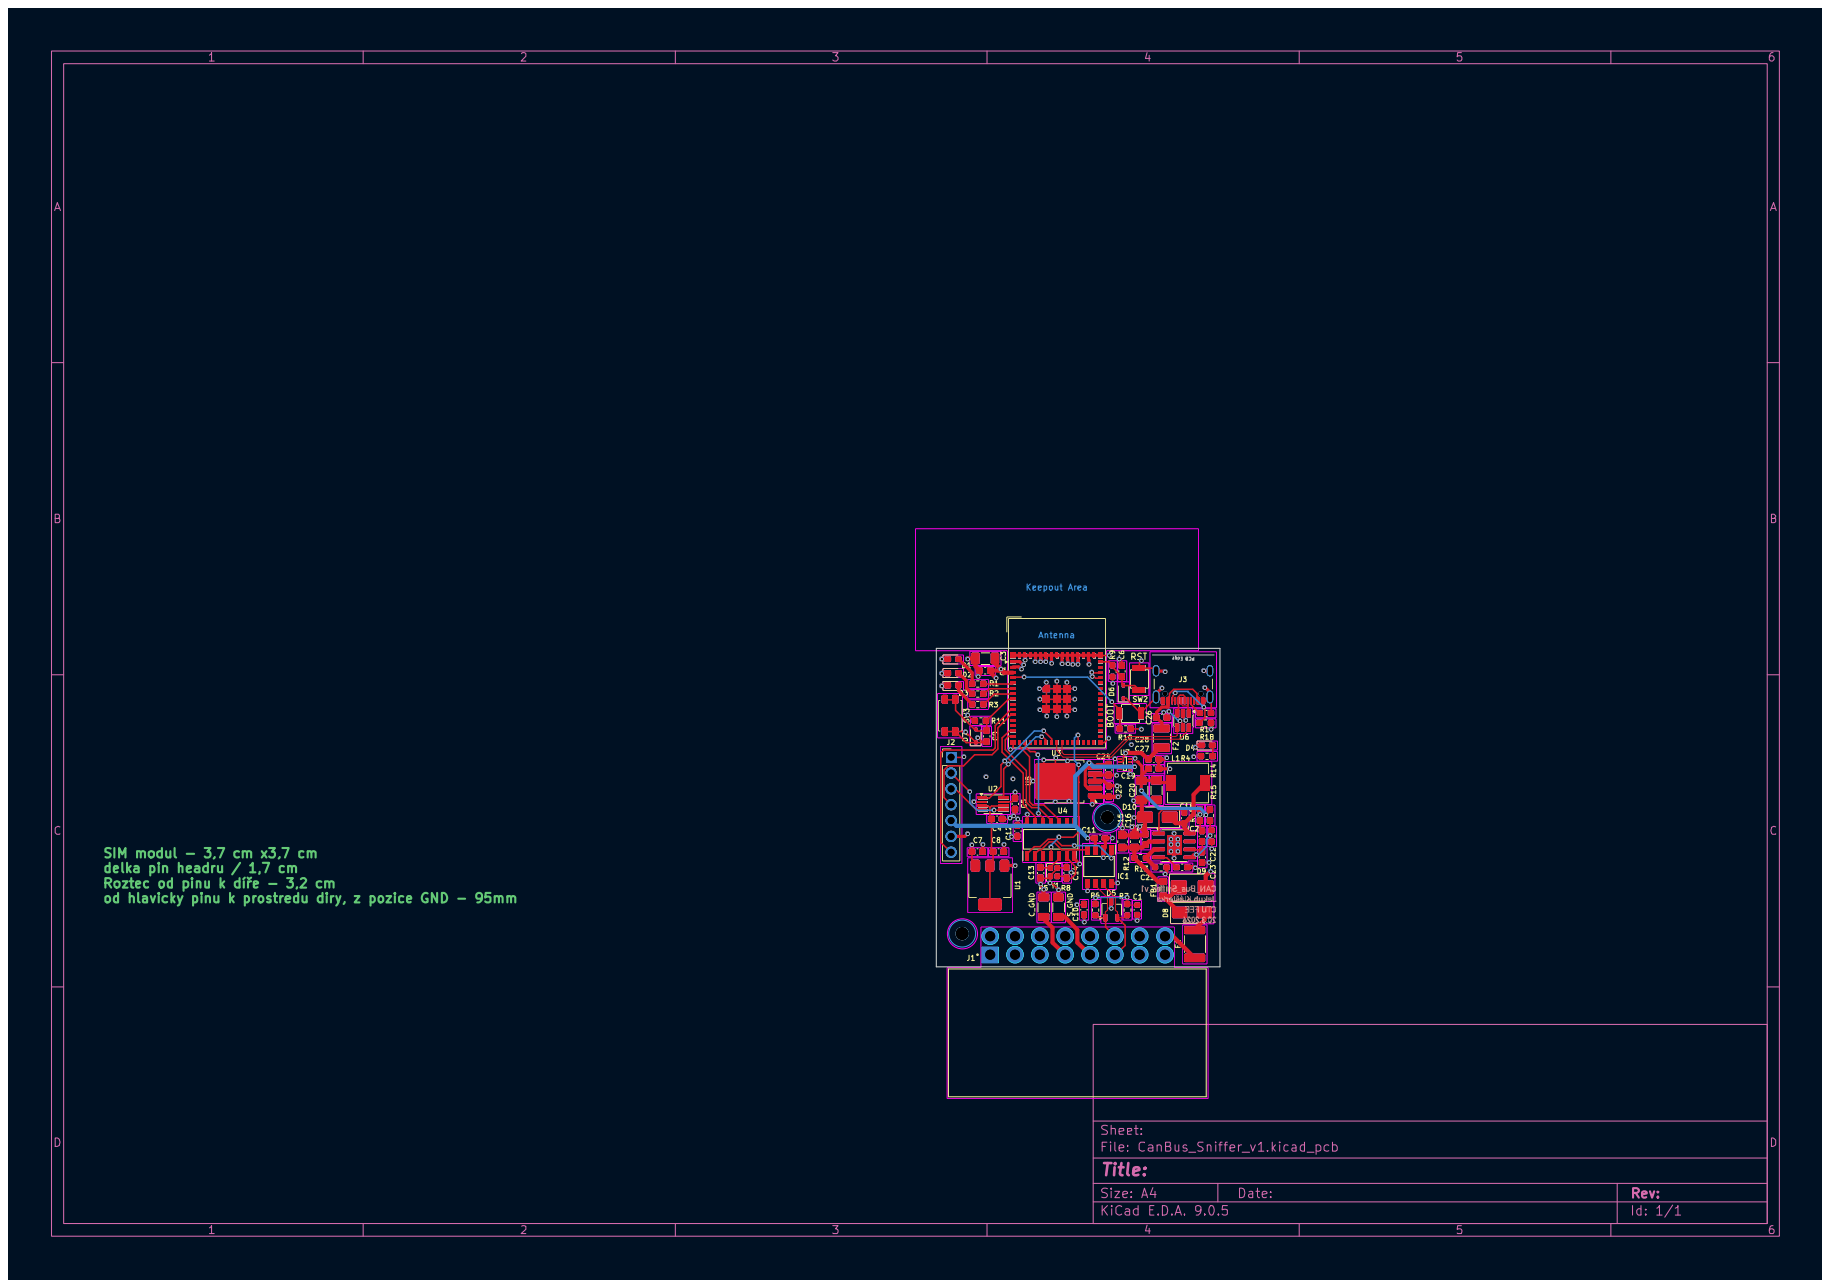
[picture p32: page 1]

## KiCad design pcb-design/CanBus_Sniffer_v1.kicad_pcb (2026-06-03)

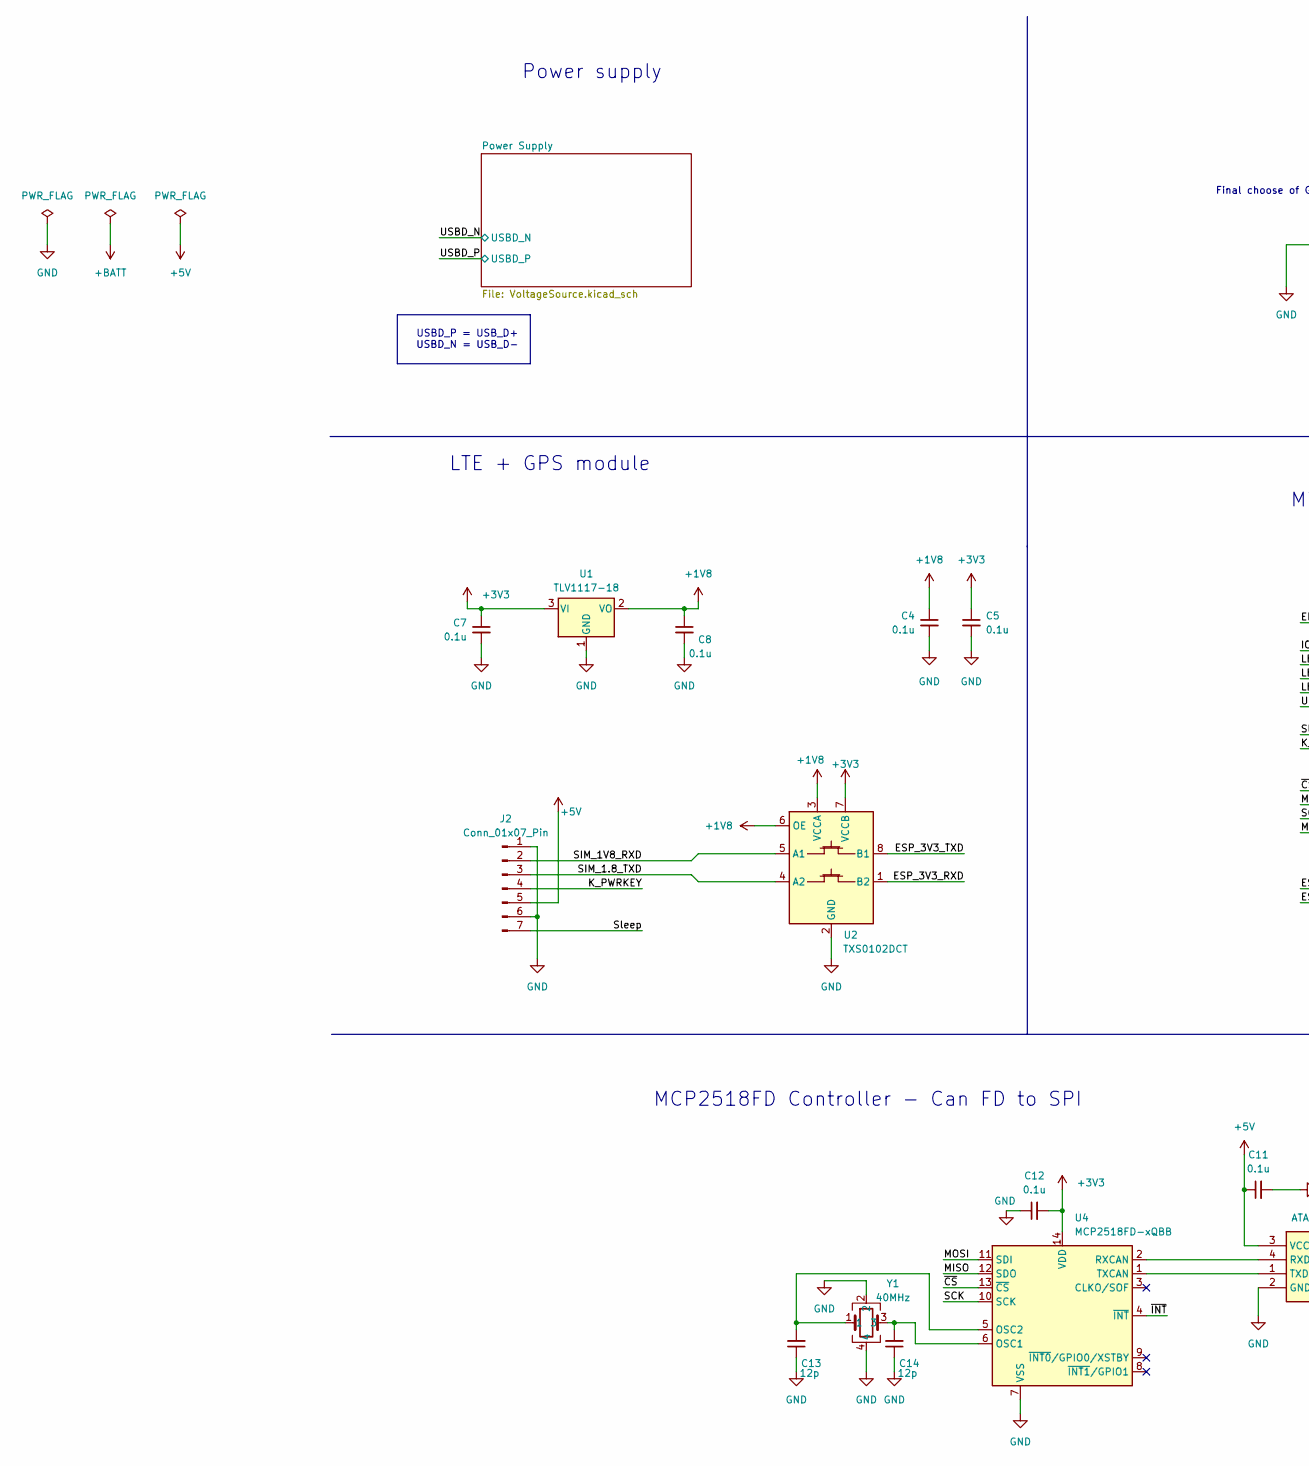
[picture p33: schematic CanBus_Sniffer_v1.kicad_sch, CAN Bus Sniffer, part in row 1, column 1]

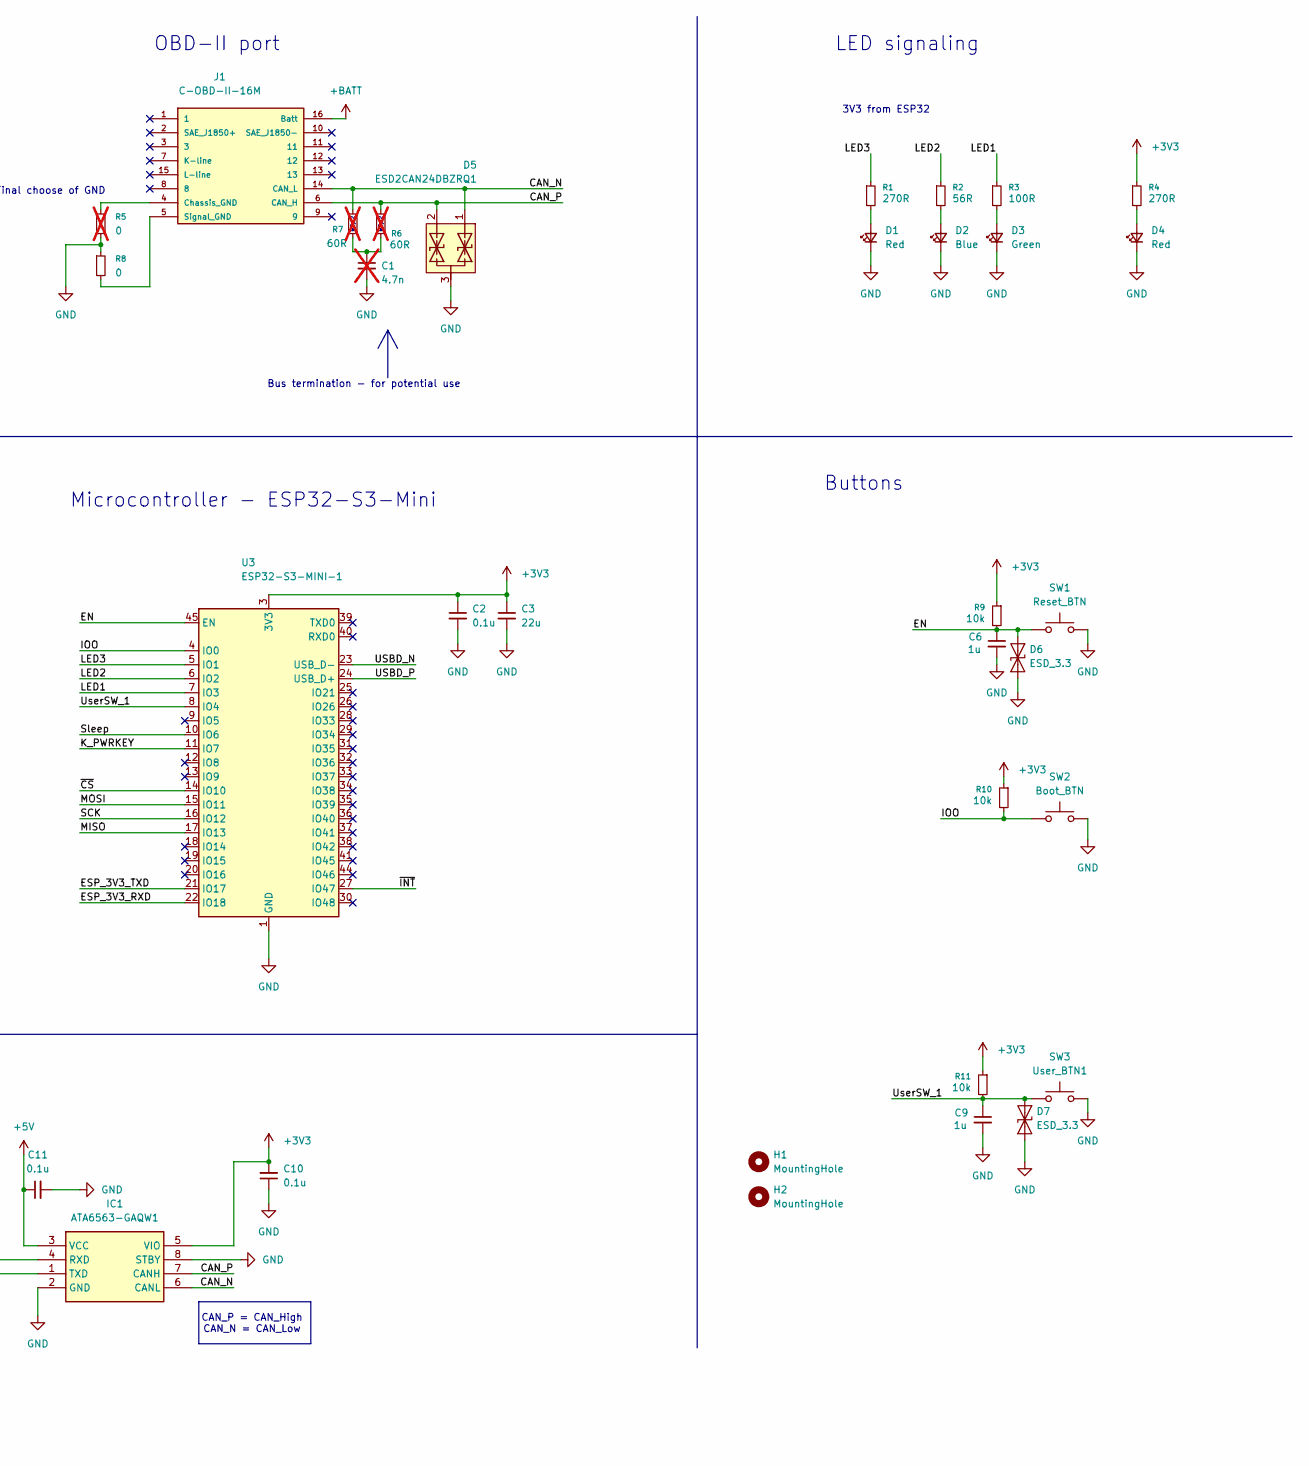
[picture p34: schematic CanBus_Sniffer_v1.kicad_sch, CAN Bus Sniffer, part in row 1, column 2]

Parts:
C1: 4.7n; C_0603_1608Metric; not fitted
C2: 0.1u; C_0603_1608Metric_Pad1.08x0.95mm_HandSolder; Mouser 187-CL31B106KAHNNNE
C3: 22u; C_1206_3216Metric_Pad1.33x1.80mm_HandSolder; Mouser No 963-MSASE31LBB7226MT
C4, C5, C7, C8, C10, C11, C12: 0.1u; C_0603_1608Metric_Pad1.08x0.95mm_HandSolder; Mouser 80-C1206C104J5RAC
C6, C9: 1u; C_0603_1608Metric_Pad1.08x0.95mm_HandSolder; Mouser No 187-CL10A105KO8NNNL
C13, C14: 12p; C_0603_1608Metric_Pad1.08x0.95mm_HandSolder; Mouser 80-C1206C104J5RAC
D1, D4: Red; LED_0603_1608Metric_Pad1.05x0.95mm_HandSolder; Mouser No 710-150060RS75003
D2: Blue; LED_0603_1608Metric_Pad1.05x0.95mm_HandSolder; Mouser No 743-S63BT5B
D3: Green; LED_0603_1608Metric_Pad1.05x0.95mm_HandSolder; Mouser No 78-VLMTG1400-GS08
D5: ESD2CAN24DBZRQ1; TSOT-23; Mouser Part Number 595-ESD2CAN24DBZRQ1
D6, D7: ESD_3.3; D_SOD-323; Mouser No 621-D5V0L1B2WS-7
H1, H2: MountingHole; MountingHole_2.1mm
IC1: ATA6563-GAQW1; SOIC127P600X175-8N; Mouser Part Number 579-ATA6563-GAQW1
J1: C-OBD-II-16M; COMTECH_C-OBD-II-16M; PARTREV A
J2: Conn_01x07_Pin; PinHeader_1x07_P2.54mm_Vertical; Mouser No 737-RS1-07-G
R1, R4: 270R; R_0603_1608Metric_Pad0.98x0.95mm_HandSolder; Mouser 603-RE1206DRE071KL
R2: 56R; R_0603_1608Metric_Pad0.98x0.95mm_HandSolder; Mouser 603-RE1206DRE071KL
R3: 100R; R_0603_1608Metric_Pad0.98x0.95mm_HandSolder; Mouser 603-RE1206DRE071KL
R5: 0; R_1206_3216Metric_Pad1.30x1.75mm_HandSolder; Mouser No 71-RCS12060000Z0EA; not fitted
R6, R7: 60R; R_0603_1608Metric_Pad0.98x0.95mm_HandSolder; not fitted
R8: 0; R_1206_3216Metric_Pad1.30x1.75mm_HandSolder; Mouser No 71-RCS12060000Z0EA
R9, R10, R11: 10k; R_0603_1608Metric_Pad0.98x0.95mm_HandSolder; Mouser 603-AC1206FR-7W10KL
SW1: Reset_BTN; SW_SPST_TL1017; Mouser No 612-TL1017AAAF260QG
SW2: Boot_BTN; SW_SPST_TL1017; Mouser No 612-TL1017AAAF260QG
SW3: User_BTN1; SW_SPST_EVQP2_ShortPushTravel_H2.5mm; Mouser No 667-EVQ-PUJ02K
U1: TLV1117-18; SOT-223-3_TabPin2; Mouser No 595-TLV1117LV18DCYR
U2: TXS0102DCT; SSOP-8_2.95x2.8mm_P0.65mm; Mouser No 595-TXS0102VDCTR
U3: ESP32-S3-MINI-1; ESP32-S2-MINI-1; Mouser No 356-ESP32-S3-MINI1N8
U4: MCP2518FD-xQBB; SOIC127P600X175-14N; Mouser No 579-MCP2518FDT-E/SL
Y1: 40MHz; Crystal_SMD_2016-4Pin_2.0x1.6mm; Mouser No 815-11W40-8D1XT

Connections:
+1V8: C4.1, C8.1, U1.2 (VO), U2.3 (VCCA), U2.6 (OE)
+3V3: C2.1, C3.1, C5.1, C7.1, C10.2, C12.2, IC1.5 (VIO), R4.1, R9.1, R10.1, R11.1, U1.3 (VI), U2.7 (VCCB), U3.3 (3V3), U4.14 (VDD); also elsewhere on the board
+5V: C11.1, IC1.3 (VCC), J2.5; also elsewhere on the board
+BATT: J1.16 (Batt); also elsewhere on the board
/CAN_N: D5.1, IC1.6 (CANL), J1.14 (CAN_L), R6.1
/CAN_P: D5.2, IC1.7 (CANH), J1.6 (CAN_H), R7.1
/EN: C6.1, D6.2 (A2), R9.2, SW1.1, U3.45 (EN)
/ESP_3V3_RXD: U2.1 (B2), U3.22 (IO18)
/ESP_3V3_TXD: U2.8 (B1), U3.21 (IO17)
/IOO: R10.2, SW2.1, U3.4 (IO0)
/K_PWRKEY: J2.4, U3.11 (IO7)
/LED1: R3.1, U3.7 (IO3)
/LED2: R2.1, U3.6 (IO2)
/LED3: R1.1, U3.5 (IO1)
/MISO: U3.17 (IO13), U4.12 (SDO)
/MOSI: U3.15 (IO11), U4.11 (SDI)
/SCK: U3.16 (IO12), U4.10 (SCK)
/SIM_1.8_TXD: J2.3, U2.4 (A2)
/SIM_1V8_RXD: J2.2, U2.5 (A1)
/Sleep: J2.7, U3.10 (IO6)
/USBD_N: U3.23 (USB_D-); also elsewhere on the board
/USBD_P: U3.24 (USB_D+); also elsewhere on the board
/UserSW_1: C9.1, D7.2 (A2), R11.2, SW3.1, U3.8 (IO4)
/~CS: U3.14 (IO10), U4.13 (~CS)
/~INT: U3.27 (IO47), U4.4 (~INT)
GND: C1.2, C2.2, C3.2, C4.2, C5.2, C6.2, C7.2, C8.2, C9.2, C10.1, C11.2, C12.1, C13.1, C14.1, D1.1 (K), D2.1 (K), D3.1 (K), D4.1 (K), D5.3, D6.1 (A1), D7.1 (A1), IC1.2 (GND), IC1.8 (STBY), J2.1, J2.6, R5.2, R8.1, SW1.2, SW2.2, SW3.2, U1.1 (GND), U2.2 (GND), U3.1 (GND), U3.2 (GND), U3.42 (GND), U3.43 (GND), U3.46 (GND), U3.47 (GND), U3.48 (GND), U3.49 (GND), U3.50 (GND), U3.51 (GND), U3.52 (GND), U3.53 (GND), U3.54 (GND), U3.55 (GND), U3.56 (GND), U3.57 (GND), U3.58 (GND), U3.59 (GND), U3.60 (GND), U3.61 (GND), U3.62 (GND), U3.63 (GND), U3.64 (GND), U3.65 (GND), U4.7 (VSS), Y1.2, Y1.4; also elsewhere on the board
unnamed: C1.1, R6.2, R7.2
unnamed: D1.2 (A), R1.2
unnamed: D2.2 (A), R2.2
unnamed: D3.2 (A), R3.2
unnamed: D4.2 (A), R4.2
unnamed: IC1.4 (RXD), U4.2 (RXCAN)
unnamed: IC1.1 (TXD), U4.1 (TXCAN)
unnamed: J1.4 (Chassis_GND), R5.1
unnamed: J1.5 (Signal_GND), R8.2
unnamed: C14.2, U4.6 (OSC1), Y1.3
unnamed: C13.2, U4.5 (OSC2), Y1.1

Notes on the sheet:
RT/2
USBD_P = USB_D+ USBD_N = USB_D-
LTE + GPS module
OBD-II port
Microcontroller - ESP32-S3-Mini
3V3 from ESP32
Final choose of GND
Bus termination - for potential use
Power supply
MCP2518FD Controller - Can FD to SPI
Buttons
LED signaling
CAN_P = CAN_High CAN_N = CAN_Low

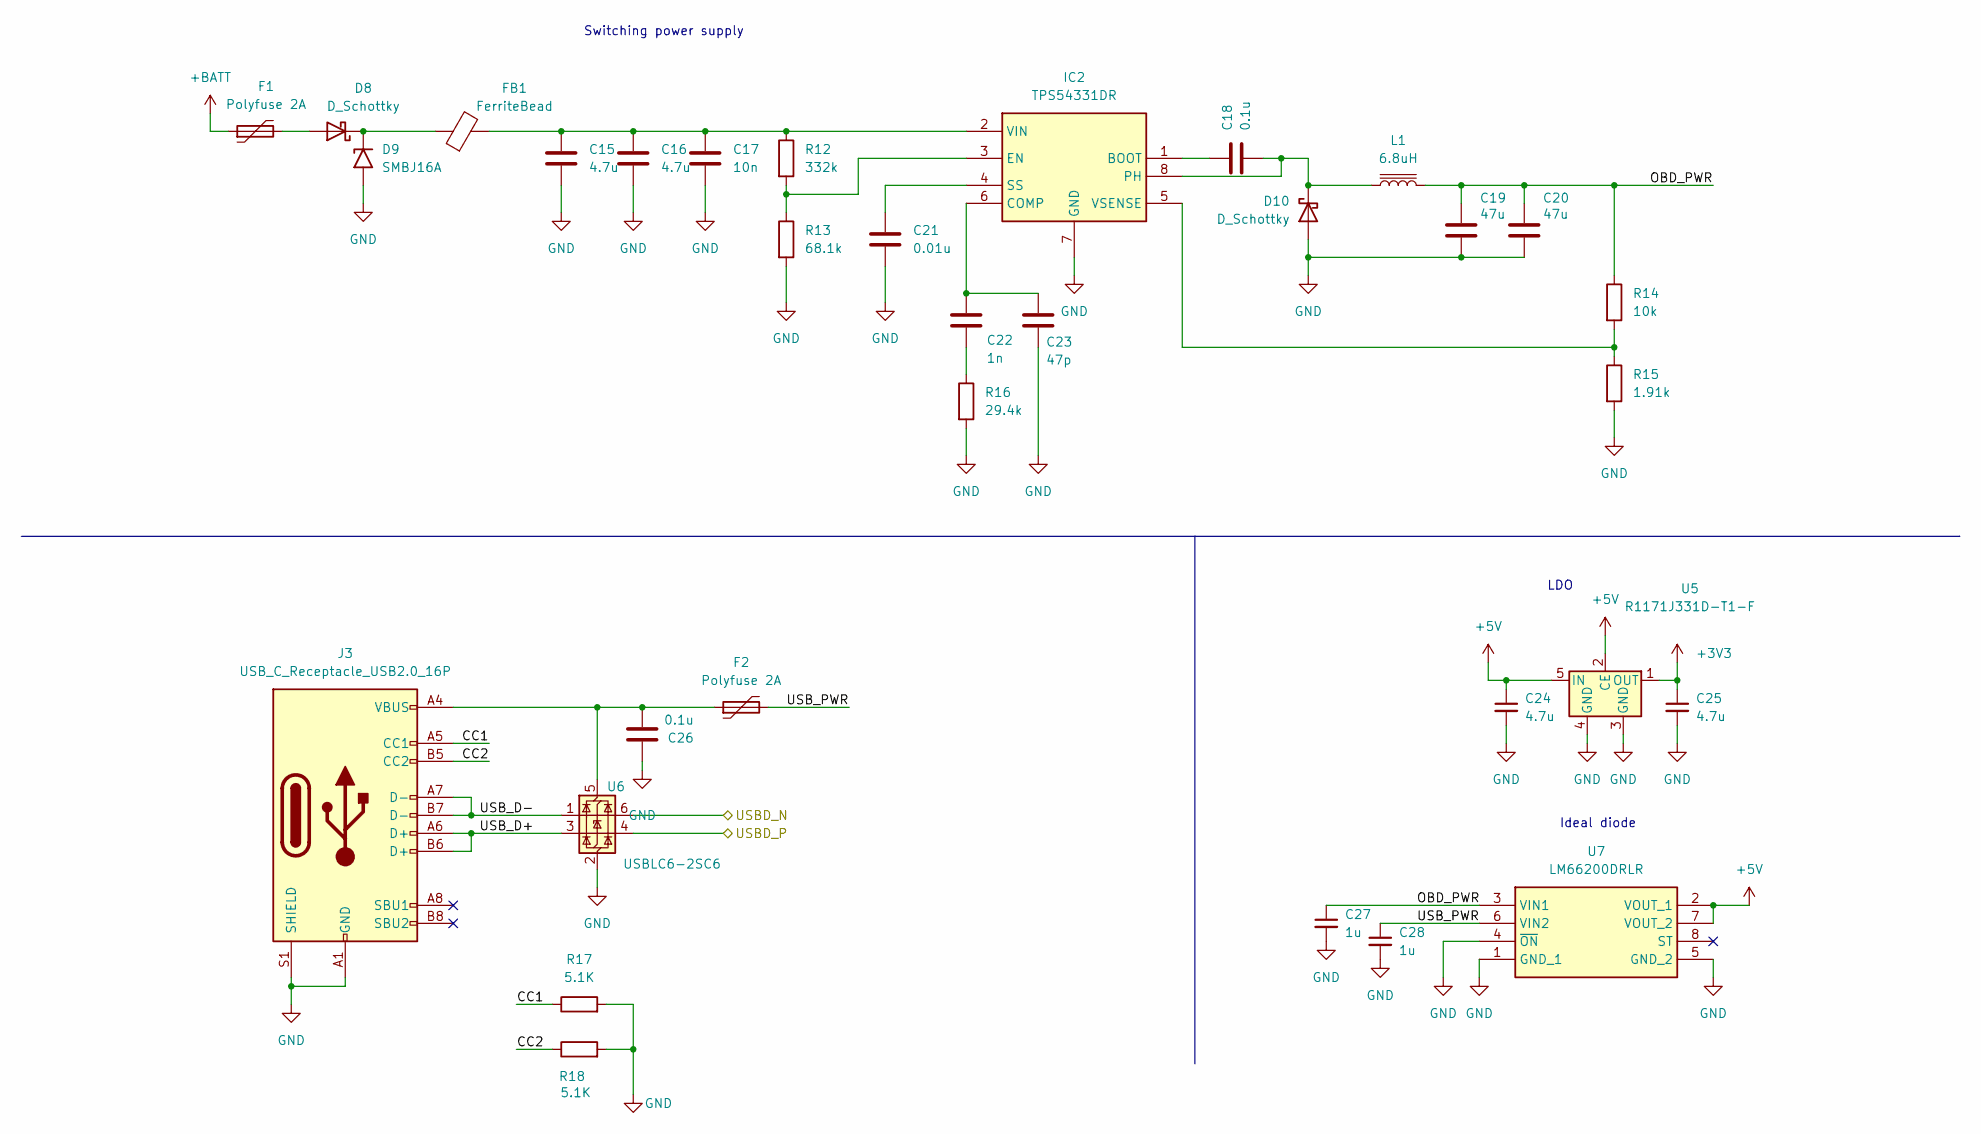
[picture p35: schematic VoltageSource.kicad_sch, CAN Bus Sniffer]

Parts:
C15, C16: 4.7u; R_0805_2012Metric_Pad1.20x1.40mm_HandSolder; Mouser No 810-CGA4J1X7R1H475K1
C17: 10n; C_0603_1608Metric_Pad1.08x0.95mm_HandSolder; Mouser No 810-CGA3E2X7R1H103K
C18: 0.1u; C_0603_1608Metric_Pad1.08x0.95mm_HandSolder; Mouser No 603-CC603KRX7R8BB104
C19, C20: 47u; R_1206_3216Metric_Pad1.30x1.75mm_HandSolder; Mouser No 963-MSASE31LBB5476MT
C21: 0.01u; C_0603_1608Metric_Pad1.08x0.95mm_HandSolder; Mouser No 810-CGA3E2X7R1H103K
C22: 1n; C_0603_1608Metric_Pad1.08x0.95mm_HandSolder; Mouser No 603-AC603KRX7R8BB102
C23: 47p; C_0603_1608Metric_Pad1.08x0.95mm_HandSolder; Mouser No 77-VJ0603A470JXXPBC
C24, C25: 4.7u; C_0603_1608Metric_Pad1.08x0.95mm_HandSolder; Mouser No 81-GRM188Z71C475KE1D
C26: 0.1u; C_0603_1608Metric_Pad1.08x0.95mm_HandSolder; Mouser No 810-C1608X7R1E104M
C27, C28: 1u; C_0603_1608Metric_Pad1.08x0.95mm_HandSolder; Mouser No 791-0603B105K160CT
D8: D_Schottky; D_SMA; Mouser No 750-SS54F-HF
D9: SMBJ16A; D_SMB; Mouser No 576-SMBJ16A
D10: D_Schottky; D_SMA; Mouser No 621-B340AE-13
F1: Polyfuse 2A; Fuse_1812_4532Metric_Pad1.30x3.40mm_HandSolder; Mouser No 603-SMD1812B200TF/30
F2: Polyfuse 2A; R_1210_3225Metric_Pad1.30x2.65mm_HandSolder; Mouser 576-1210L200PR
FB1: FerriteBead; L_0805_2012Metric_Pad1.05x1.20mm_HandSolder; Mouser No 81-BLM21PG121SN1D
IC2: TPS54331DR; SOIC-8-1EP_3.9x4.9mm_P1.27mm_EP2.29x3mm; Mouser Part Number 595-TPS54331DR
J3: USB_C_Receptacle_USB2.0_16P; USB_C_Receptacle_GCT_USB4105-xx-A_16P_TopMnt_Horizontal; Mouser 640-USB4105-GF-A-120
L1: 6.8uH; L_6.3x6.3_H3; Mouser No 810-VLS6045EX-6R8M
R12: 332k; R_0603_1608Metric_Pad0.98x0.95mm_HandSolder; Mouser No 667-ERJ-PA3F3323V
R13: 68.1k; R_0603_1608Metric_Pad0.98x0.95mm_HandSolder; Mouser No 755-ESR03EZPF6812
R14: 10k; R_0603_1608Metric_Pad0.98x0.95mm_HandSolder; Mouser No 71-CRCW060310K0FKEE
R15: 1.91k; R_0603_1608Metric_Pad0.98x0.95mm_HandSolder; Mouser No 71-CRCW0603-1.91K-E3
R16: 29.4k; R_0603_1608Metric_Pad0.98x0.95mm_HandSolder; Mouser No 71-CRCW060329K4FKEAH
R17, R18: 5.1K; R_0603_1608Metric_Pad0.98x0.95mm_HandSolder; Mouser 71-CRCW1206-5.1K-E3
U5: R1171J331D-T1-F; TO-252-5_TabPin3; Mouser No 848-R1171J331DT1F
U6: USBLC6-2SC6; SOT-23-6; Mouser 511-USBLC6-2SC6
U7: LM66200DRLR; SOTFL50P160X60-8N; Mouser Part Number 595-LM66200DRLR

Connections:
+3V3: C25.1, U5.1 (OUT); also elsewhere on the board
+5V: C24.1, U5.2 (CE), U5.5 (IN), U7.2 (VOUT_1), U7.7 (VOUT_2); also elsewhere on the board
+BATT: F1.1; also elsewhere on the board
/Power Supply/CC1: J3.A5 (CC1), R17.1
/Power Supply/CC2: J3.B5 (CC2), R18.1
/Power Supply/OBD_PWR: C19.1, C20.1, C27.1, L1.2, R14.1, U7.3 (VIN1)
/Power Supply/USB_D+: J3.A6 (D+), J3.B6 (D+), U6.3 (I/O2)
/Power Supply/USB_D-: J3.A7 (D-), J3.B7 (D-), U6.1 (I/O1)
/Power Supply/USB_PWR: C28.1, F2.2, U7.6 (VIN2)
/USBD_N: U6.6 (I/O1); also elsewhere on the board
/USBD_P: U6.4 (I/O2); also elsewhere on the board
GND: C15.2, C16.2, C17.2, C19.2, C20.2, C21.2, C23.2, C24.2, C25.2, C26.2, C27.2, C28.2, D9.2 (A2), D10.2 (A), IC2.7 (GND), IC2.9 (GND), J3.A1 (GND), J3.A12 (GND), J3.B1 (GND), J3.B12 (GND), J3.S1 (SHIELD), R13.2, R15.2, R16.2, R17.2, R18.2, U5.3 (GND), U5.4 (GND), U6.2 (GND), U7.1 (GND_1), U7.4 (~ON), U7.5 (GND_2); also elsewhere on the board
unnamed: C22.2, R16.1
unnamed: D8.2 (A), F1.2
unnamed: D8.1 (K), D9.1 (A1), FB1.1
unnamed: C18.1, D10.1 (K), IC2.8 (PH), L1.1
unnamed: C18.2, IC2.1 (BOOT)
unnamed: C22.1, C23.1, IC2.6 (COMP)
unnamed: IC2.3 (EN), R12.2, R13.1
unnamed: C21.1, IC2.4 (SS)
unnamed: C15.1, C16.1, C17.1, FB1.2, IC2.2 (VIN), R12.1
unnamed: IC2.5 (VSENSE), R14.2, R15.1
unnamed: C26.1, F2.1, J3.A4 (VBUS), J3.A9 (VBUS), J3.B4 (VBUS), J3.B9 (VBUS), U6.5 (VBUS)

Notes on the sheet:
Ideal diode
Switching power supply
LDO

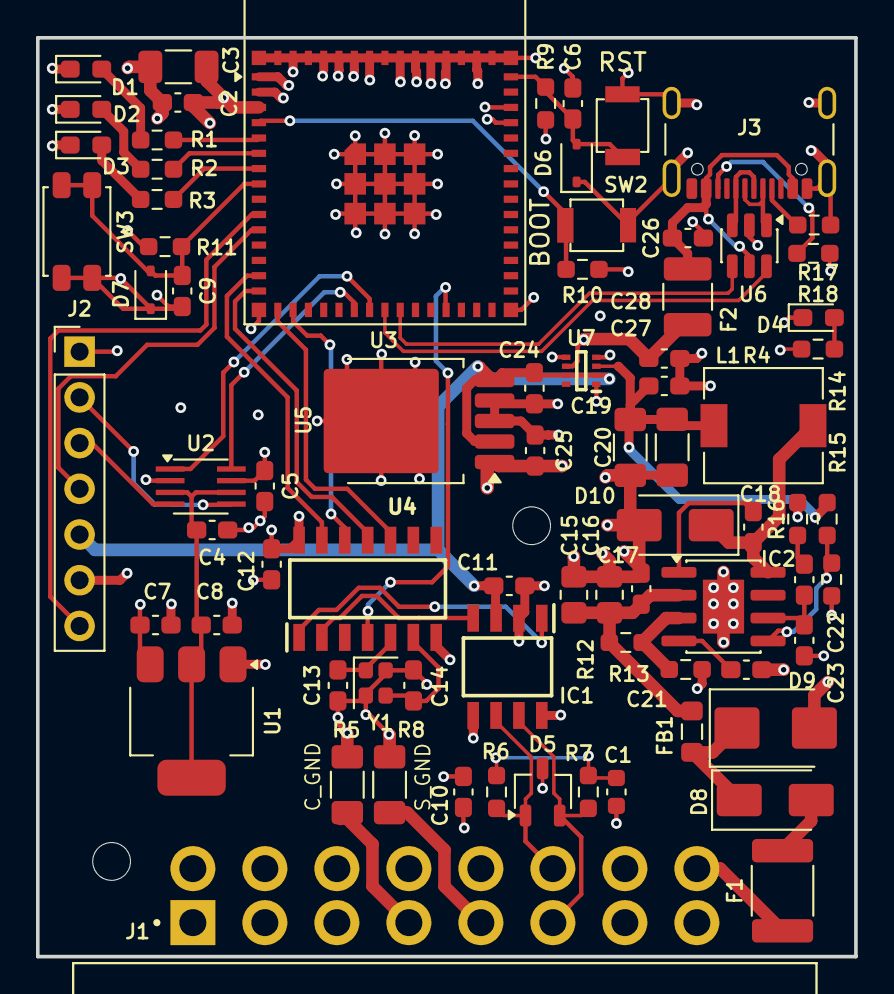
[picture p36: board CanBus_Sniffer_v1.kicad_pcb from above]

Board: 4 copper layers, 45.5 x 51.0 mm, 78 parts (0 on the bottom side), 54 nets.

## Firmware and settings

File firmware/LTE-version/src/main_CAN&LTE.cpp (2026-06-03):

// LTE Version
// =============================================================================

#include <Arduino.h>
#include <ACAN2517FD.h>
#include <SPI.h>
#include <Preferences.h>
#include <esp_sleep.h>

// ==================== SPI (MCP2518FD) ========================================
static const byte MCP2518FD_CS  = 10;
static const byte MCP2518FD_INT = 47;
static const byte SPI_SCK       = 12;
static const byte SPI_MISO      = 13;
static const byte SPI_MOSI      = 11;

// ==================== LED ====================================================
static const byte LED_LTE     = 1;   // LTE/server stav RED
static const byte LED_GPS     = 2;   // GPS hledani / fix BLUE
static const byte LED_CAN     = 3;   // CAN RX activity GREEN

// ==================== A7670E PINS ============================================
#define SIM_RX        18
#define SIM_TX        17
#define SIM_PWRKEY     7
#define SerialAT      Serial1

// ==================== KONFIGURACE SERVERU ====================================
#define API_TOKEN     "SECRET_API_TOKEN"
#define SERVER_URL    "canbussnifferv1-production.up.railway.app"
#define SERVER_PATH   "/data"
#define APN_NAME      "internet"

// ==================== TIMING =================================================
#define OBD_FAST_MS            50   // rpm, speed, throttle, engineLoad: 
#define OBD_SLOW_MS           50   // ostatni PIDy: 
#define LTE_SEND_INTERVAL_MS  2000   // POST kazde 2s
#define GPS_RETRY_INTERVAL_MS 30000
#define CAN_QUIET_TO_IDLE_MS  60000
#define IDLE_TO_SLEEP_MS     300000
#define SLEEP_WAKE_INTERVAL_US (60ULL * 1000000ULL)
#define TRIP_GAP_MS          (60UL * 60 * 1000)

// LED timing
#define LED_LTE_BLINK_MS        80   // delka blinku po uspesnem POST
#define LED_CAN_BLINK_MS        30   // delka blinku po CAN frame
#define LED_GPS_PULSE_MS       100   // delka jednoho pulzu pri hledani fixu
#define LED_GPS_PULSE_GAP_MS   150   // mezera mezi pulzy
#define LED_GPS_CYCLE_GAP_MS  1500   // pauza mezi 3-pulz cykly

// ==================== CAN ====================================================
ACAN2517FD can(MCP2518FD_CS, SPI, MCP2518FD_INT);
void IRAM_ATTR canISR() { can.isr(); }

// ==================== PID DEFINICE ===========================================
enum Category { CAT_CORE, CAT_ENGINE, CAT_FUEL, CAT_EMISSION, CAT_ELECTRIC, CAT_OTHER };

struct OBDPid {
    uint8_t     pid;
    const char* key;
    const char* name;
    const char* unit;
    Category    category;
    bool        fast;        // true = rychla skupina (100ms)
    bool        supported;
    bool        hasValue;
    float       lastValue;
    unsigned long lastRead;
    uint8_t     rawA;
    uint8_t     rawB;
    uint8_t     rawEcuId;
};

OBDPid pidList[] = {
    // ===== RYCHLE (fast=true): rpm, speed, throttle, engineLoad =====
    {0x0C, "rpm",             "RPM",                "rpm",   CAT_CORE,     true,  false, false, 0, 0, 0, 0, 0},
    {0x0D, "speed",           "Speed",              "km/h",  CAT_CORE,     true,  false, false, 0, 0, 0, 0, 0},
    {0x11, "throttle",        "Throttle Pos",       "%",     CAT_CORE,     true,  false, false, 0, 0, 0, 0, 0},
    {0x04, "engineLoad",      "Engine Load",        "%",     CAT_ENGINE,   true,  false, false, 0, 0, 0, 0, 0},

    // ===== POMALE (fast=false) =====
    {0x05, "coolantTemp",     "Coolant Temp",       "C",     CAT_CORE,     false, false, false, 0, 0, 0, 0, 0},
    {0x1F, "engineRuntime",   "Engine Runtime",     "s",     CAT_CORE,     false, false, false, 0, 0, 0, 0, 0},
    {0x06, "stft",            "Short Fuel Trim 1",  "%",     CAT_ENGINE,   false, false, false, 0, 0, 0, 0, 0},
    {0x07, "ltft",            "Long Fuel Trim 1",   "%",     CAT_ENGINE,   false, false, false, 0, 0, 0, 0, 0},
    {0x0B, "mapPressure",     "Intake Manifold Pr", "kPa",   CAT_ENGINE,   false, false, false, 0, 0, 0, 0, 0},
    {0x0E, "ignitionTiming",  "Timing Advance",     "deg",   CAT_ENGINE,   false, false, false, 0, 0, 0, 0, 0},
    {0x0F, "intakeAirTemp",   "Intake Air Temp",    "C",     CAT_ENGINE,   false, false, false, 0, 0, 0, 0, 0},
    {0x10, "maf",             "MAF Rate",           "g/s",   CAT_ENGINE,   false, false, false, 0, 0, 0, 0, 0},
    {0x14, "o2Voltage",       "O2 Sensor 1 V",      "V",     CAT_ENGINE,   false, false, false, 0, 0, 0, 0, 0},
    {0x33, "barometric",      "Barometric Pressure","kPa",   CAT_ENGINE,   false, false, false, 0, 0, 0, 0, 0},
    {0x42, "systemVoltage",   "Control Module V",   "V",     CAT_ENGINE,   false, false, false, 0, 0, 0, 0, 0},
    {0x43, "absoluteLoad",    "Absolute Load",      "%",     CAT_ENGINE,   false, false, false, 0, 0, 0, 0, 0},
    {0x46, "outdoorTemp",     "Ambient Air Temp",   "C",     CAT_ENGINE,   false, false, false, 0, 0, 0, 0, 0},
    {0x5C, "oilTemp",         "Engine Oil Temp",    "C",     CAT_ENGINE,   false, false, false, 0, 0, 0, 0, 0},
    {0x0A, "fuelPressure",    "Fuel Pressure",      "kPa",   CAT_FUEL,     false, false, false, 0, 0, 0, 0, 0},
    {0x2F, "fuelLevel",       "Fuel Level",         "%",     CAT_FUEL,     false, false, false, 0, 0, 0, 0, 0},
    {0x5E, "fuelConsumption", "Engine Fuel Rate",   "L/h",   CAT_FUEL,     false, false, false, 0, 0, 0, 0, 0},
    {0x59, "fuelRailPress",   "Fuel Rail Pressure", "kPa",   CAT_FUEL,     false, false, false, 0, 0, 0, 0, 0},
    {0x01, "monitorStatus",   "Monitor Status",     "",      CAT_EMISSION, false, false, false, 0, 0, 0, 0, 0},
    {0x03, "fuelSysStatus",   "Fuel System Status", "",      CAT_EMISSION, false, false, false, 0, 0, 0, 0, 0},
    {0x13, "o2Sensors",       "O2 Sensors Present", "",      CAT_EMISSION, false, false, false, 0, 0, 0, 0, 0},
    {0x1C, "obdStandard",     "OBD Standard",       "",      CAT_EMISSION, false, false, false, 0, 0, 0, 0, 0},
    {0x21, "milDistance",     "Distance w/ MIL",    "km",    CAT_EMISSION, false, false, false, 0, 0, 0, 0, 0},
    {0x30, "warmupsCLR",      "Warmups since CLR",  "",      CAT_EMISSION, false, false, false, 0, 0, 0, 0, 0},
    {0x31, "distanceCLR",     "Distance since CLR", "km",    CAT_EMISSION, false, false, false, 0, 0, 0, 0, 0},
    {0x3C, "catalystTemp",    "Catalyst Temp B1S1", "C",     CAT_EMISSION, false, false, false, 0, 0, 0, 0, 0},
    {0x5B, "hvBatterySOC",    "HV Battery SOC",     "%",     CAT_ELECTRIC, false, false, false, 0, 0, 0, 0, 0},
    {0x9C, "hvBatteryTemp",   "HV Battery Temp",    "C",     CAT_ELECTRIC, false, false, false, 0, 0, 0, 0, 0},
    {0x9D, "hvBatteryVolt",   "HV Battery Voltage", "V",     CAT_ELECTRIC, false, false, false, 0, 0, 0, 0, 0},
    {0x9E, "hvBatteryCurr",   "HV Battery Current", "A",     CAT_ELECTRIC, false, false, false, 0, 0, 0, 0, 0},
    {0x8E, "evMode",          "EV Mode",            "",      CAT_ELECTRIC, false, false, false, 0, 0, 0, 0, 0},
    {0x02, "freezeDTC",       "Freeze DTC",         "",      CAT_OTHER,    false, false, false, 0, 0, 0, 0, 0},
    {0x12, "secAirStatus",    "Sec Air Status",     "",      CAT_OTHER,    false, false, false, 0, 0, 0, 0, 0},
    {0x1D, "o2SensorsAlt",    "O2 Sensors (alt)",   "",      CAT_OTHER,    false, false, false, 0, 0, 0, 0, 0},
    {0x1E, "auxStatus",       "Aux Input Status",   "",      CAT_OTHER,    false, false, false, 0, 0, 0, 0, 0},
    {0x22, "fuelRailPressVac","Fuel Rail Pr vs Vac","kPa",   CAT_OTHER,    false, false, false, 0, 0, 0, 0, 0},
    {0x23, "fuelRailPressDir","Fuel Rail Pr direct","kPa",   CAT_OTHER,    false, false, false, 0, 0, 0, 0, 0},
    {0x2C, "egrCmd",          "EGR commanded",      "%",     CAT_OTHER,    false, false, false, 0, 0, 0, 0, 0},
    {0x2D, "egrError",        "EGR error",          "%",     CAT_OTHER,    false, false, false, 0, 0, 0, 0, 0},
    {0x2E, "evapPurgeCmd",    "Evap Purge",         "%",     CAT_OTHER,    false, false, false, 0, 0, 0, 0, 0},
    {0x32, "evapVaporPress",  "Evap Vapor Pr",      "Pa",    CAT_OTHER,    false, false, false, 0, 0, 0, 0, 0},
    {0x44, "afEqRatio",       "Air-Fuel Eq Ratio",  "",      CAT_OTHER,    false, false, false, 0, 0, 0, 0, 0},
    {0x45, "relThrottle",     "Relative Throttle",  "%",     CAT_OTHER,    false, false, false, 0, 0, 0, 0, 0},
    {0x47, "absThrottleB",    "Abs Throttle Pos B", "%",     CAT_OTHER,    false, false, false, 0, 0, 0, 0, 0},
    {0x49, "accPedalD",       "Accel Pedal D",      "%",     CAT_OTHER,    false, false, false, 0, 0, 0, 0, 0},
    {0x4A, "accPedalE",       "Accel Pedal E",      "%",     CAT_OTHER,    false, false, false, 0, 0, 0, 0, 0},
    {0x4C, "throttleActuator","Throttle Actuator",  "%",     CAT_OTHER,    false, false, false, 0, 0, 0, 0, 0},
    {0x4D, "milTime",         "Time w/ MIL on",     "min",   CAT_OTHER,    false, false, false, 0, 0, 0, 0, 0},
    {0x4E, "timeSinceCLR",    "Time since CLR",     "min",   CAT_OTHER,    false, false, false, 0, 0, 0, 0, 0},
    {0x51, "fuelType",        "Fuel Type",          "",      CAT_OTHER,    false, false, false, 0, 0, 0, 0, 0},
    {0x52, "ethanolPct",      "Ethanol %",          "%",     CAT_OTHER,    false, false, false, 0, 0, 0, 0, 0},
    {0x53, "evapAbsPress",    "Evap Abs Pr",        "kPa",   CAT_OTHER,    false, false, false, 0, 0, 0, 0, 0},
    {0x5A, "relAccelPedal",   "Rel Accel Pedal",    "%",     CAT_OTHER,    false, false, false, 0, 0, 0, 0, 0},
    {0x5D, "fuelInjTiming",   "Fuel Inj Timing",    "deg",   CAT_OTHER,    false, false, false, 0, 0, 0, 0, 0},
    {0x61, "demandedTorque",  "Demanded Torque",    "%",     CAT_OTHER,    false, false, false, 0, 0, 0, 0, 0},
    {0x62, "actualTorque",    "Actual Torque",      "%",     CAT_OTHER,    false, false, false, 0, 0, 0, 0, 0},
    {0x63, "refTorque",       "Reference Torque",   "Nm",    CAT_OTHER,    false, false, false, 0, 0, 0, 0, 0},
    {0x67, "engineCoolantT",  "Engine Coolant Temp","C",     CAT_OTHER,    false, false, false, 0, 0, 0, 0, 0},
    {0x68, "intakeAirTempS",  "Intake Air Temp Sen","C",     CAT_OTHER,    false, false, false, 0, 0, 0, 0, 0},
    {0x6B, "egrTemp",         "EGR Temp",           "C",     CAT_OTHER,    false, false, false, 0, 0, 0, 0, 0},
    {0x70, "boostPressure",   "Boost Pressure",     "kPa",   CAT_OTHER,    false, false, false, 0, 0, 0, 0, 0},
    {0x71, "chargeAirTemp",   "Charge Air Temp",    "C",     CAT_OTHER,    false, false, false, 0, 0, 0, 0, 0},
    {0x73, "exhaustPressure", "Exhaust Pressure",   "kPa",   CAT_OTHER,    false, false, false, 0, 0, 0, 0, 0},
    {0x78, "egtBank1",        "EGT Bank 1",         "C",     CAT_OTHER,    false, false, false, 0, 0, 0, 0, 0},
    {0x7C, "dpfTemp",         "DPF Temp",           "C",     CAT_OTHER,    false, false, false, 0, 0, 0, 0, 0},
    {0x83, "noxSensor",       "NOx Sensor",         "ppm",   CAT_OTHER,    false, false, false, 0, 0, 0, 0, 0},
    {0x9A, "hybridBattLife",  "Hybrid Batt Life",   "%",     CAT_OTHER,    false, false, false, 0, 0, 0, 0, 0},
};

const uint8_t pidCount = sizeof(pidList) / sizeof(pidList[0]);

// ==================== STAVOVE PROMENNE =======================================
bool          scanning           = false;
bool          looping            = false;
unsigned long lastFastRequest    = 0;
unsigned long lastSlowRequest    = 0;
uint8_t       fastIndex          = 0;
uint8_t       slowIndex          = 0;
unsigned long lastLteSend        = 0;
uint8_t       sendCycle          = 0;
unsigned long lastCanFrameMs     = 0;
unsigned long canQuietSinceMs    = 0;
unsigned long lastGpsAttempt     = 0;

bool          lteReady           = false;
bool          gpsEnabled         = false;
bool          gpsHasFix          = false;
double        gpsLat             = 0.0;
double        gpsLon             = 0.0;
uint8_t       httpFailCount      = 0;
unsigned long lastTripActivityMs = 0;
String        nextTripEvent      = "";

// LED non-blocking state
unsigned long ledCanOffMs        = 0;
unsigned long ledLteBlinkOffMs   = 0;
bool          ledLteBlinkActive  = false;
unsigned long ledGpsNextEdgeMs   = 0;
uint8_t       ledGpsPhase        = 0;   // 0..5 = 3 pulzy (on/off/on/off/on/off), 6 = pauza

enum Phase { PHASE_BOOT, PHASE_DRIVING, PHASE_IDLE_AWAKE, PHASE_LIGHT_SLEEP };
Phase phase = PHASE_BOOT;
unsigned long phaseEnteredMs = 0;

Preferences prefs;
RTC_DATA_ATTR uint64_t bootCount = 0;

// =============================================================================
//  FORWARD DECLARATIONS
// =============================================================================

void processOBDResponse(CANFDMessage &frame);
void servCAN();              // <-- non-blocking CAN service, vola se vsude

// =============================================================================
//  CAN SERVICE — vola se behem cekani na AT odpovedi
// =============================================================================

void servCAN() {
    CANFDMessage rx;
    while (can.receive(rx)) {     // while, ne if — vyber vsechny pending framy
        processOBDResponse(rx);
        lastCanFrameMs = millis();
        digitalWrite(LED_CAN, HIGH);
        ledCanOffMs = lastCanFrameMs + LED_CAN_BLINK_MS;
    }
}

// =============================================================================
//  AT HELPERY — neblokuji CAN
// =============================================================================

String sendAT(const String &cmd, uint32_t timeout = 1500, bool log = true) {
    while (SerialAT.available()) SerialAT.read();
    SerialAT.print(cmd); SerialAT.print('\r');
    String resp = "";
    resp.reserve(128);
    unsigned long t = millis();
    while (millis() - t < timeout) {
        if (SerialAT.available()) {
            resp += (char)SerialAT.read();
            // brzo skoncit jakmile mame OK / ERROR
            if (resp.endsWith("OK\r\n") ||
                resp.endsWith("ERROR\r\n") ||
                resp.indexOf("+CME ERROR") >= 0 ||
                resp.indexOf("+CMS ERROR") >= 0) break;
        } else {
            servCAN();              // UART prazdny, cekani na odpoved modemu
                                    // serv.CAN - zatim scanuje CAN
        }
    }
    if (log) {
        Serial.print("[AT] "); Serial.print(cmd); Serial.print(" -> ");
        String r = resp; r.replace("\r", " "); r.replace("\n", " ");
        if (r.length() > 80) r = r.substring(0, 80) + "...";
        Serial.println(r);
    }
    return resp;
}

bool waitFor(const String &substr, uint32_t timeout = 5000) {
    String buf = "";
    buf.reserve(256);
    unsigned long t = millis();
    while (millis() - t < timeout) {
        if (SerialAT.available()) {
            buf += (char)SerialAT.read();
            if (buf.indexOf(substr) >= 0) return true;
        } else {
            servCAN();
        }
    }
    return false;
}

// =============================================================================
//  MODEM POWER
// =============================================================================

void modemPowerPulse() {
    digitalWrite(SIM_PWRKEY, HIGH);
    delay(1500);
    digitalWrite(SIM_PWRKEY, LOW);
    delay(3000);
}

void modemHardReset() {
    Serial.println("[LTE] HARD RESET...");
    digitalWrite(LED_LTE, LOW);
    modemPowerPulse();
    delay(2000);
    modemPowerPulse();
}

// =============================================================================
//  LTE INIT
// =============================================================================

bool initLTE() {
    Serial.println("[LTE] Power ON...");
    modemPowerPulse();
    delay(5000);

    bool alive = false;
    for (uint8_t i = 0; i < 15; i++) {
        String r = sendAT("AT", 1000, false);
        if (r.indexOf("OK") >= 0) { alive = true; break; }
        delay(500);
    }
    if (!alive) { Serial.println("[LTE] Modul nereaguje"); return false; }

    sendAT("ATE0");
    sendAT("AT+CMEE=2");

    Serial.println("[LTE] Cekam na registraci...");
    bool registered = false;
    for (uint8_t i = 0; i < 30; i++) {
        String r = sendAT("AT+CREG?", 1500, false);
        if (r.indexOf(",1") >= 0 || r.indexOf(",5") >= 0) { registered = true; break; }
        delay(1500);
    }
    if (!registered) { Serial.println("[LTE] Registrace selhala"); return false; }

    sendAT("AT+CGDCONT=1,\"IP\",\"" APN_NAME "\"");
    sendAT("AT+CGACT=1,1", 5000);
    sendAT("AT+CSQ");
    sendAT("AT+CSSLCFG=\"sslversion\",0,3");
    sendAT("AT+CSSLCFG=\"authmode\",0,0");
    sendAT("AT+CSSLCFG=\"enableSNI\",0,1");
    sendAT("AT+CSSLCFG=\"ignorelocaltime\",0,1");
    Serial.println("[LTE] OK");
    digitalWrite(LED_LTE, HIGH);   // svit trvale = pripojeno
    return true;
}

// =============================================================================
//  GPS
// =============================================================================

void initGPS() {
    sendAT("AT+CGNSSPWR=1", 3000);
    delay(1500);
    Serial.println("[GPS] Zapnuto, cekam na fix...");
}

void parseGNSSInfo(const String &resp) {
    int idx = resp.indexOf("+CGNSSINFO:");
    if (idx < 0) return;
    String s = resp.substring(idx + 11);
    s.trim();
    if (s.length() < 5) { gpsHasFix = false; return; }

    String parts[16];
    int n = 0, last = 0;
    for (int i = 0; i <= (int)s.length() && n < 16; i++) {
        if (i == (int)s.length() || s.charAt(i) == ',') {
            parts[n++] = s.substring(last, i);
            last = i + 1;
        }
    }
    if (n < 5) { gpsHasFix = false; return; }

    String latStr = parts[1];
    String latNS  = parts[2];
    String lonStr = parts[3];
    String lonEW  = parts[4];

    if (latStr.length() < 4 || lonStr.length() < 4) { gpsHasFix = false; return; }

    gpsLat = latStr.toDouble();
    gpsLon = lonStr.toDouble();
    if (latNS == "S") gpsLat = -gpsLat;
    if (lonEW == "W") gpsLon = -gpsLon;
    gpsHasFix = true;
}

void tryGpsFix() {
    if (!gpsEnabled) return;
    if (millis() - lastGpsAttempt < GPS_RETRY_INTERVAL_MS && lastGpsAttempt != 0) return;
    lastGpsAttempt = millis();
    String r = sendAT("AT+CGNSSINFO", 2000, false);
    bool wasFixed = gpsHasFix;
    parseGNSSInfo(r);
    if (gpsHasFix && !wasFixed) {
        Serial.print("[GPS] FIX lat="); Serial.print(gpsLat, 6);
        Serial.print(" lon="); Serial.println(gpsLon, 6);
    } else if (!gpsHasFix) {
        Serial.println("[GPS] bez fixu");
    }
}

// =============================================================================
//  OBD-II
// =============================================================================

void sendOBDRequest(uint8_t pid) {
    CANFDMessage frame;
    frame.id  = 0x7DF;
    frame.len = 8;
    frame.data[0] = 0x02;
    frame.data[1] = 0x01;
    frame.data[2] = pid;
    memset(&frame.data[3], 0, 5);
    can.tryToSend(frame);
}
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
void loop() {
    unsigned long now = millis();

    // ---- CAN RX (servCAN servuje vsechny pending framy + LED) ----
    servCAN();

    // Auto-SCAN pokud prijde frame ale zadne PIDy supported
    if (lastCanFrameMs == now && !scanning && !looping) {
        uint8_t cnt = 0;
        for (uint8_t i = 0; i < pidCount; i++) if (pidList[i].supported) cnt++;
        if (cnt == 0) {
            Serial.println("[OBD] Auto-SCAN...");
            scanning = true;
            sendOBDRequest(0x00);
        }
    }

    // ---- RYCHLE PIDy (rpm, speed, throttle, engineLoad) — kazdych 50 sms ----
    if (looping && now - lastFastRequest >= OBD_FAST_MS) {
        lastFastRequest = now;
        int8_t idx = nextPid(fastIndex, true);
        if (idx >= 0) sendOBDRequest(pidList[idx].pid);
    }

    // ---- POMALE PIDy — 50 ms ----
    if (looping && now - lastSlowRequest >= OBD_SLOW_MS) {
        lastSlowRequest = now;
        int8_t idx = nextPid(slowIndex, false);
        if (idx >= 0) sendOBDRequest(pidList[idx].pid);
    }

    // ---- GPS retry ----
    if (lteReady) tryGpsFix();

    // ---- LTE send: kazdych 2s fast JSON, kazdych ~6s full JSON ----
    if (lteReady && phase != PHASE_IDLE_AWAKE && now - lastLteSend >= LTE_SEND_INTERVAL_MS) {
        lastLteSend = now;
        sendCycle++;
        if (sendCycle >= 3) {
            sendCycle = 0;
            sendToServer(buildFullJSON());
        } else {
            sendToServer(buildFastJSON());
        }
    }

    // ---- LTE reconnect pokud nikdy nepripojeno (napr. v aute zapneme drive nez prijde signal) ----
    static unsigned long lastLteRetry = 0;
    if (!lteReady && now - lastLteRetry > 60000) {
        lastLteRetry = now;
        Serial.println("[LTE] Pokus o opetovne pripojeni...");
        lteReady = initLTE();
        if (lteReady && !gpsEnabled) { initGPS(); gpsEnabled = true; }
    }

    // ---- FSM (sleep mgmt) ----
    updatePhase();

    // ---- LED update (non-blocking) ----
    updateLEDs();
}

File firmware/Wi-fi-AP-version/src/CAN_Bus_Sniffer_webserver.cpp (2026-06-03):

//project/
//├── src/
//│   └── CAN_Bus_Sniffer_webserver.cpp    
//├── data/                 
//│   ├── dashboard.html
//│   ├── alarms.html
//│   ├── consumption.html
//│   ├── graphs.html
//│   ├── vehicle-data.html
//│   ├── diagnostic.html
//│   ├── login.html
//│   ├── style.css
//│   └── data.js
//│   └── chart.min.js
//│   └── chartsjs-plugin-zoom.js
//│   └── hammer.min.js
//└── platformio.ini

// ═══════════════════════════════════════════════════════════════════════
//  OBD-II Dashboard Server
//  ESP32-S3 + MCP2518FD  |  CAN 2.0 @ 500 kbit/s
//  WPA2 WiFi AP + DNS Captive Portal + /api/data JSON endpoint
// ═══════════════════════════════════════════════════════════════════════



#include <Arduino.h>
#include <ACAN2517FD.h>
#include <SPI.h>
#include <WiFi.h>
#include <WebServer.h>
#include <DNSServer.h>
#include <LittleFS.h>

// ── SPI piny ─────────────────────────────────────────────────────────
static const byte MCP2518FD_CS  = 10;
static const byte MCP2518FD_INT = 47;
static const byte SPI_SCK       = 12;
static const byte SPI_MISO      = 13;
static const byte SPI_MOSI      = 11;

// ── LED a tlačítko ───────────────────────────────────────────────────
static const byte LED_STATUS1 = 1;  // svítí po WiFi AP init
static const byte LED_STATUS2 = 2;  // svítí po scan dokončení (LOOP aktivní)
static const byte LED_CAN     = 3;  // bliká při každém CAN frame
static const byte BUTTON_PIN  = 4;

// ── WiFi ─────────────────────────────────────────────────────────────
#define WIFI_SSID     "CANBus_Sniffer_v1"
#define WIFI_PASS     "obd321aa"

static const byte DNS_PORT = 53;
DNSServer  dnsServer;
WebServer  server(80);

ACAN2517FD can(MCP2518FD_CS, SPI, MCP2518FD_INT);
void IRAM_ATTR canISR() { can.isr(); }

// ═══════════════════════════════════════════════════════════════════════
//  PID TABULKA
struct OBDPid {
    uint8_t     pid;
    const char* jsonKey;
    bool        supported;
    bool        hasValue;  
    float       lastValue;
    uint8_t     rawA;
    uint8_t     rawB;
};

OBDPid pidList[] = {
    // ── CORE ────────────────────────────────────────────────────────
    {0x0D, "speed",           false, false, 0, 0, 0},
    {0x0C, "rpm",             false, false, 0, 0, 0},
    {0x05, "coolantTemp",     false, false, 0, 0, 0},
    {0x11, "throttle",        false, false, 0, 0, 0},
    {0x1F, "engineRuntime",   false, false, 0, 0, 0},
    // ── ENGINE ──────────────────────────────────────────────────────
    {0x04, "engineLoad",      false, false, 0, 0, 0},
    {0x06, "stft",            false, false, 0, 0, 0},
    {0x07, "ltft",            false, false, 0, 0, 0},
    {0x0B, "mapPressure",     false, false, 0, 0, 0},
    {0x0E, "ignitionTiming",  false, false, 0, 0, 0},
    {0x0F, "intakeAirTemp",   false, false, 0, 0, 0},
    {0x10, "maf",             false, false, 0, 0, 0},
    {0x46, "outdoorTemp",     false, false, 0, 0, 0},
    {0x5C, "oilTemp",         false, false, 0, 0, 0},
    {0x43, "absoluteLoad",    false, false, 0, 0, 0},
    // ── FUEL ────────────────────────────────────────────────────────
    {0x2F, "fuelLevel",       false, false, 0, 0, 0},
    {0x5E, "fuelConsumption", false, false, 0, 0, 0},
    {0x0A, "fuelPressure",    false, false, 0, 0, 0},
    // ── EMISE ───────────────────────────────────────────────────────
    {0x21, "milDistance",     false, false, 0, 0, 0},
    {0x31, "distSinceClr",    false, false, 0, 0, 0},
    {0x14, "o2Voltage",       false, false, 0, 0, 0},
    {0x3C, "catalystTemp",    false, false, 0, 0, 0},
    {0x33, "barometric",      false, false, 0, 0, 0},
    // ── ELEKTRO / HEV ───────────────────────────────────────────────
    {0x42, "systemVoltage",   false, false, 0, 0, 0},
    {0x5B, "hvBatterySoc",    false, false, 0, 0, 0},
    {0x59, "fuelRailPress",   false, false, 0, 0, 0},
    {0x9C, "hvBatteryTemp",   false, false, 0, 0, 0},
    {0x9D, "hvBatteryVolt",   false, false, 0, 0, 0},
    {0x9E, "hvBatteryCurr",   false, false, 0, 0, 0},
};
const uint8_t PID_COUNT = sizeof(pidList) / sizeof(pidList[0]);

// ── Stav ─────────────────────────────────────────────────────────────
bool          scanning    = false;
bool          looping     = false;
uint8_t       loopIndex   = 0;
unsigned long lastRequest  = 0;
unsigned long lastCanLedOn = 0;
String        inputBuffer  = "";

// ═══════════════════════════════════════════════════════════════════════
//  OBD FUNKCE 
// ═══════════════════════════════════════════════════════════════════════

void sendOBDRequest(uint8_t pid) {
    CANFDMessage frame;
    frame.id      = 0x7DF;
    frame.len     = 8;
    frame.data[0] = 0x02;
    frame.data[1] = 0x01;
    frame.data[2] = pid;
    frame.data[3] = 0x00;
    frame.data[4] = 0x00;
    frame.data[5] = 0x00;
    frame.data[6] = 0x00;
    frame.data[7] = 0x00;
    can.tryToSend(frame);
}

// Dekódování 
float decodePID(uint8_t pid, uint8_t a, uint8_t b) {
    switch (pid) {
        case 0x04: return (a * 100.0) / 255.0;
        case 0x05: return a - 40.0;
        case 0x06: return (a - 128.0) * 100.0 / 128.0;
        case 0x07: return (a - 128.0) * 100.0 / 128.0;
        case 0x0A: return a * 3.0;
        case 0x0B: return a;
        case 0x0C: return ((a * 256.0) + b) / 4.0;
        case 0x0D: return a;
        case 0x0E: return (a / 2.0) - 64.0;
        case 0x0F: return a - 40.0;
        case 0x10: return ((a * 256.0) + b) / 100.0;
        case 0x11: return (a * 100.0) / 255.0;
        case 0x1F: return (a * 256.0) + b;
        case 0x21: return (a * 256.0) + b;
        case 0x2F: return (a * 100.0) / 255.0;
        case 0x31: return (a * 256.0) + b;
        case 0x33: return a;
        case 0x3C: return ((a * 256.0) + b) / 10.0 - 40.0;
        case 0x42: return ((a * 256.0) + b) / 1000.0;
        case 0x43: return (a * 100.0) / 255.0;
        case 0x46: return a - 40.0;
        case 0x4D: return (a * 256.0) + b;
        case 0x59: return ((a * 256.0) + b) * 10.0;
        case 0x5B: return (a * 100.0) / 255.0;
        case 0x5C: return a - 40.0;
        case 0x5E: return ((a * 256.0) + b) / 20.0;
        case 0x9C: return a - 40.0;
        case 0x9D: return ((a * 256.0) + b) / 10.0;
        case 0x9E: return ((a * 256.0) + b) / 10.0 - 3276.8;
        default:   return a;
    }
}

// Zpracování scan bitmask
void processSupportedPIDs(uint8_t basePid, uint8_t a, uint8_t b, uint8_t c, uint8_t d) {
    uint32_t bitmask = ((uint32_t)a << 24) | ((uint32_t)b << 16) | ((uint32_t)c << 8) | d;
    for (uint8_t i = 0; i < 32; i++) {
        if (bitmask & (1UL << (31 - i))) {
            uint8_t supportedPid = basePid + i + 1;
            for (uint8_t j = 0; j < PID_COUNT; j++) {
                if (pidList[j].pid == supportedPid) {
                    pidList[j].supported = true;
                }
            }
        }
    }
}
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
